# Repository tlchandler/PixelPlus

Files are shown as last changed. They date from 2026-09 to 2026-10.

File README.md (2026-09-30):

# PixelPlus

**A modern show player for Raspberry Pi pixel controllers.** PixelPlus plays the
Christmas (or any) light shows you design in [xLights](https://github.com/xLightsSequencer/xLights),
on Raspberry Pi based differential pixel controllers — with an interface built around your
**props**, not channels and universes.

It is a from-scratch replacement for Falcon Player (FPP) for the PixelPlus / Chandler board
family (difftx pHAT, 60-port difftxlarge, diffsmart smart receiver), and also runs on a bare
Pi or in Docker as a show director.

---

## Why PixelPlus

| | |
|---|---|
| **Props, not universes** | Import your xLights layout and every prop shows up by name, wired to its controller, jack, receiver and port — in plain language ("Main Controller › J1 › Front Yard receiver › Port 2 › pixels 51–100"). You never type a start channel. |
| **Configure once, on the leader** | One Pi is the show leader. New controllers appear on their own; click **Adopt** and they receive their props, settings and their slice of every sequence automatically — and stay in sync to within a frame. |
| **Easy to change** | Every setting is edited in place and saved automatically, with Undo. Every change is versioned; **Backups** restore the whole show in one click. |
| **Setup that just works** | Put your Wi-Fi in `pixelplus.txt` on the SD card, use Raspberry Pi Imager's settings, or use the **PixelPlus Imager** app. No Wi-Fi? The Pi opens a `PixelPlus-XXXX` hotspot with a friendly Wi-Fi picker. |
| **Made for the yard at night** | Dark "studio" interface that works beautifully on a phone: big touch targets, live preview of your whole display, test and fault-find any prop from where you stand. |
| **No artificial limits** | Up to ~1600 pixels per output at 20 fps (800 at 40 fps) on every output, 60 outputs on the difftxlarge. |

## Features

- **Live dashboard** — now playing, next show countdown, pre-show health check, controller
  health, temperatures, 12 V voltage/current (difftxlarge), song requests.
- **Props** — grid and list views with live mini-previews, groups, bulk edit, drag-to-reorder
  daisy chains, reverse runs, dark spacer pixels, color order, brightness and color correction
  per port, power estimates against your receiver fuses.
- **Test & fault finder** — solid/chase/count/walk patterns on any prop or port; a guided
  "is it lit?" binary search finds the first bad pixel in a handful of taps.
- **Layout** — a live 2D picture of your whole display while the show plays.
- **Sequences & audio** — drag-and-drop upload, automatic song matching, volume leveling,
  thumbnails; plays xLights `.fseq` v1/v2 (zstd, zlib, sparse).
- **Playlists** — songs, DJ clips, looks, pauses and commands; intro/outro, shuffle, repeat,
  crossfades.
- **Schedule** — show windows by day and season, times relative to sunset, special nights
  that take over, idle looks between shows, a neighbor-friendly volume curfew.
- **DJ Studio** — radio-style announcements with Kokoro voices (Nick & Holly included, or
  blend your own), multi-voice scripts, hype levels, live info ("{days until Christmas}",
  "next up: {song}") re-rendered at showtime. Renders on a Pi 4/5 or right in your browser.
- **Effects** — 13 built-in effects and 15 ready-made looks for idle time and quick tests,
  identical on every controller.
- **Games** — visitors play Super Mario Bros. (or an NES arcade) on your pixel matrix using
  their phone as the controller, with QR invites flashed on the matrix.
- **Song requests** — a public page (with QR code and printable yard sign) where visitors pick
  the next song.
- **Alerts & integrations** — email and push (ntfy) alerts, MQTT with Home Assistant
  discovery, physical button triggers, OLED status screen.
- **Only what you use** — Settings → Features turns optional parts on and off (presets:
  Essentials, Everything, Custom), so menus and pages show just what this display uses.
  Nothing is deleted; turned-off features stop their background work and their playlist items
  are skipped.
- **Secure by default** — optional password, per-controller keys with signed cluster
  traffic, hardened against hostile uploads and cross-site attacks.

**New in this release**

- **Light shows from music** — beat, tempo and energy analysis builds a show for your props
  in one click, in six styles; preview any sequence on your phone without touching the lights.
- **Sync lights to sound** — your phone's camera and microphone measure the audio delay; a
  built-in certificate authority gives phones the HTTPS they need, with a one-page trust guide.
- **Countdown to showtime** — a matrix countdown with the first song starting exactly on the
  scheduled minute, on every controller.
- **Map my yard** — film the house with your phone and PixelPlus finds where each prop is and
  which runs are swapped or reversed; plus a pixel-count check and a guided receiver wizard.
- **Smart playlists** — tags, rules and nightly rotation pick tonight's songs without repeats.
- **Seasons** — keep Halloween and Christmas shows side by side and switch by date.
- **Power limiter** — keeps every fuse and supply within its rating on every controller, plus
  late-night dimming.
- **Nightly report** — how last night went, every morning, by email or push.
- **Upload from xLights** — FPP Connect compatible, or a drop folder.
- **Sensors and surprises** — ESP32 motion, button and beam sensors set off effects layered
  over the song that's playing.
- **Remote access** — Tailscale or Cloudflare Tunnel without port forwarding; only the request
  page and games go public, with per-visitor limits and an alert on every remote sign-in.
- **Fleet care** — signed updates for every controller at once with automatic rollback, and
  one-step replacement of a dead controller or leader from an encrypted transfer file.

## Getting started

1. **Make an SD card** — see [docs/INSTALL.md](docs/INSTALL.md) (PixelPlus Imager,
   Raspberry Pi Imager, or any writer + `pixelplus.txt`).
2. **Open** `http://pixelplus.local` (or the name you chose) and follow the setup wizard.
3. **Import** your xLights layout, **upload** sequences, **build** a playlist and **schedule** it.

Running the leader on a PC or NAS: see [docker/README.md](docker/README.md).

## Hardware

| Board | Outputs | Notes |
|---|---|---|
| **difftx** (PixelPlus pHAT) | 4 on one RJ45 | Pi Zero 2 W outline. Rev D needs a 4/5-swapped patch lead on port 3 (PixelPlus warns you). |
| **difftxlarge** | 60 on 15 RJ45 | 3 latch banks, INA226 power monitor, 2× LM75, DS3231 RTC, optional OLED. |
| **diffsmart** | 4 direct | Runs PixelPlus in standalone (PI) mode; set SW1 to **PI**. |
| **diffrx** | receiver | Passive 4-port differential receiver (no Pi). |

Supported Pis: Zero 2 W, 3, 4, 5 (64-bit Raspberry Pi OS Bookworm or Trixie). Pixel output
uses the Pi's DPI peripheral with an original WS281x encoder — see
[crates/pixelplus-output/DESIGN.md](crates/pixelplus-output/DESIGN.md), including a
**bring-up checklist** for first hardware tests.

## Repository layout

```
crates/pixelplus-core     show model, fseq, xLights import, mapping, effects, schedule
crates/pixelplus-output   DPI WS281x encoder (direct + latched), output backends
crates/pixelplus-hw       board detection, EEPROM, sensors, RTC, OLED, GPIO
crates/pixelplus-daemon   pixelplusd: API, playback engine, scheduler, cluster, services
crates/pixelplus-cli      pixelplus: detect, eeprom, test-output, config-txt, doctor
web/                      SvelteKit web interface (demo mode: add ?mock=1)
tts/                      Kokoro DJ voice service
games/                    phone-controlled matrix games
image/ packaging/ docker/ Raspberry Pi image, Debian package, Docker
imager/                   PixelPlus Imager desktop app
docs/                     ARCHITECTURE, INSTALL, BUILDING
scripts/                  dev-cluster.sh (local leader + 2 followers), e2e tests
```

## Development

See [docs/BUILDING.md](docs/BUILDING.md). Quick start:

```sh
cargo test --workspace                  # Rust
cd web && pnpm install && pnpm dev      # UI (demo mode when no daemon is running)
scripts/dev-cluster.sh start --fresh    # a real leader + 2 followers on your PC
node scripts/e2e/run.mjs                # the full end-to-end scenario
```

The design authority is [docs/ARCHITECTURE.md](docs/ARCHITECTURE.md) (multi-controller timing:
§7.4); board-level timing notes for future hardware revisions are in
[docs/HARDWARE-NOTES.md](docs/HARDWARE-NOTES.md).

## License

PixelPlus is free software under the [GNU General Public License v3.0 or later](LICENSE).
It contains no code from FPP's CC-BY-ND licensed components.
Nintendo and Super Mario Bros. are trademarks of Nintendo; no Nintendo code or ROMs are included.

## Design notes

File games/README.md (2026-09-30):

# PixelPlus Games

Let people walking by your Christmas display play **Super Mario Bros. on your pixel matrix**,
using their phone as the controller. A sidecar service for `pixelplusd`, ported from
[tlchandler/fpp-mariobros](https://github.com/tlchandler/fpp-mariobros).

* During the show, the matrix flashes your URL (text and/or a QR code) every few minutes.
* A visitor opens it and gets an NES-style gamepad that says **PRESS START TO BEGIN**.
* On START, the show pauses, a **random level** plays on the matrix for **60 seconds** with the
  game's **music and sound effects on your show audio**, then the show resumes exactly where it was.
* A **cooldown** then keeps the matrix on the show for a while: no invites, no new games.
* Mario wears a **Santa hat**.
* Optional **Arcade mode**: a full-time NES emulator. The matrix lists every game you uploaded
  (with a scroll bar), visitors take turns picking and playing any of them.

Everything is configured in the PixelPlus web UI: the **Games** page.

## What you need

* PixelPlus on the leader that drives the matrix.
* A **matrix prop** (Props → a prop of kind *matrix* with its grid). xLights imports fill in the
  grid automatically; it can also be edited in the prop drawer.
* Your own backup of **Super Mario Bros.** as a `.nes` file (not included, and never sent to
  visitors — the game runs on the Pi; phones only send button presses). Arcade mode lists every
  `.nes` file you upload.
* A way for phones on the street to reach the controller page (see below).

## Install

PixelPlus images ship with the games service installed. To add it by hand (Raspberry Pi OS /
Debian), from a checkout of the repository:

```sh
sudo games/install.sh
```

It installs `libretro-nestopia` (the NES emulator), `python3-numpy`, `python3-qrcode` and
`alsa-utils` with apt, copies the program to `/usr/lib/pixelplus/games`, creates
`/var/lib/pixelplus/games/roms/` and enables `pixelplus-games.service`
(`--help` lists the options). Logs: `journalctl -u pixelplus-games -f`.

The service runs as the unprivileged `pixelplus` user (the same user as `pixelplusd`, member
of `audio` for game sound), with the unit the `pixelplus` package ships
(`packaging/systemd/pixelplus-games.service`, identical to `games/pixelplus-games.service`).
It writes frames into the prop's overlay buffer `/dev/shm/pixelplus-overlay-<prop>` (created
by pixelplusd, mode 0660) and listens on the control socket `/run/pixelplus/games.sock`
(`/run/pixelplus` is created by tmpfiles.d, owned by `pixelplus`).

Then open the **Games** page in PixelPlus:

1. Upload your Super Mario Bros. ROM (stored as `/var/lib/pixelplus/games/roms/smb.nes`) and,
   for Arcade mode, any other `.nes` games (stored next to it).
2. Pick your **matrix prop** and press **Test pattern**: you should see a blue border, a red
   top-left corner, a green top-right corner and `MARIO 80X40` centred. If the corners are
   swapped, fix the prop's matrix orientation (start corner / direction) in the Props page.
3. Turn **Games** on, then open `http://<pi-address>:8088` on your phone (same Wi-Fi) and play a
   round.
4. Set the **Public URL** and **Show the invite every** (minutes; 0 = only when a playlist runs
   the `games.invite` command).

### Letting phones on the street reach it

Visitors are on mobile data, so the page must be reachable from the internet. Expose **only the
controller port** (default 8088), never PixelPlus's own web interface on port 80. The controller
page has no login by design: anyone who can reach it can queue for a turn, and that is all it can
do.

* **Cloudflare Tunnel** (recommended, free, no router changes, works with WebSockets and gives you
  HTTPS): install `cloudflared` on the Pi or another machine on your network and route a
  hostname such as `mario.yourdomain.com` to `http://<pi-address>:8088`. This is a third-party
  service you set up yourself; PixelPlus does not install it.
* **Port forward** on your router from an external port to `<pi-address>:8088`, plus a dynamic DNS
  name. Simpler, but plain HTTP and it puts your home IP in the URL.
* **Guest Wi-Fi** near the display (with the URL as `http://<pi-address>:8088`) if you'd rather
  not touch the internet at all.

What the controller port does to stay up with the whole internet able to reach it: only `/`,
`/ws` and `/healthz` exist; WebSocket messages are capped at 4 KiB and parsed defensively; a phone
may send about 60 messages a second (bursts to 120) and is disconnected if it keeps flooding; a
connection that stays silent for 2 minutes is closed (the page pings every 20 s); and one address
may hold at most 16 connections (300 in all). Behind Cloudflare Tunnel or another reverse proxy on
the Pi or the LAN, the visitor's address is taken from `CF-Connecting-IP` / `X-Forwarded-For`;
those headers are ignored on connections from the internet.

Short URLs read best on an 80×40 matrix (about 20 characters fit; longer ones scroll).

## Settings (the Games page)

Stored in the show as `settings.games` (`GameSettings` in `pixelplus-core`); changes apply live.

| Setting (`show.json` key) | Default | Notes |
|---|---|---|
| Games (`enabled`) | off | Master switch. Opens the controller port; off closes it and the arcade. |
| Controller port (`port`) | 8088 | |
| Matrix (`matrixPropId`) | — | Any prop with a matrix grid. If unset and the show has exactly one matrix prop, that one is used. |
| Game length (`gameSeconds`) | 60 s | 10–600. |
| Cooldown after a game (`cooldownMinutes`) | 5 min | No invites and no games during it; phones count down. |
| Levels (`levels`) | all | Or e.g. `1-1,1-2,4-1`; one is picked at random. |
| Games allowed (`playWindow`) | during the show | `duringShow`: while a show plays, is paused, or inside a schedule window. Or `anytime`. |
| Pause the show during a game (`pauseShow`) | on | Pauses the player and resumes it afterwards. |
| Santa hat on Mario (`santaHat`) | on | |
| Arcade mode (`arcadeMode`) | off | See below. |
| Turn length (`arcadeMinutes`) | 0 (unlimited) | Minutes; 0 = until the player leaves or goes idle. |
| End a turn after idle (`arcadeIdleSeconds`) | 600 s | 0 = never. |
| Public URL (`publicUrl`) | — | What the invite shows. |
| Show the invite every (`inviteEveryMinutes`) | 5 min | 0 = only via the playlist command. |
| Invite style (`inviteStyle`) | text | `text`, `qr`, or `alternate`. |
| Flashes each time (`inviteFlashes`) | 3 | |
| URL text colour (`inviteColor`) | red | |
| Picture fit (`scaleMode`) | fit | `fit` keeps Mario's proportions (black bars left/right); `stretch` fills. |
| Matrix frame rate (`outputFps`) | 40 fps | 20 or 40. The game itself always runs at 60. |
| Brightness / game volume (`brightness`, `volume`) | 100% / 80% | Game volume scales the game's own sound. |
| Crop (`crop`) | 8, 32, 256, 224 | Part of the NES screen shown in Mario mode (drops the score bar). |

The game's audio goes to the show's audio device (`settings.audio.device`). Use a device that
can be shared (`default`, a `dmix` or PipeWire device) if pixelplusd keeps the card open while
the show is paused.

A queued visitor has 20 s to press START when their turn comes (`turnTimeoutSeconds`, if the show
ever carries it). For unusual setups, environment variables in the service override the rest:
`PIXELPLUS_API` (default `http://127.0.0.1`), `PIXELPLUS_DATA_DIR`, `PIXELPLUS_GAMES_SOCKET`,
`PIXELPLUS_NES_CORE` (a specific libretro core), `PIXELPLUS_NES_CORE_OPTIONS`
(`key=value;key=value`), `PIXELPLUS_GAMES_DEBUG=1`.

### Playlist, schedule and trigger commands

* **`games.invite`** (`args: {flashes?, style?}`): flash the URL / QR now. Ignored during a game,
  the arcade or the cooldown.
* **`games.stop`**: end the current game or arcade turn.

## How a turn works

1. The phone connects over a WebSocket and shows **PRESS START TO BEGIN**.
2. START: if nobody is playing the visitor plays now, otherwise they join a line and their phone
   shows their place. When it's their turn their phone buzzes and they have 20 s to press START.
3. The show is paused, the overlay is switched on for the matrix prop, `WORLD 4-2` shows on the
   matrix while the emulator boots straight into that level (the level is chosen by writing the
   game's World/Level/Area bytes at the title menu, exactly like the game's own continue feature).
4. The game runs at the NES's 60 fps; the matrix gets 20 or 40 of those frames per second. START
   and SELECT are disabled so nobody can pause the matrix, lives are topped up, and the last ten
   seconds count down in the margin.
5. `TIME UP` and the score show, the overlay is switched off, the show resumes where it stopped
   (unless someone stopped it meanwhile), and the cooldown starts. If the player closes the page,
   their game ends after 10 s.

### The phone controller

* The pad fills the phone's screen, with the D-pad against the left edge and B/A against the right,
  where thumbs rest. Sideways gives the biggest buttons; upright works too.
* **Full screen** (top-right corner): on Android and desktop browsers it hides the browser bars and,
  on Android, locks the phone to landscape. iPhone Safari can't make a web page full screen, so on an
  iPhone the button explains **Share → Add to Home Screen** instead: opened from that icon, the
  controller fills the whole screen.
* One controller per phone: if the same browser opens the page a second time (another tab, or the
  home-screen icon), the older copy says so and waits for a tap instead of fighting over the turn.
* A keyboard works too: arrows/WASD, X/K = A, Z/J = B, Enter = START, right Shift = SELECT.

## Arcade mode

Turn on **Arcade mode** (with Games on) and the Pi becomes a full-time NES arcade:

* A playing show is stopped, and kept stopped: if the scheduler starts it, it is stopped again
  within a few seconds. Turn Arcade mode off to give the matrix back, then start your show as usual
  (it is not restarted automatically).
* The matrix shows **PICK A GAME** and the list of uploaded games, with a highlight bar, a scroll
  bar and scrolling for long names. Up/Down move (hold to repeat), Left/Right page, A or START plays.
* **Hold SELECT + START + B + A for 2 seconds** to leave a game and go back to the list.
* Turns (length and idle timeout configurable) and the line work as in Mario mode. Invites are off.

## Performance

The emulator has to finish every frame in under 16.7 ms. The service does what it can: the matrix
only gets 20 or 40 frames a second, frames that won't be shown aren't copied, and scaling is a
single precomputed gather. Measure on the Pi itself, ideally while the show is running:

```sh
cd /usr/lib/pixelplus/games
python3 -m pixelplus_games.benchmark /var/lib/pixelplus/games/roms/smb.nes 80x40
```

On a 2.1 GHz Xeon it reports ~0.4 ms to emulate and ~0.3 ms to scale a frame (≈3% of a core).
A Pi 4 is comfortable; on slower boards set the matrix frame rate to 20. The show is paused during
a game, which frees up CPU.

## How it talks to PixelPlus

The service runs next to pixelplusd, as its own user `pixelplus-games` (group
`pixelplus-overlay`, shared with pixelplusd), and talks to it over loopback. Every request
carries `X-PixelPlus-Local: <token>` — the random token pixelplusd writes to
`/run/pixelplus/local-token` at startup (`PIXELPLUS_LOCAL_TOKEN_FILE` overrides the path; the
file is re-read after a 401) — and `X-PixelPlus-Request: 1`. pixelplusd accepts the token only
from 127.0.0.1 / ::1, never through a proxy, and only for the calls below; the show it returns
has its passwords redacted. The control socket is `/run/pixelplus-games/games.sock`, and of the
data directory the service only sees `games/`.

| Call | Use |
|---|---|
| `GET /api/v1/show` | `settings.games`, `settings.audio.device` and the matrix prop's `matrix: {width, height, pixelMap}`. Refetched on every `{type:"show"}` message from `/api/v1/ws` (every 5 s if the WebSocket is down, every 60 s regardless). |
| `GET /api/v1/player` | `state` (and `scheduleEntry`) when no `status` message arrived for 5 s. |
| `POST /api/v1/player/pause`, `/player/resume`, `/player/stop` | Pause/resume around a Mario game; stop (and keep stopped) for the arcade. |
| `POST /api/v1/overlay/:propId/open` → `{shm, width, height}` | Shared-memory frame buffer: 12-byte header (width, height, flags as native-endian u32) + RGB row-major from the top-left. Each frame sets flags bit 0. |
| `PUT /api/v1/overlay/:propId/frame` | Fallback when the shared memory can't be used: raw RGB, width×height×3 bytes. |
| `POST /api/v1/overlay/:propId` `{enabled}` | On while a game, invite or test pattern is shown; off afterwards (and at startup, in case a previous run died). |

pixelplusd reaches the service through its control socket, `/run/pixelplus/games.sock`: one
JSON object per line each way, one request per connection.

| Request | Reply |
|---|---|
| `{"cmd":"status"}` | `{ok, enabled, running, arcade, queueLength, cooldownS, model:{width,height}\|null, player?:{phase, level?, score?, remaining?, game?}, lastError?, propId, clients, port, showState, busy, unavailable}` |
| `{"cmd":"invite","flashes":3,"style":"qr"}` | `{ok}` or `{ok:false, error}`. `flashes`/`style` optional (settings otherwise); `style` is `text`, `qr` or `alternate`; `url` and `force` (ignore cooldown / games off) also accepted. |
| `{"cmd":"stop"}` | `{ok, stopped}` |
| `{"cmd":"test"}` | `{ok}` or `{ok:false, error}`: test pattern for 6 s. |
| `{"cmd":"reload"}` | `{ok}`: refetch the show now. |

From a shell: `python3 -m pixelplus_games.ctl status|invite [flashes] [style]|stop|test|reload`.

## Development

No Pi needed. The tests use `tests/fake_pixelplus.py`, a stand-in for pixelplusd's API (it also
creates the overlay shared memory and serves `/api/v1/ws`), and a tiny homebrew ROM built on the
fly (no commercial ROM). Emulator tests are skipped when no libretro NES core is installed.

```sh
python3 -m unittest discover -s games/tests       # from the repository root
```

To run the whole service against the fake:

```sh
python3 games/tests/fake_pixelplus.py 18080 80 40 &
cd games && PIXELPLUS_API=http://127.0.0.1:18080 PIXELPLUS_DATA_DIR=/tmp/pp \
    PIXELPLUS_GAMES_SOCKET=/tmp/pp/games.sock python3 -m pixelplus_games
# open http://localhost:8088 ; put a ROM at /tmp/pp/games/roms/smb.nes
```

## Files

```
pixelplus_games/     the service (Python 3, standard library + numpy)
  server.py          HTTP/WebSocket server, player line, cooldown, invites, arcade turns, control socket
  api.py             pixelplusd HTTP client
  events.py          pixelplusd WebSocket listener (live settings and show state)
  config.py          paths, and settings.games from the show
  game.py            game sessions: pause/resume the show, the real-time emulation loop
  libretro.py        minimal ctypes frontend for a libretro NES core
  smb.py             Super Mario Bros. RAM map and level select
  hat.py             the Santa hat
  arcade.py          arcade game list
  display.py         scaling and writing to the overlay shared memory
  invite.py          URL / QR invite and test pattern
  font.py            3x5 pixel font
  audio.py           game sound through aplay
  benchmark.py       performance check
  ctl.py             control socket client
  www/controller.html  the phone gamepad
install.sh, pixelplus-games.service, requirements.txt
tests/               unit and integration tests, fake pixelplusd
```

Nintendo, Super Mario Bros. and NES are trademarks of Nintendo. This project is not affiliated
with Nintendo and contains no Nintendo code or graphics.

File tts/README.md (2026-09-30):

# PixelPlus TTS (`pixelplus_tts`)

On-device DJ voices for PixelPlus: a small loopback HTTP service (`127.0.0.1:7081`) that
renders multi-voice DJ clips with [Kokoro](https://github.com/hexgrad/kokoro) (82M, Apache-2.0)
through [kokoro-onnx](https://github.com/thewh1teagle/kokoro-onnx). It is a port of
[tlchandler/fpp-voices](https://github.com/tlchandler/fpp-voices), and it keeps that
project's tested sound:

* **Nick** (30% `am_echo` + 30% `am_fenrir` + 40% `am_puck`) and **Holly** (50% `af_heart` + 50% `af_kore`),
  and any custom blend (a weighted average of Kokoro style vectors).
* **Energy and hype that build to the end.** The punchline lands about 2–3 semitones above the lead-in,
  with wider pitch swings, a swell of about 2.5 dB, a soft pitch ceiling and a stretch for Holly. With
  praat-parselmouth installed it uses Praat PSOLA with the same algorithm and constants as fpp-voices;
  on a Raspberry Pi (no parselmouth wheels, see [Platforms](#platforms)) a simpler method gives the
  same lift, stretch and swell without the widened swings.
* Radio processing: highpass, per-voice EQ, presence for energetic lines, a de-esser and a compressor.
* Linear loudness normalization to **-16 LUFS** by default, with a true-peak-safe limiter.
* Pronunciation fixes (about 100 built in, plus the show's own list) and exact IPA overrides (`/noʊˈɛl/`).
* An optional music bed, ducked under the speech.

A check that the port is faithful: rendering `examples/show_intro.txt` with fpp-voices' `dj_voice.py`
and with this package, both at -16 LUFS, gives the same loudness (-16.0 / -16.0), the same length to
0.1 ms, and waveform correlation ≥0.99 per 2-second segment.

Runs on **Pi 4 / Pi 5 (64-bit OS) and Docker/x86**. **Pi Zero 2 W and Pi 3 use browser mode**
(`web/src/lib/tts-browser`, kokoro-js in the user's browser), because on-device renders there
would be many times slower than real time and the model barely fits in 512 MB–1 GB RAM.

---

## Platforms

Wheels on PyPI (checked 2026-09; `https://pypi.org/pypi/<package>/json`):

| Package | Linux x86_64 | Linux aarch64 (Pi OS Bookworm 3.11 / Trixie 3.13) |
|---|---|---|
| onnxruntime 1.30 | cp311–cp314 | cp311–cp314 (`manylinux_2_28`) |
| kokoro-onnx 0.6.1 | pure Python | pure Python (+ espeakng-loader `manylinux_2_28_aarch64`) |
| numpy 2.x | yes | yes |
| praat-parselmouth 0.4.7 | cp37–cp314 | **none** (source only: C++ build, hours under qemu) |

So `praat-parselmouth` is optional (`pip install '.[psola]'`, or it is tried automatically by
`install.sh`, the image build and the Docker image with `--only-binary`). Without it,
`pixelplus_tts/prosody.py` does the energy/hype prosody: the line is raised by the voice's energy
pitch, the punchline additionally by its lift (capped), slowed by its stretch and swollen by its
boost, with ffmpeg's `rubberband` filter (formants preserved) or, without it, a numpy phase vocoder.
`GET /health` reports the method in use as `prosody`: `psola`, `rubberband` or `basic`.

## Install

```bash
sudo ./install.sh                     # /opt/pixelplus-tts/venv, model into /var/lib/pixelplus/tts/models,
                                      # systemd unit pixelplus-tts.service (enabled + started)
sudo ./install.sh --variant fp16      # choose the model variant (see below)
sudo ./install.sh --no-service        # Docker / image builds
./install.sh --prefix ~/pp --data-dir ~/pp-data --no-service --no-apt   # unprivileged dev install
```

The script needs Python 3.10–3.13 (onnxruntime and kokoro-onnx don't support 3.14 yet). When run
as root it installs `ffmpeg` and `python3-venv` with apt if they're missing. If there's no system
ffmpeg, it installs the `bundled-ffmpeg` extra (imageio-ffmpeg) instead. Model files are
downloaded from the kokoro-onnx GitHub release (`model-files-v1.0`). Downloads resume from
`<file>.part` over HTTP Range, and each file is **sha256-verified** before it's moved into place.
Re-running the script is safe. For offline image builds, use `--models-mirror URL` or
`python -m pixelplus_tts download-models --base-url`.

Dev: `pip install -e '.[test,bundled-ffmpeg]' && pytest`. The integration tests run when the model is present in
`$PIXELPLUS_TTS_MODELS_DIR` (or `$PIXELPLUS_DATA_DIR/tts/models`) and are skipped otherwise.

### Model variant (per device RAM)

| Variant | File | Size | Resident after load | Peak while rendering | Speed (x86, measured) |
|---|---|---|---|---|---|
| **fp32** (default) | `kokoro-v1.0.onnx` | 310 MB | 455 MB | ~730 MB | RTF 0.34–0.39 model / 0.42–0.53 full pipeline |
| fp16 | `kokoro-v1.0.fp16.onnx` | 169 MB | 323 MB | ~680 MB | 0.27 model / 0.57–0.66 pipeline (varies) |
| int8 | `kokoro-v1.0.int8.onnx` | 88 MB | 193 MB | ~630 MB | **1.4–1.9 (3–4x slower)** |

`auto` picks **fp32** unless the board has < 1.5 GB RAM (Pi 4 1 GB), which gets **int8**.
The reasoning:

* fp32 is the reference quality, and all of fpp-voices' tuning was done with it.
* int8 (dynamic quantization) saves resident RAM but only about 100 MB of *peak* RAM. It is 3–4x slower
  on x86 because of the ConvInteger/MatMulInteger kernels, and it has no speed advantage on
  Cortex-A72 either (no `sdot`).
* On a Pi 4 with 2 GB RAM, fp32's ~730 MB peak fits alongside pixelplusd, and the model is unloaded
  after the idle time.
* fp16 is fast on CPUs with native fp16 or bf16 support. It is worth trying on a Pi 5 (Cortex-A76 has fp16
  arithmetic): `PIXELPLUS_TTS_MODEL=fp16` in `/etc/default/pixelplus-tts`, then measure with
  `python -m pixelplus_tts bench`.

Override the choice with `PIXELPLUS_TTS_MODEL=fp32|fp16|int8`, or with `install.sh --variant` (which
downloads that file). If `auto` picks a file that isn't present, the service uses whichever
variant is installed.

### Performance

Measured on this dev box (Xeon @2.1 GHz, 3 onnxruntime threads, fp32). A 12 s announcement takes
5–6 s through the whole pipeline (Kokoro, PSOLA energy, ffmpeg radio chain, loudness, MP3), so
RTF ≈ 0.45. The model loads in 1.1 s. A two-line Nick+Holly clip (4.9 s of audio) renders in 3.0 s.

These Pi figures are **estimates**, scaled from the x86 numbers and typical onnxruntime ARM
throughput; confirm them on the device with `python -m pixelplus_tts bench`:

| Device | Expected RTF (fp32) | A 10 s clip renders in | Mode |
|---|---|---|---|
| x86 desktop / NAS (Docker) | 0.2–0.5 | 2–5 s | device |
| Pi 5 (4× A76 2.4 GHz) | ~1.0–1.5 | ~10–15 s | device |
| Pi 4 (4× A72 1.5–1.8 GHz) | ~3–4 | ~30–40 s | device (render ahead of time) |
| Pi 3 / Pi Zero 2 W | ≫5, RAM-limited | minutes | **browser** |

Memory: the service uses about 36 MB while idle with no model loaded, about 730 MB at peak while rendering (fp32),
and about 155 MB after an idle unload (the onnxruntime and Praat libraries stay mapped; the model memory is
returned to the OS with `malloc_trim`). By default the model unloads after `PIXELPLUS_TTS_IDLE_MIN=10` minutes.
The unit runs at `Nice=10`, `CPUSchedulingPolicy=batch` and `IOSchedulingClass=idle`, and uses cores−1 threads,
so renders never starve the light output thread.

---

## HTTP API (`127.0.0.1:7081`, JSON, camelCase)

Errors use the pixelplusd error shape, `{"error": {"code", "message"}}`:

* 400 for `bad_request`, `unknown_voice`, `parse_error`, `forbidden_path`, `not_found` and `too_large`.
* 503 for `model_missing` and `busy` (four requests are already queued).
* 500 for `render_failed`.

Only one render runs at a time; other requests wait in a queue.

### `GET /health`
```json
{"ok": true, "version": "0.1.0", "modelLoaded": false, "modelAvailable": true, "device": "cpu",
 "modelVariant": "fp32", "threads": 3, "idleUnloadMinutes": 10, "renders": 0, "uptimeS": 12}
```
`modelAvailable: false` means the model files aren't downloaded, and renders return 503 `model_missing`.

### `GET /voices`
```json
{"base": [{"id": "af_heart", "name": "Heart", "language": "en-us", "gender": "female", "grade": "A"}, ...54 voices],
 "presets": [{"id": "nick", "name": "Nick", "description": "Male DJ - warm, upbeat, classic radio baritone",
              "blend": {"am_echo": 0.3, "am_fenrir": 0.3, "am_puck": 0.4}, "speed": 1.05, "lang": "en-us",
              "defaultEnergy": 0.4, "eq": "equalizer=f=150:t=q:w=1.0:g=2.5,equalizer=f=3200:t=q:w=1.2:g=2",
              "energy": {"pitch": 1.5, "range": 1.5, "speed": 1.0, "stretch": 1.0, "boost": 3, "lift": 3,
                         "ceiling": 3, "maxLift": 9}},
             {"id": "holly", ...}]}
```
`presets` are `DjVoice` objects that pixelplusd can seed into `show.djVoices`. `grade` is hexgrad's
published grade, given for the English voices only. Non-English voices (es, fr-fr, hi, it, ja, pt-br, cmn) are
best effort: kokoro-onnx phonemizes them with espeak-ng.

### `POST /render` → audio bytes
```jsonc
{
  "lines": [                                   // DjLine[]; voice = id or a DjVoice object
    {"voice": "nick", "text": "Good evening, and welcome to {showName}!", "pauseMs": 0},
    {"voice": "elf",  "text": "Only {daysUntilChristmas} days to go!", "pauseMs": 600, "energy": 1},
    {"voice": {"id": "tmp", "blend": {"af_bella": 0.6, "af_sky": 0.4}}, "text": "Up next, *{nextSong}!*", "energy": 1.5}
  ],
  "voices": [ /* optional DjVoice[] that lines may reference by id or name, e.g. show.djVoices */ ],
  "speed": 1.0,                                // DjClip.speed, 0.5–2.0, multiplies each voice's own speed
  "pronunciations": [{"word": "Griswold", "say": "Griz wold"}, {"word": "Noel", "say": "/noʊˈɛl/"}],
  "builtinPronunciations": true,               // also apply the ~100 built-in fixes (default true)
  "placeholders": {"showName": "the Chandler Family light show", "daysUntilChristmas": 12, "nextSong": "Feliz Navidad"},
  "format": "mp3",                             // mp3 (192k) | wav (s16) | ogg; always 44.1 kHz stereo
  "loudnessLufs": -16,                         // pass ShowSettings.audio.targetLufs
  "fx": true,                                  // radio chain + loudness (false = raw voice)
  "musicBed": {"path": "/var/lib/pixelplus/media/<id>.mp3", "duckDb": 12, "gainDb": -6, "introMs": 1500, "outroMs": 2500},
  "cache": true                                // reuse an identical earlier render (default true)
}
```
The response is `audio/mpeg`, `audio/wav` or `audio/ogg`, with these headers:

* `X-Duration-Ms`: the exact clip length. Store it in `Media.durationMs`.
* `X-Loudness-Lufs`: the measured loudness. Store it in `Media.loudnessLufs`.
* `X-Render-Ms`, `X-Cache: hit|miss` and `X-Model-Variant`.
* `X-Warnings`: a JSON array, for example unresolved placeholders.

Semantics:

* **pauseMs** is the silence *after* a line. `0` means the default 350 ms gap between lines, and no gap after
  the last line. A line with empty `text` is pure silence of `pauseMs`. This reproduces fpp-voices' `[pause N]` timing.
* **energy**: 0 calm, 0.4 normal DJ, 1 hype, 1.5 extra hype. When it's absent, the voice's `defaultEnergy`
  applies. On hype lines the punchline is the text in `*asterisks*`, otherwise the last phrase. Hype lines
  are also leveled up to 1.5 dB above the rest, as in fpp-voices.
* **voice** can be one of these:
  * a preset id, name or alias (`nick`/`male`/`m`/`he`, `holly`/`female`/`f`/`she`);
  * the id or name of an entry in `voices`;
  * a Kokoro id (`af_heart`);
  * an inline DjVoice.

  Blend weights are normalized. A voice without an `energy` block gets a neutral DJ tuning
  (pitch 1.5, range 1.5, lift 2.5, boost 3, ceiling 3, maxLift 8). `eq` may only use audio EQ/dynamics
  ffmpeg filters (such as `equalizer` and `highpass`); anything else is rejected.
* **pronunciations**: whole-word matching. Entries with a capital letter are case-sensitive, lowercase entries
  match any case, and the longest phrase wins. A `/.../` value is exact IPA, spliced into the phonemes.
  User entries override built-ins that have the same word.
* **placeholders**: `{name}` is replaced from the map. An unresolved name is spoken without braces
  ("next Song") and reported in `X-Warnings`. pixelplusd owns the values
  (`DJ_PLACEHOLDERS`: time, date, day, daysUntilChristmas, nextSong, prevSong, showName, temperature,
  sunset, requestName). Write them the way they should be spoken ("December 24th", "5:30 PM").
* **musicBed**: `path` must be under `$PIXELPLUS_DATA_DIR`. The bed is looped or trimmed to
  `introMs + speech + outroMs` and set to `loudnessLufs + gainDb`. Under speech it is ducked by `duckDb`
  (150 ms look-ahead, a hold across word gaps and a 600 ms release), faded in over 0.3 s and faded out over
  the outro. The whole mix is then normalized.
* Output (without a bed) starts with a 250 ms lead-in and ends with a 0.6 s tail, so a player never clips the first word.

### `POST /audition` → audio bytes
`{"voice": "af_heart" | DjVoice, "text"?: string, "energy"?: number, "speed"?: number, "format"?: "mp3"}`.
Without `text` the voice says *"Hi, I'm {name}! Welcome to the show. Now sit back, relax, and enjoy the lights!"*.
Results are always cached on disk. The cache key is a sha256 of the voice's sound-affecting fields, the text and settings,
the model variant and the package version, stored in `$PIXELPLUS_DATA_DIR/tts/cache` (LRU, `PIXELPLUS_TTS_CACHE_MB=200`).
A repeat audition returns in about 0 ms.

### `POST /parse`
`{"script": "nick: Hi!\nholly!!: Merry Christmas!\n[pause 1.0]", "voices"?: DjVoice[]}` →
`{"lines": [{"voice": "nick", "text": "Hi!", "pauseMs": 0}, {"voice": "holly", "text": "Merry Christmas!", "pauseMs": 1000, "energy": 1.5}]}`.
The script format is fpp-voices':

* `voice: text` for a line; `voice!:` means hype (1.0) and `voice!!:` means extra hype (1.5);
* `[pause 1.0]` (seconds; `1.5s` and `500ms` also work) adds silence;
* `# comment` lines are ignored;
* `*punchline*` marks the words hype builds into.

An unknown voice or a line without a colon returns 400 `parse_error` with the line number.
The same parser exists in TypeScript (`web/src/lib/tts-browser/script.ts`).

### `POST /warmup`, `POST /unload`, `GET /pronunciations`
`/warmup` loads the model now; call it about a minute before a dynamic clip is needed. `/unload` frees it.
`/pronunciations` returns the built-in list (`{builtin: [{word, say}]}`) for display in the UI.

---

## CLI (compatible with fpp-voices' `./say`)

```bash
python -m pixelplus_tts say nick "Good evening and welcome to the show!"
python -m pixelplus_tts say holly --hype "Sit back, relax, and enjoy the show!" -o hype.mp3
python -m pixelplus_tts say --script show_intro.txt -o show_intro.mp3 --music-bed bed.mp3
python -m pixelplus_tts say --list
python -m pixelplus_tts parse show_intro.txt          # -> DjLine JSON
python -m pixelplus_tts serve [--port 7081] [--idle-minutes 10] [-v]
python -m pixelplus_tts download-models [--variant auto|fp32|fp16|int8] [--models-dir DIR]
python -m pixelplus_tts bench                          # load time, RTF, RSS on this device
```
`say` options match fpp-voices: `-o`, `--script`, `--speed` (replaces the voice speed), `--energy`, `--hype`,
`--loudness` (default **-16** here, not -14), and `--no-fx`. It also adds `--pronunciations FILE` and `--music-bed FILE`.

## Configuration (environment)

| Variable | Default | |
|---|---|---|
| `PIXELPLUS_DATA_DIR` | `/var/lib/pixelplus` | models in `tts/models`, cache in `tts/cache` |
| `PIXELPLUS_TTS_HOST` / `_PORT` | `127.0.0.1` / `7081` | loopback only |
| `PIXELPLUS_TTS_MODEL` | `auto` | `fp32`, `fp16` or `int8` |
| `PIXELPLUS_TTS_IDLE_MIN` | `10` | unload the model after N idle minutes; 0 = never |
| `PIXELPLUS_TTS_THREADS` | cores − 1 | onnxruntime intra-op threads |
| `PIXELPLUS_TTS_CACHE_MB` | `200` | render and audition cache size; 0 disables it |
| `PIXELPLUS_TTS_MODELS_DIR`, `PIXELPLUS_TTS_CACHE_DIR` | derived | overrides |
| `PIXELPLUS_TTS_ALLOW_ANY_PATH` | off | allow music beds outside the data dir |

## Layout

```
pixelplus_tts/
  server.py    HTTP service (stdlib ThreadingHTTPServer)
  render.py    request validation, per-line chain, pauses, bed, loudness, cache
  engine.py    Kokoro load/idle-unload, blend styles, synthesize a line
  energy.py    energy/hype prosody (fpp-voices), pure helpers + Praat PSOLA
  prosody.py   energy/hype without Praat (rubberband or numpy phase vocoder) for aarch64
  audio.py     ffmpeg chains (in-memory pipes), loudness, ducking
  voices.py    base voice catalog, Nick/Holly presets, DjVoice normalization, blending
  pronounce.py pronunciation rules + IPA splicing
  script.py    script parser
  models.py    variants, per-device choice, resumable sha256-verified download
  data/voices.json, data/pronunciations.txt   (from fpp-voices)
install.sh, pixelplus-tts.service
```

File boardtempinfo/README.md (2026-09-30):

# Christmas PCBs

Each design has its own folder. The top of each folder is the current working copy (open the
`.kicad_pro` there); earlier revisions are frozen under `archive/`.

## Tools

All designs are developed in **KiCad 10.0**, installed at `C:\Program Files\KiCad\10.0\`:

| Binary | Path | Used for |
|---|---|---|
| KiCad | `C:\Program Files\KiCad\10.0\bin\kicad.exe` | opening the projects |
| kicad-cli | `C:\Program Files\KiCad\10.0\bin\kicad-cli.exe` | ERC/DRC, gerber and render export |
| KiCad Python | `C:\Program Files\KiCad\10.0\bin\python.exe` | running the `gen_*.py`, `export_jlc.py`, `verify.py` etc. scripts |

The scripts need KiCad's bundled Python (it provides `pcbnew`), so run them from the design's folder, e.g.

```
"C:\Program Files\KiCad\10.0\bin\python.exe" gen_pcb.py
```

## Designs

| Folder | Board | Current | Archived revisions |
|---|---|---|---|
| `difftx/` | FPP Remote pHAT — RS-422 transmitter on the Pi Zero 2 W outline | rev E (65 x 30 mm). Rev D, the one built, has port 3 reversed: see `CLAUDE.md` | `archive/revA`, `archive/revB`, `archive/revC_66mm`, `archive/revD` |
| `diffrx/` | Chandler 4D/8P Differential Receiver | work after rev C (board and `grid_router.py` changed since the release) | `archive/revB`, `archive/revC_release` |
| `diffsmart/` | Chandler 4D/8P Smart Receiver — diffrx rev C + Pi header, RX/TX mode switch | v1.00 | — |
| `difftxlarge/` | 60-output FPP transmitter — 15 × RJ45 (Falcon differential), 3 latch banks, RTC, power monitor, fan thermostat, line out | rev A (310 × 206 mm, not yet ordered) | — |

Each design's `VERIFICATION.md` has its check record; `jlcpcb/` holds the gerbers, BOM and CPL for ordering.

`repoint_3d_models.py` fixes 3D model paths that point at folders that no longer exist (the parts were first
downloaded under `Documents/jumperless/...`), repointing them at each design's own `jlc/jlc.3dshapes`. Run it
with `--apply`; without it, it only reports.

`_duplicates/` holds files that were byte-identical copies of `difftx/archive/revB` files left at the
top level (`fab/`, `difftx_pcb.pdf`). Safe to delete.

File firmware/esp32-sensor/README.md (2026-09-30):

# PixelPlus ESP32 sensor node

A small Wi-Fi board in the yard that tells your PixelPlus show about motion,
button presses, broken light beams and opened doors — and, optionally, how
much current a receiver's pixel supply draws. PixelPlus turns those into
**surprises**: a short sparkle on the candy canes when someone walks up the
driveway, "Jingle Bells" on the porch when the doorbell button is pressed,
without stopping the song that is playing.

- Boards: **ESP32-C3 DevKitM-1** (recommended), ESP32-S3 DevKitC-1, classic ESP32 DevKit.
- Inputs: up to 8 — PIR motion (HC-SR501, AM312), push buttons, IR break-beam
  pairs, reed/door contacts, and INA219/INA226 current sensors on I²C.
- Protocol: authenticated UDP on port **32422** to the show leader
  (`docs/ARCHITECTURE.md` §7.5, §12.16).

## Build and flash

You need [PlatformIO](https://platformio.org) (`pip install platformio`, or the VS Code extension).

```sh
cd firmware/esp32-sensor
pio run -e esp32c3 -t upload        # ESP32-C3 DevKitM-1 over USB
pio run -e esp32s3 -t upload        # ESP32-S3 DevKitC-1
pio run -e esp32dev -t upload       # classic ESP32 DevKit
pio device monitor                  # log at 115200 baud
pio test -e native                  # protocol and debounce tests on your PC
```

`esp32dev-classic` builds with the stock `espressif32` platform (Arduino-ESP32
2.x) if you can't use the pioarduino platform (Arduino-ESP32 3.x) the other
environments use.

## First start: Wi-Fi setup

1. Power the board. With no Wi-Fi saved it opens a hotspot named
   **PixelPlus-Sensor-XXXX** (the LED blinks **blue**).
2. Join it with your phone. The setup page opens by itself (or browse to
   `http://192.168.4.1`).
3. Pick the Wi-Fi your PixelPlus show uses, enter its password and a name
   ("Driveway", "Porch"), and tap **Save and connect**. The board restarts
   and joins your network (LED: a short **amber** blink every 2 s = waiting to
   be added).
4. In PixelPlus open **Settings → Sensors**. The board shows up under
   *New sensors found*; tap **Add**. The LED goes dark (adopted).
5. Name the inputs, set their pins, then create a trigger in
   **Settings → Triggers**: *When* "Driveway · Motion 1", *do* a surprise.

If the saved Wi-Fi disappears for 2 minutes the hotspot comes back (the
board keeps trying the saved network every minute and leaves the hotspot
once it works again).

### BOOT button

| Press | Effect |
|---|---|
| short (< 2 s) | allow a new show leader to adopt it for 10 minutes (LED blinks **purple**); also allows changing Wi-Fi from its status page |
| hold 10 s | factory reset: forgets Wi-Fi, show leader and settings |

### LED codes

| LED | Meaning |
|---|---|
| slow blue | setup hotspot is open |
| amber blink every 2 s | on Wi-Fi, not added to a show yet |
| fast white | "Identify" pressed in PixelPlus |
| purple | adoption window open (after a short BOOT press) |
| off | working normally (a short white flash on each trigger) |

## Wiring

All inputs are 3.3 V logic. **Never feed 5 V or 12 V into a GPIO.** Default
pins (a fresh node announces these; change them in Settings → Sensors):

| Board | Motion `pir1` | Button `btn1` | Beam | I²C SDA / SCL | BOOT | LED |
|---|---|---|---|---|---|---|
| ESP32-C3 DevKitM-1 | GPIO 4 | GPIO 5 | GPIO 7 | GPIO 1 / GPIO 3 | GPIO 9 | GPIO 8 (RGB) |
| ESP32-S3 DevKitC-1 | GPIO 4 | GPIO 5 | GPIO 6 | GPIO 8 / GPIO 9 | GPIO 0 | GPIO 48 (RGB) |
| ESP32 DevKit | GPIO 27 | GPIO 26 | GPIO 25 | GPIO 21 / GPIO 22 | GPIO 0 | GPIO 2 |

Avoid strapping pins (C3: 2, 8, 9; ESP32: 0, 2, 5, 12, 15) for inputs.

### PIR motion sensor (HC-SR501 or AM312)

```
 HC-SR501 (needs 5 V)            ESP32-C3 DevKitM-1
 ┌──────────────┐
 │ VCC ─────────┼──────────────── 5V
 │ OUT ─────────┼──────────────── GPIO 4      (3.3 V output: safe)
 │ GND ─────────┼──────────────── GND
 └──────────────┘
 AM312 mini PIR: VCC → 3V3 instead of 5V.
```

Kind **motion**, *active low* off. Turn the HC-SR501's "time" pot fully
counter-clockwise (shortest) and use PixelPlus' **hold** setting instead; set
its jumper to "repeat" (H). Outdoors, shade it from the street: car headlights
and warm exhaust trigger PIRs — test at night.

### Push button / doorbell

```
          ┌──── GPIO 5  (internal pull-up)
 button  ─┤
          └──── GND
```

Kind **button**, *active low* **on**. For long cable runs (> 5 m) add a
1 kΩ series resistor and a 100 nF capacitor from the GPIO to GND.

### IR break-beam pair (3 mm/5 mm, e.g. Adafruit 2167)

```
 Emitter: red → 3V3 (or 5V), black → GND
 Receiver: red → 3V3, black → GND, white (open collector) → GPIO 7
```

Kind **beam**, *active low* **off** (the receiver pulls low while the beam is
intact; the internal pull-up keeps it high when broken → PixelPlus sees
"active" when someone walks through). If your receiver works the other way,
toggle *active low*.

### Door / reed contact

```
 reed switch: one wire → GPIO, other → GND     (kind "contact", active low on)
```

### Current sensor on a receiver's pixel supply (INA226 / INA219)

Measures the real current of a receiver's 12 V pixel bus (the PixelPlus TX
board's own INA226 cannot see pixel current). Use an INA226 module with an
**external shunt** sized for the bus — the on-board 0.1 Ω shunt is only good
to ~0.8 A.

```
 12 V PSU (+) ──[ external shunt 75 mV/50 A = 1.5 mΩ ]── receiver 12 V (+)
                    │                        │
                 IN+ ┘                        └ IN-      INA226 module
 12 V PSU (−) ─────────────────────────────── GND ────── GND (shared with ESP32)
                                               VBUS ───── receiver 12 V (+)   (bus voltage)
 INA226 VCC → 3V3,  SDA → GPIO 1,  SCL → GPIO 3   (ESP32-C3)
 Address pins A0/A1 to GND → 0x40 (up to 16 modules: 0x40–0x4F)
```

In Settings → Sensors add an input of kind **current**: *pin* is the I²C
address (64 = 0x40) and *shunt* its resistance in milliohms (1.5 for
75 mV/50 A; 100 for a bare module). Remove the module's own R100 shunt when
you wire an external one. The node reports amps and bus volts every 10 s;
link the input to a power supply in Settings → Power so the limiter can use
the measured value.

> Safety: the shunt carries the full pixel current. Use wire and a fuse rated
> for it, keep the shunt on the **positive** side as drawn, and mount it
> inside the receiver's enclosure.

## How it talks to PixelPlus

- **Discovery**: a broadcast `sbeacon` every 2 s (10 s once adopted).
- **Adoption** (trust on first use): the leader POSTs
  `http://<node>/adopt {leaderId, leaderUrl, sensorPort, dh}`; the node
  answers `{id, dh, proof, hw, ver, inputs}`. Both sides compute
  `key = HMAC-SHA256(X25519 shared secret, "pixelplus-sensor-key-v1\n…")`;
  the key is stored in NVS and never sent. A node adopted by a show refuses
  other leaders until it is released, reset (BOOT 10 s), or a short BOOT
  press opens a 10-minute window.
- **Events / heartbeats**: `sevent` on every input change (retried at 100,
  200 and 400 ms until the leader's `sack`), `sstatus` every 10 s. Each
  datagram carries the node's boot id, a sequence number and an HMAC; the
  leader drops replays and events addressed to an older leader boot.
- **Configuration**: fetched from
  `GET <leader>/api/v1/cluster/sensor-config/<id>`, signed with the node key
  (`X-PixelPlus-Auth`) and answered with `X-PixelPlus-Reply`. The node
  refetches when a `sack` names a different config version.
- **Release**: the leader POSTs `/release` signed with the key.

Test vectors shared with the Rust leader: [`test/vectors.json`](test/vectors.json)
(generated independently in Python; checked by `pio test -e native` here and
by `cargo test` in `crates/pixelplus-daemon`).

## Troubleshooting

| Symptom | Try |
|---|---|
| Not listed in *New sensors found* | Same Wi-Fi/VLAN as the leader? UDP broadcast to port 32422 must reach it. The node's status page (its IP in your router) says whether it is on Wi-Fi. |
| "belongs to another show" | Release it on the other show, or short-press BOOT, then Add again. |
| Motion fires by itself | Shade the PIR, lower its sensitivity pot, raise *hold*, add a trigger *active window* and cooldown. |
| Events arrive late | Weak Wi-Fi (Sensors page shows dBm; below −75 dBm is poor). Move the node or add an access point. |
| Current reads 0 | Wrong I²C address or SDA/SCL swapped; the Sensors page shows no current until the module answers. |

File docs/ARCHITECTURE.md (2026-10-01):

# PixelPlus Architecture

PixelPlus is a modern, prop-oriented show player for Raspberry Pi pixel controllers.
It replaces Falcon Player (FPP) for the Chandler board family (difftx, difftxlarge,
diffsmart) and plays sequences created in xLights.

This document is the **design authority**. Every component (engine, UI, image,
tools) must follow the contracts here. Change this file first when a contract changes.

---

## 1. Principles

1. **Props, not channels.** Users never see universes, channels or start-channel
   math. They see *props* ("Left Arch", "Mega Tree") attached to *ports*.
   Channels exist internally only, as the byte offsets xLights wrote into `.fseq`.
2. **Configure once, on the leader.** Every setting lives on the leader. Followers
   are appliances: they announce themselves, get adopted, then automatically
   receive their config, their slice of every sequence, and all commands.
3. **Easy to change.** Every entity is editable in place in the UI; changes apply
   live without restarts. Every change is versioned (show snapshots).
4. **Safe by default.** Pre-show health checks, power estimation vs. fuse ratings,
   temperature alerts, and undo via snapshots.
5. **Works offline.** No cloud dependency. Everything (including TTS on Pi 4/5 or
   in the browser) runs locally.

---

## 2. Components

```
repo/
├── crates/
│   ├── pixelplus-core      # data model, fseq, xLights import, mapping, effects, power estimation
│   ├── pixelplus-output    # WS281x DPI framebuffer encoder (+latch banks), output backends
│   ├── pixelplus-hw        # board detection, EEPROM format, sensors (LM75/INA226/DS3231), OLED
│   ├── pixelplus-daemon    # `pixelplusd`: HTTP/WS API, playback, scheduler, audio, cluster sync,
│   │                       #   alerts, MQTT, snapshots, health checks, DJ/TTS orchestration
│   └── pixelplus-cli       # `pixelplus`: admin CLI (eeprom write/read, status, test patterns, doctor)
├── web/                    # SvelteKit SPA (static build served by pixelplusd)
├── tts/                    # Kokoro TTS sidecar (Python, kokoro-onnx) for Pi 4/5 & Docker
├── image/                  # pi-gen stage + first-boot, Wi-Fi config, hotspot captive portal
├── imager/                 # PixelPlus Imager desktop flasher (Tauri)
├── docker/                 # Docker image for running a leader on a PC/NAS
└── docs/                   # user & developer documentation
```

Runtime on a Pi:

```
systemd: pixelplusd.service  (Rust, realtime-priority output thread)
         pixelplus-tts.service (optional, Pi 4/5 only, loopback HTTP :7081)
         NetworkManager (Wi-Fi / hotspot), avahi (mDNS: <hostname>.local)
data:    /var/lib/pixelplus/  (see §6)
config:  /boot/firmware/pixelplus.txt (first-boot settings, human editable)
```

`pixelplusd` listens on **TCP 80** (HTTP + WebSocket; UI + API), **UDP 32420** (cluster
sync; overlay frames on **32421**), and — once their features land — **TCP 443** (HTTPS, §12.1;
8443 in Docker), **UDP 32422** (ESP32 sensor nodes, §12.16) and **127.0.0.1:8081** (public-only
listener for tunnels, §12.12). The cluster used UDP 32320 before; that is FPP's multisync
port, which xLights *FPP Connect* pings, so it moved (§7.4.1). Environment
`PIXELPLUS_HTTP_PORT`, `PIXELPLUS_CLUSTER_PORT`, `PIXELPLUS_SENSOR_PORT`,
`PIXELPLUS_HTTPS_PORT`, `PIXELPLUS_PUBLIC_PORT` (0 = off), `PIXELPLUS_DATA_DIR`,
`PIXELPLUS_OUTPUT=dpi|sim|none` override defaults (used by Docker and dev).

---

## 3. Hardware model

### 3.1 Boards (`BoardKind`)

| id | Name in UI | Outputs | Output labels | Notes |
|---|---|---|---|---|
| `difftx` | PixelPlus pHAT (difftx) | 4 | `Port 1`–`Port 4` on one RJ45 | rev D (EEPROM rev `D`/cape version 1.0) needs a 4/5-swapped lead on port 3 — show warning |
| `difftxlarge` | 60-Port Transmitter (difftxlarge) | 60 | `J1-1`…`J15-4`, 15 RJ45 jacks, 3 latch banks | INA226 12 V V/A, 2×LM75, DS3231 RTC, optional SSD1306 OLED |
| `diffsmart` | Smart Receiver — standalone (diffsmart) | 4 | `Out 1`–`Out 4` screw terminals | 2×LM75. Only runs PixelPlus in standalone (PI) mode; UI reminds user to set SW1 to **PI** |
| `bare-pi` | Raspberry Pi (no board) | 0 | – | Show director/audio only |
| `virtual` | Virtual (Docker / PC) | 0 | – | Leader on PC/NAS; `sim` output |

Board GPIO maps (BCM). The DPI framebuffer bit *n* drives GPIO *n+4*.

* **difftx / diffsmart**: Port1=GPIO5 (bit1), Port2=GPIO6 (bit2), Port3=GPIO7 (bit3), Port4=GPIO4 (bit0).
* **difftxlarge**: data lines D0..D19 = GPIO4..23 (bits 0..19). Latch enables LE0=GPIO27 (bit 23),
  LE1=GPIO26 (bit 22), LE2=GPIO25 (bit 21). Output k (0-based): bank = k/20, bit = k%20,
  jack = k/4+1, port = k%4+1. Label `J{jack}-{port}`.

### 3.2 Receivers

Receivers are *passive* things attached to a transmitter jack; they are modelled so the
UI can show "Garage receiver → Port 3 → Candy Canes".

| id | Name | Ports |
|---|---|---|
| `diffrx` | Chandler 4D/8P Differential Receiver | 4 |
| `diffsmart-rx` | Chandler Smart Receiver (RX mode) | 4 |
| `generic-4` | Generic 4-port differential receiver (Falcon/Kulp style) | 4 |
| `direct` | Direct (no receiver, e.g. diffsmart own outputs) | 1 per output |

A receiver on transmitter jack *J* maps receiver port *p* (1–4) to transmitter output
`(J-1)*4 + p`. For difftx there is one jack.

### 3.3 PixelPlus EEPROM format (`PPX1`)

Our boards carry an AT24C256 at i2c-1 0x50. PixelPlus uses its own simple format
(not FPP-compatible):

```
offset 0   magic      "PPX1"             4 bytes
offset 4   length     u16 LE             length of JSON payload
offset 6   crc32      u32 LE             CRC-32 (IEEE) of JSON payload
offset 10  json       UTF-8 JSON         {"board":"difftx","rev":"E","serial":"PPX-...","made":"2026-10-01","notes":"..."}
```

Unknown/blank EEPROM (0xFF) → user is asked to pick the board in the setup wizard; the
wizard offers to write the EEPROM. `pixelplus eeprom write --board difftx --rev E`
does the same from the CLI.

### 3.4 Pixel output (DPI)

All boards drive WS281x (800 kHz) via the Pi's DPI peripheral in 24-bit mode clocked
at 38.4 MHz (see `crates/pixelplus-output/DESIGN.md`). PixelPlus has **no artificial
pixel limits**. Practical limit per output ≈ 1600 px at 20 fps / 800 px at 40 fps.
Implementation is original (FPP's DPIPixels is CC-BY-ND and must not be copied); see
`crates/pixelplus-output/DESIGN.md`. The maximum string length is fixed at boot by the DPI overlay's
vertical size: the daemon sizes it from the longest configured string (`DpiGeometry::for_pixels`),
regenerates the config.txt fragment and asks the user to reboot (health check + banner in the UI).

**When a frame lights up.** The display scans out on a free-running vblank grid (refresh
R = 24.8 ms at 800 px, 49.3 ms at 1600 px) and a string of L LEDs latches L × 30.6 µs + 0.28 ms
after scan-out starts. The DPI backend reports every page flip's vblank sequence and
CLOCK_MONOTONIC timestamp (`PixelOutput::present_timing`, `VblankModel`); the player paces its
output thread from that grid and chooses each frame for the moment it actually lights up (§7.4.6).
Optional, experimental: `settings.output.latchAlign` bottom-aligns every string's data so all
strings on a controller latch together (DESIGN.md "Latch alignment").

---

## 4. Show model (JSON; Rust types in `pixelplus-core::model`)

All ids are short random strings (`nanoid`-style, 10 chars, `[a-z0-9]`). All entities
have `id`, `name`, and optional `notes`. JSON uses camelCase.

```ts
Show {
  version: number              // monotonically increasing revision, bumped on every change
  name: string
  nodes: Node[]
  receivers: Receiver[]
  props: Prop[]
  propGroups: PropGroup[]
  sequences: Sequence[]
  media: Media[]               // audio files (songs, DJ clips, rendered TTS)
  djClips: DjClip[]
  djVoices: DjVoice[]          // custom voices (blends); built-ins "nick" & "holly" seeded on first run
  pronunciations: {word: string, say: string}[]   // whole-word fixes; say = sound-alike or /IPA/
  effects: EffectPreset[]      // built-in effect presets ("looks")
  playlists: Playlist[]
  schedule: Schedule
  settings: ShowSettings
}

Node {                          // a Pi running PixelPlus
  id, name, hostname
  role: "leader" | "follower"
  board: BoardKind              // detected or chosen
  boardRev?: string
  piModel?: string              // e.g. "Raspberry Pi 4 Model B Rev 1.5" (reported)
  outputs: OutputConfig[]       // length = board output count
  adopted: boolean
  lastSeen?: string             // ISO time (runtime, not persisted meaningfully)
}

OutputConfig {
  index: number                 // 1-based
  label: string                 // "J3-2"
  pixelType: "ws2811"           // 800 kHz WS281x family (WS2811/2812/2815)
  colorOrder: "RGB"|"RBG"|"GRB"|"GBR"|"BRG"|"BGR"
  brightness: number            // 0..100 (%)
  gamma: number                 // 1.0 = none, 2.2 typical
  enabled: boolean
}

Receiver {
  id, name, kind: "diffrx"|"diffsmart-rx"|"generic-4"|"direct"
  nodeId: string, jack: number  // transmitter jack it is plugged into (1-based)
  location?: string             // "Garage", "Front porch"
  fuseAmps?: number             // per-port fuse rating for power warnings (diffrx: 6)
}

Prop {
  id, name
  kind: "arch"|"candycane"|"tree"|"matrix"|"line"|"circle"|"star"|"spinner"|"window"|"icicles"|"custom"|"other"
  pixelCount: number
  xlightsModel?: string         // source model name in xLights layout
  channelStart: number          // 0-based byte offset into the fseq frame (internal; never shown as "channel");
                                //   with channelRuns: the lowest byte offset of any run
  channelsPerPixel: 3           // 3 = RGB (only RGB supported for now)
  channelRuns?: ChannelRun[]    // non-contiguous channels (xLights individual/"Advanced" start channels);
                                //   absent = contiguous from channelStart. Set by the importer, read-only in the UI.
  segments: PropSegment[]       // where the pixels physically are (in order)
  groupIds: string[]
  layout?: PropLayout           // 2D preview geometry
  color?: string                // UI accent color for the prop
  maxMilliampsPerPixel?: number // default 60 (full white 12V 3-LED pixel ≈ 20mA*3)
}

ChannelRun {                    // prop pixels whose channels are contiguous in the fseq frame (one xLights string)
  propOffset: number            // 0-based index of the run's first prop pixel
  channelStart: number          // 0-based byte offset of that pixel in the fseq frame
  pixelCount: number
}

PropSegment {                   // a run of consecutive prop pixels on one output
  nodeId: string
  output: number                // 1-based node output index
  startPixel: number            // 0-based pixel position on that output (after nulls)
  pixelCount: number
  propOffset: number            // 0-based index into the prop's pixels where this segment starts
  reverse: boolean
  nullPixels: number            // null pixels before this segment on the output (informational + mapping)
}

PropLayout { x: number, y: number, w: number, h: number, rotation: number, points?: [number,number][] }
// Coordinates: y-down canvas ("world units"; imported layouts keep xLights world units). x,y = top-left of the
// box, rotation = degrees clockwise around the box centre, points normalized with [0,0] = top-left of the box.
// points = normalized (0..1) per-pixel positions within the w×h box; if absent, derived from `kind`.

PropGroup { id, name, propIds: string[], color?: string }

Sequence {
  id, name
  file: string                  // relative path under data dir: sequences/<id>.fseq
  durationMs: number, frameMs: number, channelCount: number
  mediaId?: string              // linked audio
  xlightsName?: string          // original filename
  thumbnail?: string            // generated preview strip (PNG under data dir)
}

Media { id, name, kind: "song"|"dj"|"sfx", file, durationMs, loudnessLufs?: number, gainDb?: number }

DjClip {
  id, name
  lines: { voice: string, text: string, pauseMs: number, energy?: number }[]   // multi-voice dialog; voice = DjVoice id or kokoro voice id; energy 0 calm .. 0.4 normal .. 1 hype .. 1.5 extra hype
  dynamic: boolean              // contains {placeholders}; re-rendered at showtime (Pi 4/5 / Docker only)
  mediaId?: string              // last rendered audio
  speed: number                 // 0.5..2.0
  musicBedMediaId?: string      // optional background bed, ducked under speech
}
// Placeholders: {time} {date} {day} {daysUntilChristmas} {nextSong} {prevSong}
//               {showName} {temperature} {sunset} {requestName}

DjVoice {                      // same shape as tlchandler/fpp-voices voices.json entries
  id, name, description
  blend: Record<string, number> // kokoro voice id -> weight, e.g. {am_echo:.3, am_fenrir:.3, am_puck:.4}
  speed: number, lang: string, eq?: string, defaultEnergy: number
  energy: {pitch, range, speed, stretch, boost, lift, ceiling, maxLift}
}

EffectPreset {
  id, name
  effect: "solid"|"chase"|"twinkle"|"rainbow"|"colorwash"|"candycane"|"fire"|"snow"|"sparkle"|"wave"|"meteor"|"strobe"|"breathe"
  params: Record<string, number|string|boolean|string[]>  // e.g. {colors:["#ff0000","#ffffff"], speed:1.0, density:0.3}
  target: { all?: boolean, propIds?: string[], groupIds?: string[] }
}

Playlist {
  id, name
  items: PlaylistItem[]
  intro?: PlaylistItem[]        // played once at start
  outro?: PlaylistItem[]        // played once at end
  shuffle: boolean
  repeat: boolean
  crossfadeMs: number           // 0 = gapless cut
}

PlaylistItem =
  | { id, type: "sequence", sequenceId }
  | { id, type: "dj", djClipId }
  | { id, type: "effect", effectId, durationMs }
  | { id, type: "media", mediaId }                 // audio only
  | { id, type: "pause", durationMs }
  | { id, type: "command", command: string, args?: any }   // e.g. games.invite, overlay.text

Schedule {
  enabled: boolean
  location: { lat: number, lon: number, timezone: string, label?: string }
  entries: ScheduleEntry[]
  idleEffectId?: string         // look shown inside show windows when nothing plays / between entries
  offEffectId?: string          // null = dark outside show windows
  volumeCurfew?: { time: TimeSpec, volume: number }   // lower volume after e.g. 9pm
}

ScheduleEntry {
  id, name, enabled: boolean
  playlistId: string
  days: ("mon"|"tue"|"wed"|"thu"|"fri"|"sat"|"sun")[]
  dateRange?: { start: "MM-DD", end: "MM-DD" }   // wraps year end (e.g. 11-25 .. 01-06)
  start: TimeSpec, end: TimeSpec
  priority: number              // higher wins on overlap (special nights > regular)
  endBehavior: "finishSong"|"stopNow"|"fadeOut"
}
TimeSpec = { kind: "clock", time: "HH:MM" } | { kind: "sunset"|"sunrise", offsetMin: number }

ShowSettings {
  audio: { device: string, volume: number, normalize: boolean, targetLufs: number,
           outputDelayMs?: number }   // lights delayed by this (−500…2000 ms), §7.4.7
  output?: { latchAlign: boolean }    // experimental: all strings latch together, §3.4
  alerts: { email?: {smtpHost, smtpPort, username, password, from, to, tls}, ntfy?: {server, topic}, rules: {tempC: number, voltageMin: number, followerOffline: boolean, showFailure: boolean} }
  mqtt: { enabled: boolean, host, port, username?, password?, baseTopic: string, homeAssistantDiscovery: boolean }
  requests: { enabled: boolean, maxQueue: number, playlistId?: string, title: string, message: string }
  tts: { mode: "auto"|"device"|"browser" }
  oled: { enabled: boolean }
  security: { passwordHash?: string }
  triggers: { id, name, kind: "gpio"|"http", gpio?: number, action: {type: "playPlaylist"|"playSequence"|"stop"|"effect", ref?: string} }[]
}
```

### 4.0 Feature-wave additions (compatibility)

Every field below is `#[serde(default)]`; optional ones are omitted while empty, so a
`show.json` from an older version loads unchanged and saves with only these new keys:
`formatVersion` and `settings.{https,reports,power,remote,updates,xlights,features}` (test:
`crates/pixelplus-core/tests/show_compat.rs`, fixture `testdata/show-head-2026-09.json`).
Details per feature in §12.

```ts
Show += { formatVersion: number /*1*/, profiles?: ShowProfile[], activeProfileId?, profileAutoSwitch?,
          powerSupplies?: PowerSupply[], tagDefs?: {name, color?}[], sensorNodes?: SensorNode[] }
Node += { serial?, hardwareHistory?: {at, serial?, board, piModel?, reason}[] }                 // §12.9
OutputConfig += { measuredPixels?: {count, method:"camera"|"manual"|"current", at, dead?: number[]} } // §12.6
Receiver += { mainFuseAmps? }                                                                   // §12.11
Prop += { suspectPixels?: number[] }                                                            // §12.6
PropLayout += { source?: "xlights"|"manual"|"camera" }                                          // §12.5
Sequence += { generated?: {kind:"autoShow"|"voice", mediaId, style, propIds, seed, analysisVersion, propsHash}, tags? }
Media += { analysis?: {version, bpm, bpmConfidence, beatCount, firstBeatMs, energy, sections}, tags?,
           originalName?, originalSize? }
EffectPreset.effect += "countdown"                                                              // §12.4
PlaylistItem += { id, type:"countdown", durationMs, matrixPropId?, text?="{s}", color?,
                  others?:"fill"|"pulse"|"dark", finale?:"flash"|"none", djClipId?, djOffsetMs?, tick? }
Playlist += { smart?: SmartRules }                                                              // §12.15
ScheduleEntry += { startExact?: boolean }                                                       // §12.4
ShowSettings.audio += { lastCalibration?: {measuredAt, method:"phone"|"manual", residualMs, spreadMs, matches, appliedDelayMs, device?} }
ShowSettings += { https: {enabled=true, extraNames?}, reports: {enabled, time="07:00", email, push, onlyWhenProblems, keepDays=90},
                  power: {mode:"off"|"warn"(default)|"limit", safety=0.9, globalAmps?, globalWatts?, dim: DimWindow[], maxBrightness=100},
                  remote: {publicListener, tailscale?, cloudflare?},
                  updates: {channel:"stable"|"beta", auto:"off"|"notify"(default)|"install", window:{from="10:00", to="14:00", days}, avoidShowHours=2},
                  xlights: {fppConnect, passwordHash? /*write-only: "" when set*/, addToPlaylists=true, watchFolder?},
                  features: {disabled: FeatureId[] /*[] = everything on, §12.17*/} }
Trigger += { kind:"sensor", sensor?: {sensorNodeId, input}, cooldownS?, when?:"always"|"showOnly"|"idleOnly"|"offOnly",
             activeWindow?: {from: TimeSpec, to: TimeSpec}, maxPerHour? }
TriggerAction += { type:"surprise", target?: Target, durationMs?, source?:"sequence"|"effect" }
```

Countdown items and surprise actions are rendered by the engine (§12.4, §12.16).

### 4.1 Channel mapping (internal)

For each prop, pixel `i` (0-based in xLights model order) reads 3 bytes at
`channelStart + 3*i` from the fseq frame. If the prop has `channelRuns`, pixel `i` instead
reads from the run containing it, at `run.channelStart + 3*(i - run.propOffset)`; pixels
covered by no run have no data (black). Runs beyond `pixelCount` are clipped. Everything
that reads prop channels (node routing, `.ppseq` slices, power estimates, the live preview,
effects/overlays written into channel space, sequence channel-count checks) goes through
`Prop::channel_ranges` / `Prop::channel_of_pixel`, and the `NodeMap` splits a segment into
one precomputed copy run per channel run, so rendering stays allocation-free. The segment containing `i` (by
`propOffset`) gives `(node, output, startPixel + (reverse ? count-1-(i-propOffset) : i-propOffset))`.
Output colour order, brightness and gamma are applied at output time. xLights has already
applied model-level colour order? **No**: xLights fseq data is always RGB per model; colour
order is a *controller port* property, applied by PixelPlus.

---

## 5. xLights import

User uploads `xlights_rgbeffects.xml` (and optionally `xlights_networks.xml`). The importer
(`pixelplus-core::xlights`):

1. Parses controllers from networks.xml (including `Ethernet` DDP/E1.31 controllers with
   universes) to compute each controller's absolute start channel.
2. Parses `<model>` elements: `name`, `DisplayAs`, `StartChannel` (supports absolute `1234`,
   `!Controller:123`, `@OtherModel:1`, `>OtherModel:1`, `#universe:ch` and `#ip:universe:ch`),
   `parm1/parm2/parm3` (strings × nodes), `ControllerConnection` (`Port`, `Protocol`), `Controller` name,
   `CustomModel` data, `WorldPosX/Y`, `ScaleX/Y`, and model dimensions for the preview.
3. Computes pixel count and absolute `channelStart` for each model. Models with individual
   start channels (`Advanced="1"` plus `String1`, `String2`, … — any of the start-channel forms
   above) become `channelRuns`, following xLights' node numbering per model type: arches,
   candy canes, matrices, trees, spheres, lines, poly lines (split at `PolyNodeN`), multi-point,
   circles, wreaths, stars and spinners put each string at its own start channel; icicles,
   window frames, cubes and layered arches number every node from `String1`; custom models
   number every node from the lowest string start. `@Model:n` / `>Model:n` referring to such a
   model use its lowest / highest channel, like xLights. Missing `StringN` attributes keep the
   contiguous position (with a warning).
   Inactive models (`Active="0"`) are skipped with a warning (xLights never outputs them) but
   still count for `>`/`@` chaining. Controllers and outputs of types xLights does not know
   are dropped (they take no channels), as xLights does, with a warning.
4. Proposes a mapping: xLights controller name → PixelPlus node (matched by name/hostname or
   chosen by the user in the import wizard), model `ControllerConnection.Port` → output, chained
   models on the same port get consecutive `startPixel` in order of their start channel.
5. Returns an `ImportPreview` (props with proposed segments + warnings); the UI shows it and
   the user confirms. Re-import merges by `xlightsModel` name and keeps user edits.

**Recommended xLights setup** (documented in the UI): add each PixelPlus node in xLights as a
controller of vendor *PixelPlus/Generic*, protocol **DDP**, "Auto size", ports per board. The user
never types a universe.

Sequences: user uploads `.fseq` (v1, v2 uncompressed, zstd, zlib; sparse ranges supported). The
matching audio (mp3/ogg/m4a/wav/flac) is uploaded with it or picked from media; the fseq header's
media filename is used to auto-link.

---

## 6. Data directory (`/var/lib/pixelplus`)

```
show.json                    # the Show (source of truth, leader)
node.json                    # this node's identity: {id, role, leaderUrl?, clusterKey? (follower: its own key)}
cluster/keys.json            # leader: one key per follower; follower: key-pending flag (0600)
sequences/<id>.fseq          # leader: full fseq
sequences/<id>.ppseq         # follower: node-specific slice (see §7.3)
media/<id>.<ext>             # audio
media/<id>.meta.json         # loudness etc.
thumbnails/<id>.png
snapshots/<timestamp>-<label>.tar.zst   # show.json + referenced small files (not sequences unless requested)
logs/
tts/models/                  # kokoro model (Pi 4/5, Docker); owned by the pixelplus-tts user on packages
games/roms/                  # NES ROMs (group pixelplus-overlay, shared with the games sidecar)
```

File paths inside `show.json` (`media.file`, `sequence.file`, `sequence.thumbnail`) are never
trusted (`services/paths.rs`): they must be `media/<id>.<audio ext>`, `sequences/<id>.fseq|ppseq`,
`thumbnails/<id>.png` with `<id>` of `[A-Za-z0-9_-]{1,64}`. Every store write (and loading, and a
snapshot restore) rebuilds any other path from the entity id or blanks it; file-serving code
resolves them through the same check. Snapshot restore unpacks only such files, within a size
budget (16 GiB and the free space minus 256 MiB); snapshot uploads are capped at 2 GiB. Audio is
served only with an audio content type from a whitelist, `Content-Disposition: attachment` and
`nosniff`.

---

## 7. Cluster (leader / followers)

### 7.1 Discovery & adoption
* Every node advertises mDNS `_pixelplus._tcp` (TXT: `id`, `role`, `board`, `ver`; through
  avahi-daemon when it runs, else the built-in responder - see BUILDING.md "mDNS") and sends a UDP
  broadcast **beacon** on port 32320 every 2 s:
  `{"t":"beacon","id","name","role","board","boardRev","pi","ver","http":80,"adoptedBy":<leaderId|null>,"proto":2}`
  (`proto` = cluster protocol version, §7.4.1; absent = 1). Broadcast is used for discovery only:
  everything timing-related is unicast (§7.4.1).
* The leader UI lists unadopted nodes under **Controllers → New controllers found**. Clicking
  **Adopt** calls `POST http://<follower>/api/v1/cluster/adopt {leaderId, leaderUrl, dh, force?, name?}`;
  the follower answers `{id, name, hostname, board, …, dh, proof}`. Both sides derive **a key for this
  follower only** from the X25519 exchange (`dh`), so the key never crosses the network; `proof`
  shows the leader that the follower derived the same key. The follower keeps it in `node.json`
  (`clusterKey`), the leader in `cluster/keys.json` (0600). See §7.5 for how it is used and for the
  rules deciding who may adopt a controller.
* A controller that is itself a leader is offered for adoption only while its owner has
  **Controllers → Join another show** open (15 minutes, optionally for one leader address:
  `POST /api/v1/system/join-show {leaderUrl?}`, a normal signed-in call); adopting it replaces its
  show (a copy is kept in `cluster/show-before-adopt-*.json`).
* A fresh node boots as `role: "unconfigured"`: its own UI shows a welcome screen:
  "Make this the show leader" or "Waiting to be adopted by a leader…" (with its name/IP).

### 7.2 Configuration push
* Leader computes a **NodeManifest** per follower whenever `show.version` changes:
  `{showVersion, node: Node, props: [props with segments on this node, channel ranges remapped],
   sequences: [{id, name, hash, durationMs, frameMs}], effects, outputs}`.
* Heartbeats (below) carry `showVersion`; a follower whose manifest version differs calls
  `GET <leader>/api/v1/cluster/manifest/<nodeId>` and then fetches missing sequence slices with
  `GET <leader>/api/v1/cluster/slice/<nodeId>/<sequenceId>` (ETag = hash). Downloads resume.
  Followers delete slices no longer referenced.

### 7.3 `.ppseq` slice format
A follower only needs the bytes for its own outputs. The leader precomputes the node's pixel
buffer layout: `output-major, pixel-order` RGB bytes (colour order NOT yet applied). Format:

```
"PPSQ" | u16 version=1 | u32 frameCount | u32 frameMs(×1000 µs) | u32 frameBytes |
u16 outputCount | outputCount × u32 pixelsPerOutput | 32-byte sha256 of source fseq |
frames: zstd-compressed blocks, each block = up to 64 frames; block index table at end:
[u64 offset, u32 compressedLen, u32 firstFrame] × nBlocks | u32 nBlocks | "PPSQ"
```
The leader uses the same renderer for its own outputs (it plays from the full fseq directly).

### 7.4 Sync

Goal: every controller shows the frame the audience should see *now*, i.e. the leader's
timeline at the moment the lights change, and that timeline matches what the audience hears.
Error sources, from largest (before protocol 2) to smallest: the follower's old ±1-frame
deadband (a 0..F sawtooth), vblank quantisation and pipeline lag (0..R late per node), WS281x
latch delay (0–49 ms by string length), and only then the network (sub-ms with the measures
below). Measured accuracy and remaining limits: §7.4.9; board options: `docs/HARDWARE-NOTES.md`.

* Effects sent to followers (sync packets, commands, manifests) must be copies passed through
  `effects::stamp_world_bounds(&mut copy, &show.props)` so display-wide effects line up across nodes.
* Audio plays only on the leader. Commands (test patterns, fault finder, effects, blackout) are
  HTTP POSTs to `/api/v1/cluster/command` on the follower.

#### 7.4.1 Transport and protocol version
* Clock probes (`ping`/`pong`) and sync packets are **unicast** UDP 32420 (`PIXELPLUS_CLUSTER_PORT`;
  before this release 32320, which is FPP's multisync port that xLights FPP Connect pings) to/from
  each adopted follower, MACed with that follower's key (§7.5). All controllers of a show must run
  the same release; the leader and followers of different releases don't see each other. Broadcast carries only the unauthenticated
  discovery beacon: Wi-Fi broadcast waits for the next DTIM beacon, goes out at the lowest rate
  and is never retransmitted.
* The cluster socket is marked **DSCP EF** (`IP_TOS 0xB8`, IPv6 traffic class) and
  `SO_PRIORITY 6`; Linux maps EF to the Wi-Fi voice/video access category (WMM), so timing
  packets skip the best-effort queue. The overlay socket uses AF41.
* **Protocol version** `proto` (`proto.rs PROTOCOL_VERSION`): 1 = 3-timestamp pong, integer-ms
  sync; **2** = 4-timestamp pong (`t2`), timeline anchors, sync-quality reports. A leader and its
  followers must run the same version: a mismatch is shown on the follower's node card, in the
  leader's log and health check ("update both to the same version"). Protocol 2 still parses
  protocol 1 packets (missing fields fall back), but only matching versions are supported.
  Beacons may carry `protoMin`/`protoMax` (§12.13, version tolerance for cluster updates).
* Optional fields added by the feature wave (all skipped when absent, protocol stays 2): sync
  `surprise` {id, kind, ref, targets[], startPos, durationMs, epoch} (§12.16) and
  `test.{map, mapRunId, identify, cal}` (§12.1, §12.5–§12.8); follower report `limiter`
  {activeGroups[], minScale, secondsLimited} (§12.11); manifest `power` (NodePowerBudget) and
  `settings.disabledPropIds` (§12.7, §12.11).

#### 7.4.2 Clock exchange (4 timestamps, kernel receive stamps)
```
ping : follower → leader  {"t":"ping","id","t0"}            t0 = follower clock when sent
pong : leader → follower  {"t":"pong","id","t0","t1","t2","boot"}
                           t1 = leader kernel RX stamp of the ping, t2 = leader clock when the pong is sent
                           t3 = follower kernel RX stamp of the pong
delay  = (t3 − t0) − (t2 − t1)        round trip without the leader's processing time
offset = ((t1 − t0) + (t2 − t3)) / 2  leader clock − follower clock
```
* Clocks are CLOCK_MONOTONIC ms since each daemon's start (f64). Receive times come from
  `SO_TIMESTAMPNS` (taken in the kernel network core, free of tokio wake-up, JSON and HMAC time;
  CLOCK_REALTIME converted to monotonic at receive time; stamps older than 100 ms are refused),
  falling back to userspace time where unavailable. `t0` is taken after the ping is encoded,
  `t2` just before encoding plus the lower envelope of recent encode times.
* Pings go out in **bursts**: 5 pings 20 ms apart every 2 s; a **fast-start burst** of 16 pings
  10 ms apart (every 200 ms) after adoption, a leader restart (new boot id) or a detected clock
  step, until 5 good samples exist (a usable estimate in ~200 ms). Unanswered pings over the last
  90 s give the loss rate.

#### 7.4.3 Clock model (`cluster/clock.rs ClockModel`)
Fits `offset(t) = a + b·(t − t_ref)` (offset **and drift** b) over the last **90 s**:
the best sample of each burst and of each 4 s bin; only samples within
`3 · max(0.3 ms, ½(p30 − min))` of the minimum delay; weights `1/(delay − min + 0.1 ms)²`;
the drift regularised toward the previous estimate (σ 200 ppm, clamp ±1000 ppm); one robust
pass drops residual outliers. A sample further from the fit than half its excess delay (+ fit
noise, drift uncertainty, 0.5 ms) is **quarantined**; low-delay quarantined samples in 3 bursts in a
row mean the clock stepped (e.g. NTP) and the fit restarts from them. An offset jump > 50 ms
(leader restart) or a new leader boot id resets at once. Without pongs the fit extrapolates
(holdover: 60 s cost 0.06 ms in simulation). Reported error bound: `min_delay/2 + rms`.

Simulated (unit tests, 30 min, drift ±45–100 ppm, heavy-tailed jitter, spikes, 5 % loss): clock
error mean 0.045 ms, worst < 0.5 ms; busy 2.4 GHz (asymmetric jitter, 15 % loss) worst < 1 ms.

#### 7.4.4 Sync packets: timeline anchors
Every 250 ms while active (every 2 s idle) and at once on a change (state, item, brightness,
blackout, anchor epoch), unicast to each follower:
```
{"t":"sync","leader":id,"showVersion","state":"idle|playing|paused|testing|effect","item":{type,id,name},
 "posMs":u64,"sentAtMs":u64,                                  // protocol 1 rendering (integer ms)
 "anchor":{"posMs":f64,"atMs":f64,"rate":f64,"epoch":u64},     // protocol 2
 "effect"?:EffectPreset,"test"?:TestRequest,"brightness","blackout"}
```
The anchor says: the lights timeline was at `posMs` when the leader clock read `atMs`, and
advances `rate` ms per leader ms (0 while paused). `atMs` is the **engine's own timestamp** of
the position (µs precision), not the time the packet was built. `epoch` changes on every
discontinuity (new item, seek, pause/resume, sound-delay change, a jump of the leader's audio
clock). Anchors are idempotent: loss and reordering cost nothing, holdover is exact to the
drift estimate. The follower converts an anchor to its own clock with the clock model:
`atLocal = to_local(atMs)`, `rateLocal = rate · (1 + b)`, so
`target(t) = posMs + rateLocal · (t − atLocal)` for any local time t.

#### 7.4.5 Following the timeline (`player/clock.rs Servo`)
Followers evaluate the anchor **every output frame** (not only when a packet arrives) and track
it with a servo: a new epoch or an error > 100 ms jumps; otherwise
`rate = rateLocal + clamp(e / 500 ms, ±2 %)` — continuous, **no deadband**, so model updates
of a fraction of a millisecond are absorbed within about a second. The leader's own lights use
the same kind of servo on its audio clock (a slow PI loop, τ ≈ 2 s, that learns the sound card's
rate and filters ALSA delay jitter); its anchors carry that smooth timeline and its learnt rate.
Loss: after 3 s without packets a follower plays on (holdover) to the end of the item, holds
3 s, fades to dark.

#### 7.4.6 Presentation time (DPI)
Each frame is chosen for the moment it **lights up**, on the leader and on followers:
`t_light = v + latch`, where v is the vblank the flip will take effect at (predicted from the
page-flip timestamps: the grid `last + n·R`, after any flip still pending) and `latch` the WS281x
latch delay of this node's strings (`L × line + 0.28 ms`; L = the longest string when
bottom-aligned, else the mean string length). The frame shown is the one covering the middle of
its slot: `idx = floor((pos(t_light) + R/2) / F)`. The output thread is paced from the vblank
grid: the next update is timed for the next frame boundary of the timeline
(`clock::next_update`), moved to the vblank at which it will show, and composing starts early
enough (smoothed tick time × 1.5 + 1 ms) for the flip to make it. When R < F, frames change only at
frame boundaries (the vblanks in between are skipped); when R > F, every refresh shows the frame at
the middle of its slot. Frame changes then land within **±R/2 of the ideal instant** on every node
(±12 ms at 800 px/40 Hz, ±6 ms at 400 px, ±1.7 ms at 100 px) instead of 0..R late plus a frame of
pipeline lag. Without a scanned-out display (simulation) frames light up when written and the
loop wakes at the timeline's frame boundaries; `PIXELPLUS_SIM_REFRESH_HZ` simulates a vblank grid.

#### 7.4.7 Sound delay and calibration
`settings.audio.outputDelayMs` (i32, −500…2000, default 0) is how much later the audience hears
the sound than it leaves the leader's audio output (FM transmitter, HDMI TV, Bluetooth, and
~2.9 ms per metre of air). The leader's lights timeline is `audio position − outputDelayMs`;
anchors carry that timeline, so every controller's lights are delayed alike. Changing it starts a
new epoch (followers jump at once). **Settings → Audio → Sync lights to sound** calibrates it:
`POST /player/calibration {on}` plays a click every second (`cache/calibration-click.wav`) while
every prop on every controller flashes white for 50 ms at the same timeline instants (item type
`calibration`); the user moves a slider (±1/±10 ms steps, presets) until flash and click
coincide where the audience stands. Item ends and the status `posMs` stay on the audio clock
(what is heard).

#### 7.4.8 Wi-Fi power save, sync quality, health
* Power save makes the access point hold packets for a dozing station (50–1000 ms). The image
  sets NetworkManager `wifi.powersave = 2` (`/etc/NetworkManager/conf.d/40-pixelplus-wifi-powersave.conf`
  and the package's appliance `50-pixelplus.conf`); `pixelplus-firstboot` and `pixelplus-netwatch`
  run `iw dev wlan0 set power_save off` as a fallback; the daemon checks `iw dev wlan0 get
  power_save` every minute.
* Followers report in their beacon (`report.quality`): clock error bound, fit jitter, drift ppm,
  RTT min/p50/p95, loss %, samples, the servo's timeline error, pixel refresh (Hz), kernel
  timestamps in use, and `wifiPowerSave`. `GET /nodes` / the `nodes` WebSocket message carry them as
  `sync`, `wifiPowerSave`, `protocol`. The Controllers page shows a badge per follower ("In sync
  ±0.3 ms": excellent < 2 ms, good < 5 ms, fair < 1 frame, poor otherwise or with power save on,
  > 10 % loss, another protocol) with a detail popover and fixes. The health check's **Timing**
  item fails on a protocol mismatch and warns on power save, > 5 ms error or > 10 % loss.

#### 7.4.9 Accuracy and limits
* Network timeline error: sub-ms on decent Wi-Fi (simulation: mean ≈ 0.04 ms, worst ≈ 0.2 ms at
  up to 100 ppm drift; busy 2.4 GHz worst ≈ 0.6 ms), tens of µs on loopback/Ethernet (e2e on
  one machine: ≤ 0.035 ms). The residual floor is the (unmeasurable) asymmetry of the minimum
  path delays.
* Visible alignment per node: ±R/2 (vblank quantisation; only shorter strings, i.e. a higher
  refresh, reduce it), plus string-length skew unless latch alignment is on.
* Lights vs sound: aligned to what leaves the leader's audio device; everything after it is the
  user's `outputDelayMs`. The Pi headphone jack reports its delay in ~10 ms steps (filtered).
* Hardware options (SYNC header, GPS PPS): `docs/HARDWARE-NOTES.md`.

### 7.5 Cluster security
**Keys.** One key per follower (§7.1), never shared: compromising one follower gives no access
to the leader's admin API, to other followers, or to anything but that follower's own slot. A
cluster key **never authenticates the admin API** (`/api/v1/*` outside `/cluster/*`), only the
calls between that follower and its leader. Manifests and slices carry no secrets (no
passwords, SMTP/MQTT settings or keys). Followers adopted by an older PixelPlus (one show-wide
key) keep working and are re-keyed automatically by a signed re-adoption.

**Signed HTTP** (`cluster/sig.rs`). Leader → follower (`/cluster/command`, `/cluster/release`,
re-adoption) and follower → leader (`/cluster/manifest/<own id>`, `/cluster/slice/<own id>/…`)
carry `X-PixelPlus-Auth: v1 <senderId> <unixTime> <nonce> <hmac>`: HMAC-SHA256 with that
follower's key over method, path + query, sender, time, nonce and the SHA-256 of the body. The
receiver rejects a time more than 30 s off its clock and any nonce it has seen. Controllers
without a real-time clock may disagree about the time: a correctly signed request outside the
window gets `401` with `X-PixelPlus-Time: <unixTime> <hmac>` (MACed over the request nonce), and
the sender retries once with the corrected offset. The leader's manifest and slice replies carry
`X-PixelPlus-Reply` (HMAC over the request nonce and the body hash / slice ETag + checksum), so
a follower only installs what its leader sent. The key itself is never sent.

**UDP** (`proto.rs`). Every authenticated datagram carries the sender's boot id (`bt`) and a
sequence number (`sq`) that grows with every packet, inside the HMAC. Receivers keep, per sender,
the current boot id, the highest sequence number and which of the 64 numbers below it were
seen, and drop anything seen before or older than that window (replays of sync, overlay, pong
or beacon packets; slightly reordered packets are still accepted once). A follower accepts a *new* leader boot id only from a pong that
answers one of its own pings of the last 5 s (a replay can't); an authenticated packet from an
unknown run triggers such a ping. Boot ids that were replaced are never accepted again. Pong
timestamps (`t1`, `t2`) and sync anchors are covered by the MAC like everything else. The
leader unicasts sync packets, pongs, overlay frames (`'P'` frames with boot id and sequence
number) and a copy of its beacon to each follower, MACed with that follower's key; its
broadcast beacon is unauthenticated (discovery only).

**Sensor nodes (§12.16, UDP 32422).** ESP32 sensor nodes use the same key derivation
(X25519 + HKDF-SHA256 as `sig.rs`) and the same JSON MAC canonicalization as cluster datagrams:
the object is serialized, `,"bt":"<boot>","sq":<seq>` is appended before the closing brace, then
`,"mac":"<64 hex>"}` where the MAC is HMAC-SHA256 over every byte before `,"mac"` plus the closing
`}`. Messages: `sbeacon` (unauthenticated discovery), `sevent`/`sstatus` (MACed, replay window as
followers), leader reply `sack`. Shared test vectors: `firmware/esp32-sensor/test/vectors.json`
(WS6). A sensor key authorizes only that node's events and its own config.

**Who may adopt a controller** (`POST /cluster/adopt`, `follower::handle_adopt`):

| This controller | Accepted when |
|---|---|
| unconfigured, or a follower without leader (released) | always: trust on first use, logged ("Adopted by show leader … at …") and shown on its page |
| follower of leader L | the call is signed by L with the current key; or it repeats an adoption by L whose key L never used yet (e.g. after a timeout); or its signed-in owner clicked **Allow a new leader** (15 min, `POST /system/join-show`); or — only when this controller has no password — `force` from the local subnet after L has been silent for 10 minutes |
| leader | only while its owner has **Join another show** open (15 min, optionally only for one leader address) |

`leaderUrl` must be an IP literal on a local network (private, loopback, link-local, CGNAT or
IPv6), so a stranger's adoption can't make the controller call arbitrary hosts.

**Beacon spoofing.** An unauthenticated beacon never replaces a peer entry whose beacon proved a
key in the last 30 s, and a second unverified device announcing the same id from another address
is kept out; either marks the entry as a **possible duplicate** (shown in *New controllers found*,
adoption refused until it clears for 60 s). A spoofed beacon can at most obtain a key for that
(unadopted) slot, which grants that slot's manifest and nothing else; the leader then trusts only
traffic MACed with that key. Right after an adoption the leader ignores the follower's stale,
pre-adoption beacon for up to 10 s (no duplicate "re-adoption").

---

## 8. HTTP API (`/api/v1`, JSON, camelCase)

Auth: if a password is set, `POST /api/v1/auth/login {password}` → session cookie `pp_session`
(minimum 6 characters for new passwords; sign-in is throttled per client address — 5 tries, then
1 min doubling up to 15 min — and globally after 50 failures in 10 min).
Unauthenticated requests get 401 except `/auth/*`, `/public/*` (song requests page), `/system`
(limited info for the sign-in screen), `/system/setup` while unconfigured (local network only) and
`/cluster/*` (signed with a per-follower key, §7.5) and `/hooks/*` (secret trigger links with
their own token, §12.18). A local sidecar (games) sends
`X-PixelPlus-Local: <token>` from `/run/pixelplus/local-token` (random per daemon start, 0640
group `pixelplus-overlay`): accepted only from loopback, never with proxy headers
(`X-Forwarded-For`, `Forwarded`, `CF-Connecting-IP`, …), and only for `GET /show`, `GET /player`,
`GET /system`, `/ws`, `POST /player/{pause,resume,stop}` and `/overlay/*`.

Browser protection (`api/security.rs`), independent of the password:
* **Host allow-list** for `/api/v1/*` except `/public/*`: IP literals, `localhost`,
  `<hostname>`/`<hostname>.local`, and `settings.security.allowedHosts` (e.g. a tunnel domain;
  `*.example.com` allowed; env `PIXELPLUS_ALLOWED_HOSTS`). Others get `421` (friendly HTML page
  for browsers) — this defeats DNS rebinding.
* **CSRF header**: every request other than GET/HEAD/OPTIONS (except `/public/*`) must send
  `X-PixelPlus-Request: 1` (the web UI, sidecars and cluster calls always do), else `403 csrf`.
* **WebSocket** `Origin`, when present, must match `Host`; messages are limited to 64 KiB.
* **Headers** on every response: `Content-Security-Policy` (inline-script hashes of the built UI,
  recomputed when `index.html` changes; `PIXELPLUS_CSP` overrides, `off` disables),
  `X-Content-Type-Options: nosniff`, `X-Frame-Options: DENY`, `Referrer-Policy: same-origin`.
* **Secrets are write-only**: `GET /show` and `PUT /show/settings` return SMTP and MQTT passwords
  as `"********"`; sending that placeholder back keeps the stored value. Trigger-link token hashes are
  left out entirely (only `tokenHint`/`tokenCreatedAt` show; §12.18). `POST /mqtt/test` uses the
  stored password only for the stored broker (host + port).
* **Client address** (song-request rate limit, sign-in throttle): forwarding headers count only
  from this machine (`CF-Connecting-IP`, else the right-most `X-Forwarded-For` hop) or from
  `settings.security.trustedProxies`.

Errors: `{ "error": { "code": "not_found", "message": "Human readable" } }` with HTTP status.

| Method & path | Description |
|---|---|
| `GET /system` | `SystemInfo` {version, nodeId, role, hostname, board, boardRev, piModel, uptimeS, cpuPct, memPct, diskFreeMb, tempC, ips[], time, timezone, wifi:{ssid, signal}, needsSetup, passwordSet} |
| `POST /system/setup` | first-run wizard: {role:"leader"|"follower", showName?, board?, boardRev?, location?, timezone?, password?} |
| `POST /system/reboot`, `/system/shutdown`, `/system/restart-service` | |
| `GET /system/logs?lines=500` | text |
| `GET/PUT /system/network` | {hostname, wifi:{ssid, psk?, country}, ethernet:{dhcp, address?, gateway?, dns?}, managed (read-only), netwatch (read-only: `/run/pixelplus/netwatch.json` {state:"waiting"|"online"|"hotspot"|"connecting", hotspotSsid, hotspotSecured, portalUrl, lastError, lastJoined:{ssid, ips, at}, updatedAt} or null)}; `GET /system/network/scan` → [{ssid, signal, secure}] |
| `GET /system/helpers` | latest root-helper jobs [{verb, state:"running"|"ok"|"failed", message, updatedAt}] (also pushed as WS `helper`) |
| `GET/PUT /system/ssh` | {enabled:boolean|null, canChange, job?} / {enabled} → helper `ssh-on`/`ssh-off` |
| `POST /system/reapply` | re-apply `/boot/firmware/pixelplus.txt` (helper `reapply`) |
| `GET /system/output-geometry` | {ok, longestString, maxPixels, configuredPixels, pendingReboot, canApply, targetPixels, piMaxPixels, message} |
| `POST /system/output-geometry/apply` | {reboot?:true}: helper `config-txt:<board>:<pixels>` for the longest string, then reboot via logind → {ok, job, geometry}; 409 when nothing to do |
| `GET /public/health` | {ok, version, role}: unauthenticated liveness (Docker healthcheck) |
| `GET /system/sensors` | [{id, label, kind:"temperature"|"voltage"|"current"|"power", value, unit, warn?, crit?}]; ids: cpuTemp, driverTemp, powerTemp, enclosureTemp, inputVoltage, inputCurrent, inputPower. For voltage sensors warn/crit are minimums, otherwise maximums |
| `GET /system/sensors/history?minutes=60` | {series: {id: [[t,v]...]}} |
| `POST /system/eeprom` | {board, rev} write EEPROM |
| `GET /system/update`, `POST /system/update` | check (`apt-cache policy`; {current, latest, available, canApply, message?, job?}) / install (helper `update`) |
| `POST /auth/login`, `POST /auth/logout`, `PUT /auth/password` | |
| `GET /show` | full `Show` |
| `PUT /show/settings` | ShowSettings (partial merge) |
| `GET/POST /nodes`, `GET/PUT/DELETE /nodes/:id` | nodes; `GET /nodes/discovered` → beacons of unadopted nodes; `POST /nodes/adopt {id}` |
| `PUT /nodes/:id/outputs/:index` | OutputConfig |
| CRUD `/receivers`, `/props`, `/prop-groups`, `/effects`, `/playlists`, `/dj-clips` | `GET` list, `POST` create, `GET/PUT/DELETE /:id` |
| `POST /props/bulk` | {ops:[{op:"update"|"delete", id, patch?}]} |
| `POST /import/xlights` | multipart `rgbeffects` (+`networks`) → `ImportPreview` {props, controllers:[{name, suggestedNodeId, ip, protocol, ports, propCount}], groups, warnings[]}. In the preview, `segments[].nodeId` holds the **xLights controller name** (placeholder) until applied |
| `POST /import/xlights/apply` | {preview, controllerMap:{xlightsControllerName: nodeId}} → Show |
| `GET /sequences`, `POST /sequences` (multipart fseq + optional audio) , `GET/PUT/DELETE /sequences/:id` | |
| `GET /sequences/:id/thumbnail` | PNG |
| `GET /media`, `POST /media` (multipart), `GET/PUT/DELETE /media/:id`, `GET /media/:id/file` | |
| `GET /schedule`, `PUT /schedule` | |
| `GET /schedule/preview?days=14` | expanded occurrences [{date, start, end, entryId, playlistId, name}] |
| `GET /player` | PlayerStatus |
| `POST /player/play` | {playlistId? \| sequenceId? \| djClipId? \| effectId? \| mediaId?, startIndex?, loopUntilStopped?:bool} — see *Manual playback* below |
| `POST /player/stop` {fade?:bool}, `/player/pause`, `/player/resume`, `/player/next`, `/player/previous`, `/player/seek {posMs}` | |
| `PUT /player/volume {volume}`, `PUT /player/brightness {brightness}` | |
| `POST /player/calibration {on}` | "Sync lights to sound" test pattern (click + white flash every second, all controllers), §7.4.7 |
| `POST /test/start` | {mode:"solid"|"chase"|"rgbCycle"|"countPixels"|"walk"|"effect"|"mapCode"|"identify"|"calibration", color?, target:{nodeId?, output?, propIds?, groupIds?, all?}, effect?: EffectPreset, map?: MapPlan, mapRunId?, identify?: [{nodeId, output, color, blinks}], cal?: {seed, v}} (new modes: §12) |
| `POST /test/stop` | |
| `POST /faultfinder/start` {propId} → FaultSession; `POST /faultfinder/:session/answer {lit:boolean}` → next step or result {pixelIndex, message} ; `POST /faultfinder/stop` | binary search for first bad pixel: lights pixels [0..mid], asks "do all lit pixels light correctly?" |
| `GET /power/estimate?sequenceId=` | {perOutput:[{nodeId, output, peakAmps, avgAmps}], perReceiverPort:[...], perProp:[...], warnings[]} |
| `GET /health` | HealthReport {ok, checks:[{id, label, status:"ok"|"warn"|"fail", detail, action?:"applyOutputGeometry"|"reboot"}]} |
| `POST /health/run` | run pre-show check now |
| `GET /snapshots`, `POST /snapshots {label}`, `POST /snapshots/:id/restore`, `GET /snapshots/:id/download`, `POST /snapshots/import` (multipart), `DELETE /snapshots/:id` | |
| `GET /effects/catalog` | `effect_catalog()` → [{kind, label, description, params: ParamSpec[]}]; `GET /effects/schema` → {kind: ParamSpec[]} ; `GET /effects/builtin` → builtin presets |
| `GET /tts/status` | {mode:"device"|"browser", available:boolean, voices:[{id, name, language, gender}] } |
| `POST /tts/render` | {lines, speed} → audio/mpeg (device mode) |
| `POST /dj-clips/:id/render` | render on device → updates mediaId |
| `POST /dj-clips/:id/upload` | multipart audio rendered in browser |
| `GET /public/requests` | public song list + queue (no auth) ; `POST /public/requests {sequenceId, name?}` |
| `GET /requests`, `DELETE /requests/:id` | admin view of queue |
| `GET /cluster/manifest/:nodeId`, `GET /cluster/slice/:nodeId/:seqId`, `POST /cluster/adopt`, `POST /cluster/command`, `POST /cluster/release` | cluster internal (signed, §7.5) |
| `GET/POST/DELETE /system/join-show` | {open, secondsLeft, leaderAddress}; POST {leaderUrl?}: for 15 min another leader may adopt this controller ("Join another show" / "Allow a new leader") |
| `GET /journal?date=YYYY-MM-DD&types=a,b` | one local day of the show journal (§12.10): `[{ts, ev, …fields}]` |
| `POST /triggers/:id/fire` (= `POST /triggers/:id`) | fire a trigger through its gates (session + CSRF like every admin call) |
| `POST /triggers/:id/token`, `DELETE /triggers/:id/token`, `GET /triggers/links` | secret trigger link: make/rotate (`{token, tokenHint, tokenCreatedAt, path, rotated}`, the only time the token is shown) / revoke / `{addresses:[{kind, label, base}], links:{id: {at, from, origin, fired, message}}}` (§12.18) |
| `POST /hooks/trigger/:id` (`GET` when allowed) | **no session, no CSRF header**: `Authorization: Bearer <token>` or `?token=` → `{ok, fired, message, reason?, error?}` (§12.18) |

**Feature-wave endpoints** (one route module per feature in `api/<module>.rs`; shapes in §12
and `web/src/lib/api/types.ts`, checked against the daemon by `web/src/lib/api/contract.test.ts`):

| Module (owner) | Endpoints |
|---|---|
| `tls` (WS1) | `GET /tls/status`, `POST /tls/rotate {ca}`, `GET /public/ca.crt`, `GET /public/ca.mobileconfig` |
| `calibration` (WS1) | `POST /calibration/result {residualMs, spreadMs, matches, device?, apply}`; `POST /player/calibration {on, pattern?:"v1"\|"v2", seed?}` (playerapi, WS3) |
| `autoshow` (WS2) | `GET /media/:id/analysis`, `POST /media/:id/analyze`, `GET /autoshow/styles`, `POST /autoshow`, `POST /autoshow/preview`, `POST /sequences/:id/regenerate` |
| `preview` (WS2) | `GET /sequences/:id/preview`, `GET /sequences/:id/preview/data` |
| `library` (WS2) | `POST /sequences/tags`, `GET /playlists/:id/preview?date=&start=`, `GET /library/history?days=` |
| `mapping` (WS4) | `POST /mapping/runs`, `POST /mapping/runs/:id/{stop,results,apply}`, `GET /mapping/runs[/:id]`, `DELETE /mapping/runs/:id` |
| `pixelcount` (WS4) | `POST /pixelcount/start`, `POST /pixelcount/:session/answer`, `POST /pixelcount/:id/{result,apply}` |
| `wizard` (WS4) | `POST /wizard/receiver/identify-jack`, `POST /wizard/receiver/:session/{jack,port/:n/light,finish,cancel}` |
| `profiles` (WS6) | CRUD `/profiles`, `POST /profiles/:id/activate`, `POST /profiles/capture`, `GET /profiles/preview-switch/:id` |
| `reports` (WS6) | `GET /reports?limit=`, `GET /reports/:date`, `POST /reports/run {date?, send?}` |
| `remote` (WS5) | `GET /remote/status`, `POST /remote/tailscale/{install,up,serve,funnel,down}`, `POST /remote/cloudflare/{install,quick,token,hosts,stop}`, `POST /remote/test` (§12.12) |
| `power` (WS3) | CRUD `/power-supplies`, `GET /power/live` (`/power/estimate` gains `simulateLimiter`) |
| `sensornodes` (WS6) | `GET /sensor-nodes/discovered`, `POST /sensor-nodes/adopt`, CRUD `/sensor-nodes`, `POST /sensor-nodes/:id/release`, `GET /sensor-nodes/:id/live`, `POST /surprises/test`, `GET /cluster/sensor-config/:id` |
| `fppcompat` (WS6) | **root-mounted** (not `/api/v1`): `GET /config.php`, `/api/system/info`, `/api/sequence/:name/meta`, `/api/media/:name/meta`, `PATCH /api/file/:dir`, … (§12.14) |
| cluster/system (WS5) | `POST /nodes/:id/replace`, `POST /nodes/:id/release-retired`, `POST /system/transfer/export` → one-time `GET /system/transfer/download/:token`, `POST /system/setup` multipart restore (§12.9); `GET /system/update[?refresh=true]` (extended), `POST /system/update`, `PUT /system/update/settings`, `POST /system/update/rollback`, `GET /cluster/update/:file` (§12.13); WS `updateJob` |

**Manual playback** (`player/scheduler.rs`): playback started by hand *during* a show window
ends with that window: at the window's end it ends with the entry's `endBehavior` (finish the
song and play the outro / stop / fade), and at once if a higher-priority window takes over; if
it finishes by itself inside the window, the window's playlist starts again. Started *outside*
the windows, a playlist plays **once** (its `repeat` is ignored) and a window that starts
meanwhile waits for it. With `loopUntilStopped` ("Loop until I stop" next to *Play show now*)
the playlist repeats and keeps playing past window ends until the user stops it. Pressing Stop
during a window keeps that window quiet until the next one.
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

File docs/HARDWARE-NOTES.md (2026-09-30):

# Hardware notes: timing and sync (for the next board revisions)

Summary of the sync research (2026-09) as far as it concerns the boards
(difftx, diffsmart, difftxlarge). Short version: **no board change is needed
for good sync**; add one cheap 3-pin **SYNC header** on the next revision of
every board to keep a GPS-PPS upgrade and a hardware timing test point open.

How sync works in software is described in `docs/ARCHITECTURE.md` §7.4.

## Where the timing error comes from

| Source | Size | Fixed by |
|---|---|---|
| Network clock estimate (Wi-Fi) | 0.1–1 ms with power save off; 20–100 µs on Ethernet | software (4-timestamp exchange, kernel receive stamps, offset + drift fit) |
| Frame vs. vblank phase (per controller) | ±R/2: ±12 ms at 800 px/output (40 Hz), ±6 ms at 400 px, ±1.7 ms at 100 px | only a higher refresh, i.e. **shorter strings per output** (split long strings across more ports) |
| WS281x latch delay (string length) | L × 30.6 µs + 0.3 ms: 24.5 ms at 800 px, 49 ms at 1600 px | software (presentation time + latch alignment) |
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

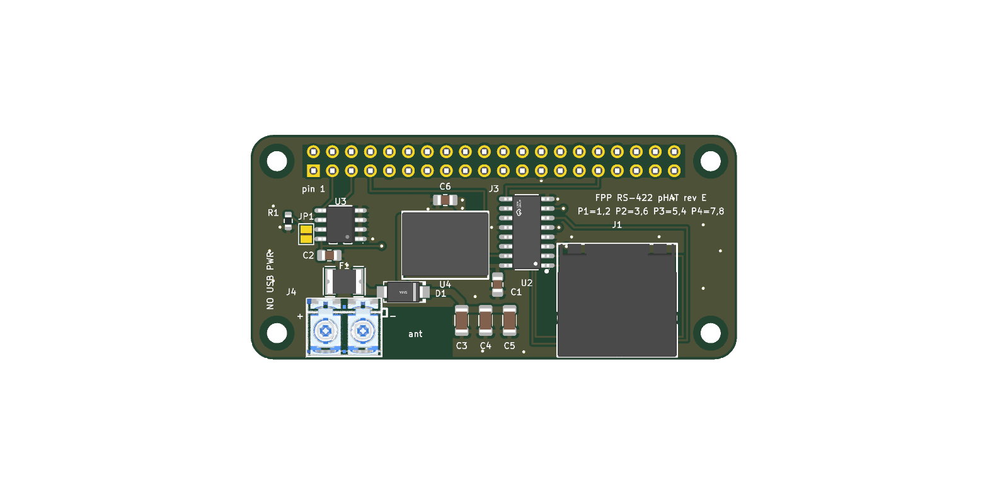
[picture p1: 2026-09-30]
boardtempinfo/difftx/render_top.png

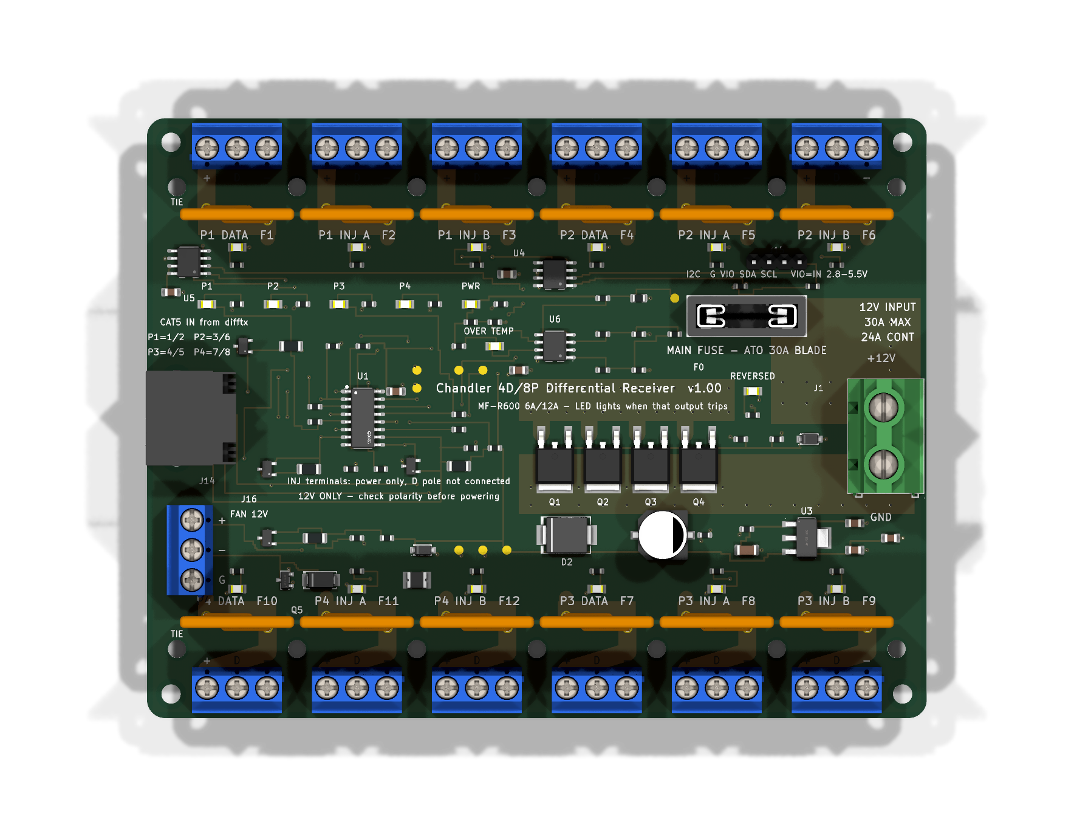
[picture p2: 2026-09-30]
boardtempinfo/diffrx/render_top.png

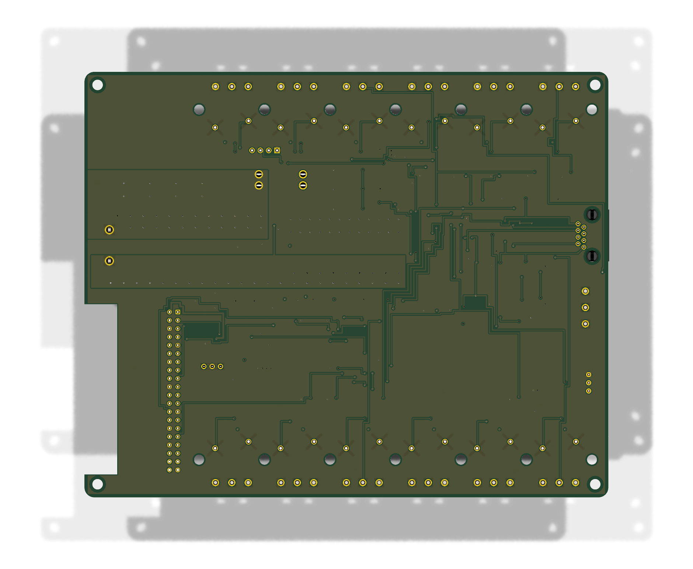
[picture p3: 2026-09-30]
boardtempinfo/diffsmart/render_bottom.png

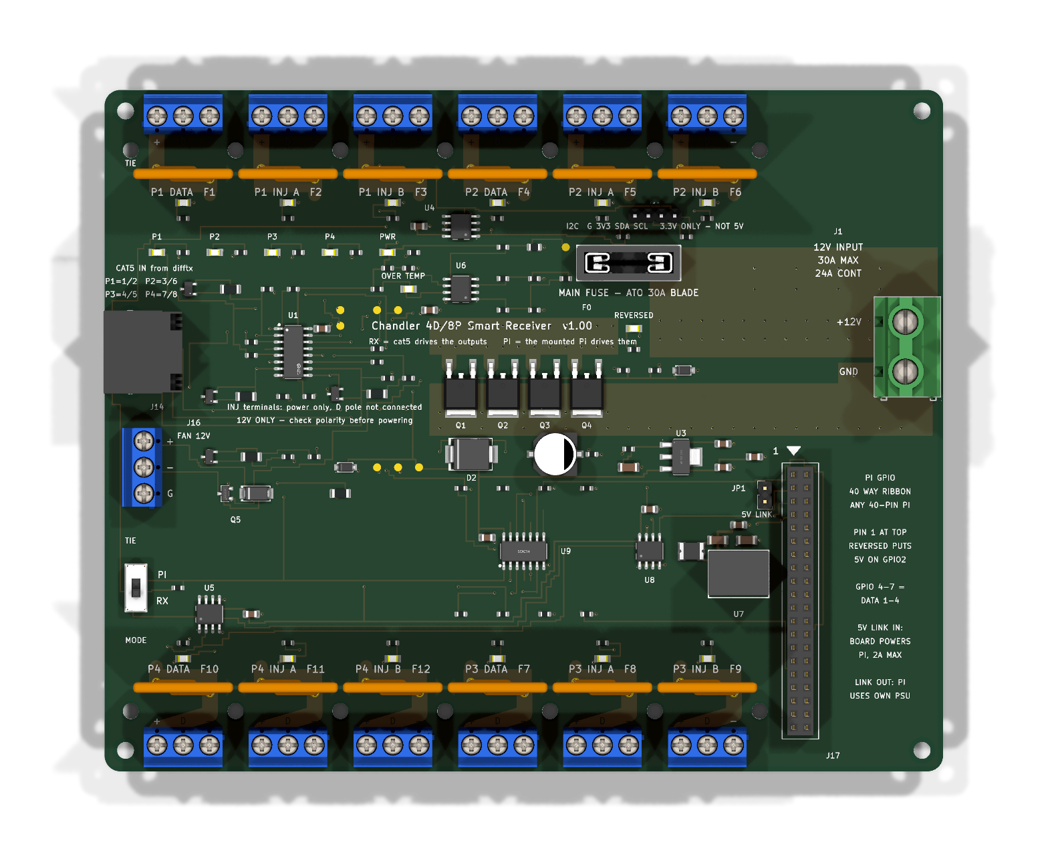
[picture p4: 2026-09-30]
boardtempinfo/diffsmart/render_top.png

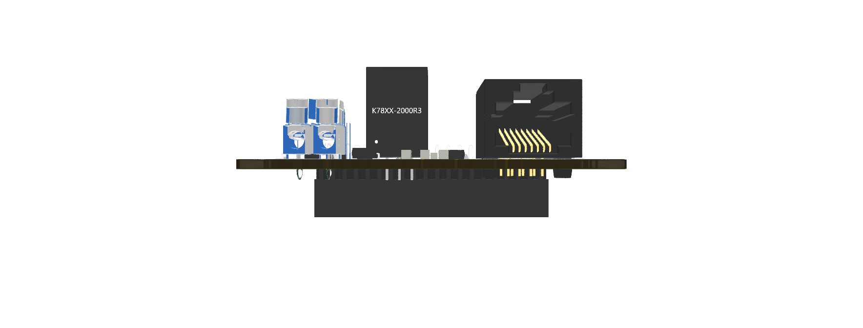
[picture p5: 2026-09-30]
boardtempinfo/difftx/render_front.png

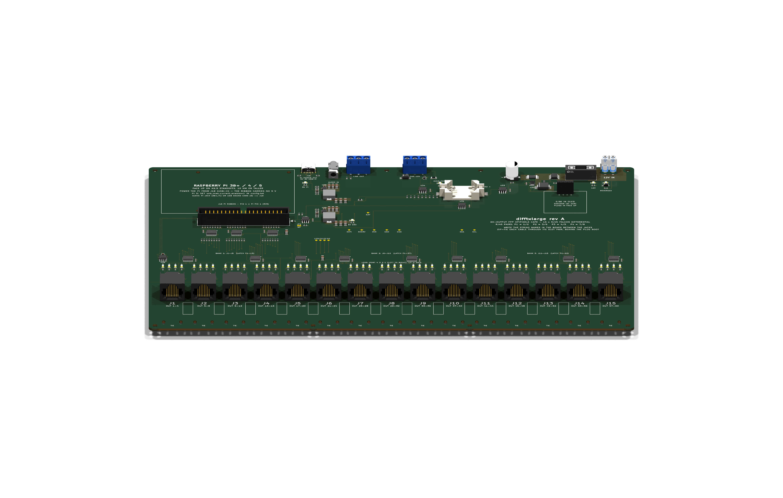
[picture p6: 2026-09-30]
boardtempinfo/difftxlarge/render_iso.png

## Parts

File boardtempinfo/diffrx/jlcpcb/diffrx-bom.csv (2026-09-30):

Comment | Designator | Footprint | LCSC Part #
470uF 25V | C1 | CAP-SMD_BD8.0-L8.3-W8.3-FD | C4747956
10uF | C2 | C_1206_3216Metric | C13585
100nF | C3,C5,C6,C7,C8,C9 | C_0805_2012Metric_Pad1.18x1.45mm_HandSolder | C49678
22uF | C4 | C_0805_2012Metric_Pad1.18x1.45mm_HandSolder | C45783
BZT52C15 | D1 | SOD-123_L2.8-W1.8-LS3.7-RD | C2104
SMDJ15A | D2 | SMC_L6.9-W5.9-LS7.9-RD | C152077
PSM712 | D3,D4,D5,D6 | SOT-23-3_L3.0-W1.7-P0.95-LS2.9-BR | C32677
BZT52C6V2 | D7 | SOD-123_L2.8-W1.8-LS3.7-RD | C173405
SS34 | D8 | SMA_L4.3-W2.6-LS5.2-RD | C8678
ATO 30A | F0 | FUSE-TH_4P-L19.8-W6.7_3557-2 | C352820
6A/12A 30V | F1,F10,F11,F12,F2,F3,F4,F5,F6,F7,F8,F9 | FUSE-TH_L19.1-W3.0-P10.20-D1.2-S2.0 | C208490
0.35A/30V | F13 | F1210 | C2876002
12V 30A IN | J1 | CONN-TH_P9.50_KF950-9.5-2P | C475106
R-RJ45R08P-A004 | J14 | RJ45-TH_R-RJ45R08P-A004 | C385834
I2C | J15 | HDR-TH_4P-P2.54-V-M | C124378
CONN-TH | J10,J11,J12,J13,J16,J2,J3,J4,J5,J6,J7,J8,J9 | CONN-TH_3P-P5.00_KF301-5.0-3P | C474882
green | LED1,LED2,LED3,LED4 | LED0805-R-RD | C2297
yellow | LED5 | LED0805-R-RD | C2296
red | LED6,LED7,LF1,LF10,LF11,LF12,LF2,LF3,LF4,LF5,LF6,LF7,LF8,LF9 | LED0805-R-RD | C2295
AOD4184A | Q1,Q2,Q3,Q4 | TO-252-2_L6.6-W6.1-P4.57-LS9.9-TL-CW | C99124
AO3400A | Q5 | SOT-23-3_L2.9-W1.3-P1.90-LS2.4-BR | C20917
10R | R3 | R_0603_1608Metric | C22859
10k | R1,R27,R29,R30 | R_0603_1608Metric | C25804
100k | R2,R32,R37 | R_0603_1608Metric | C25803
4.7k | R28,R31,R33,R34,R39,R40,RF1,RF10,RF11,RF12,RF2,RF3,RF4,RF5,RF6,RF7,RF8,RF9 | R_0603_1608Metric | C23162
1k | R35,R36,RB1,RB2,RB3,RB4,RB5,RB6,RB7,RB8,RL1,RL2,RL3,RL4,RL5 | R_0603_1608Metric | C21190
470R | RS1,RS2,RS3,RS4 | R_0603_1608Metric | C23179
120R | RT1,RT2,RT3,RT4 | R_1206_3216Metric | C17909
10k NTC | RT5 | R_0805_2012Metric | C3195213
AM26C32IDR | U1 | SOIC-16_L9.9-W3.9-P1.27-LS6.0-BL | C36693
UA78M05CDCYR | U3 | SOT-223_L6.5-W3.5-P2.30-LS7.0-BR | C201654
LM75BD | U4,U5 | SOIC-8_L5.0-W4.0-P1.27-LS6.0-BL | C34565
LM2903QDRQ1 | U6 | SOIC-8_L4.9-W3.9-P1.27-LS6.0-BL | C475499

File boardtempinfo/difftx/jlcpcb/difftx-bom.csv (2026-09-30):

Comment | Designator | Footprint | LCSC Part #
100nF | C1,C2 | C_0805_2012Metric_Pad1.18x1.45mm_HandSolder | C49678
10uF | C3,C4,C5 | C_1206_3216Metric | C89632
22uF | C6 | C_0805_2012Metric_Pad1.18x1.45mm_HandSolder | C45783
SS54 | D1 | SMA_L4.4-W2.8-LS5.4-R-RD | C22452
1.5A | F1 | F1812 | C22392774
R-RJ45R08P-A004 | J1 | RJ45-TH_R-RJ45R08P-A004 | C385834
2x20 socket for Pi | J3 | PiSocket_2x20_bottom | C5124634
terminal 2P 5.0mm | J4 | CONN-TH_P5.00_KF301-5.0-2P | C474881
10k | R1 | R_0603_1608Metric | C25804
AM26C31IDR | U2 | SOIC-16_L9.9-W3.9-P1.27-LS6.0-BL | C34923
AT24C256C-SSHL-T | U3 | SOIC-8_L4.9-W3.9-P1.27-LS6.0-BL | C6482
K7805-2000R3 | U4 | PWRM-TH_K78XX-2000R3 | C18212380

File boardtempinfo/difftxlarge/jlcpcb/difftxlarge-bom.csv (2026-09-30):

Comment | Designator | Footprint | LCSC Part #
CR2032 holder | BT1 | BAT-TH_CR2032-BS-6-1 | C70377
100nF | C1,C10,C11,C12,C13,C14,C15,C16,C17,C18,C19,C2,C20,C21,C22,C23,C24,C25,C26,C27,C3,C4,C40,C44,C5,C50,C54,C6,C60,C61,C62,C63,C64,C65,C7,C8,C9 | C_0603_1608Metric | C14663
470uF 25V | C32 | CAP-SMD_BD8.0-L8.3-W8.3-FD | C4747956
10uF | C41,C42,C43,C51,C52,C53 | C_1206_3216Metric | C13585
100pF | C48,C58 | C_0603_1608Metric | C14858
22uF | C28,C31,C45,C46,C47,C55,C56,C57 | C_1206_3216Metric | C12891
PSM712 | D1,D10,D11,D12,D13,D14,D15,D16,D17,D18,D19,D2,D20,D21,D22,D23,D24,D25,D26,D27,D28,D29,D3,D30,D31,D32,D33,D34,D35,D36,D37,D38,D39,D4,D40,D41,D42,D43,D44,D45,D46,D47,D48,D49,D5,D50,D51,D52,D53,D54,D55,D56,D57,D58,D59,D6,D60,D7,D8,D9 | SOT-23-3_L3.0-W1.7-P0.95-LS2.9-BR | C32677
BZT52C15 | D61 | SOD-123_L2.7-W1.6-LS3.7-RD | C173427
SMDJ15A | D62 | SMC_L6.9-W5.9-LS7.9-RD | C152077
1N4148W | D63 | D_SOD-123 | C81598
SS34 | D64 | SMA_L4.3-W2.6-LS5.2-RD | C8678
ATO 5A | F1 | FUSE-TH_4P-L19.8-W6.7_3557-2 | C352820
0.35A/30V | F2 | Fuse_1206_3216Metric | C2876002
2x20 box header, Pi ribbon | J16 | IDC-TH_40P-P2.54_C9138 | C9138
12V IN | J17 | CONN-TH_P5.00_KF301-5.0-2P | C474881
USB-C to Pi | J18 | TYPE-C-SMD_TYPE-C-6P-073 | C668623
AUDIO IN | J19 | AUDIO-TH_PJ-3270-4A | C961757
CONN-TH | J20,J21 | CONN-TH_3P-P5.00_KF301-5.0-3P | C474882
OLED socket | J22 | HDR-TH_4P-P2.54-V-F | C2718488
R-RJ45R08P-A004 | J1,J10,J11,J12,J13,J14,J15,J2,J3,J4,J5,J6,J7,J8,J9 | RJ45-TH_R-RJ45R08P-A004 | C385834
3.3uH | L1,L2 | IND-SMD_L8.5-W8.0_PSPMAA0803H-330M-ANP | C2962881
green | LED1,LED10,LED11,LED12,LED13,LED14,LED15,LED16,LED17,LED18,LED19,LED2,LED20,LED21,LED22,LED23,LED24,LED25,LED26,LED27,LED28,LED29,LED3,LED30,LED31,LED32,LED33,LED34,LED35,LED36,LED37,LED38,LED39,LED4,LED40,LED41,LED42,LED43,LED44,LED45,LED46,LED47,LED48,LED49,LED5,LED50,LED51,LED52,LED53,LED54,LED55,LED56,LED57,LED58,LED59,LED6,LED60,LED62,LED63,LED64,LED7,LED8,LED9 | LED0805-R-RD | C2297
red | LED61,LED65 | LED0805-RD | C84256
AO4407A | Q1 | SOIC-8_L4.9-W3.9-P1.27-LS6.0-BL | C16072
AO3400A | Q2 | SOT-23-3_L2.9-W1.3-P1.90-LS2.4-BR | C20917
20k | R12,R22 | R_0603_1608Metric | C4184
10mR | R2 | RES-SMD_L6.4-W3.2-R2512 | C2903468
75k | R10,R20 | R_0603_1608Metric | C23242
15k | R14,R24 | R_0603_1608Metric | C22809
10k | R1,R11,R21,R3,R30,R31,R36,R37,R38,R49 | R_0603_1608Metric | C25804
4.7k | R34,R35,R39,R4,R41,R42,R5,RP1,RP10,RP11,RP12,RP13,RP14,RP15,RP16,RP17,RP18,RP19,RP2,RP20,RP21,RP22,RP23,RP3,RP4,RP5,RP6,RP7,RP8,RP9 | R_0603_1608Metric | C23162
1k | R32,R33,R43,R44 | R_0603_1608Metric | C21190
100k | R13,R23,R40,R45 | R_0603_1608Metric | C25803
100R | R46,R47 | R_0603_1608Metric | C22775
330k | R48 | R_0603_1608Metric | C23137
2k | RA1,RA10,RA11,RA12,RA13,RA14,RA15,RA16,RA17,RA18,RA19,RA2,RA20,RA21,RA22,RA23,RA24,RA25,RA26,RA27,RA28,RA29,RA3,RA30,RA31,RA32,RA33,RA34,RA35,RA36,RA37,RA38,RA39,RA4,RA40,RA41,RA42,RA43,RA44,RA45,RA46,RA47,RA48,RA49,RA5,RA50,RA51,RA52,RA53,RA54,RA55,RA56,RA57,RA58,RA59,RA6,RA60,RA7,RA8,RA9 | R_0603_1608Metric | C22975
33R | RS1,RS10,RS11,RS12,RS13,RS14,RS15,RS16,RS17,RS18,RS19,RS2,RS20,RS21,RS22,RS23,RS3,RS4,RS5,RS6,RS7,RS8,RS9 | R_0603_1608Metric | C23140
10k NTC | RT1 | R_0805_2012Metric | C3195213
AM26C31IDR | U1,U10,U11,U12,U13,U14,U15,U2,U3,U4,U5,U6,U7,U8,U9 | SOIC-16_L9.9-W3.9-P1.27-LS6.0-BL | C34923
SN74AHCT573PWR | U16,U17,U18,U19,U20,U21,U22,U23,U24 | TSSOP-20_L6.5-W4.4-P0.65-LS6.4-BL | C141311
SN74AHCT541PWR | U25,U26,U27 | TSSOP-20_L6.5-W4.4-P0.65-LS6.4-BL | C50989
TPS56637RPAR | U28,U29 | VQFN-HR-10_L3.0-W3.0_RPA | C841386
INA226AIDGSR | U30 | MSOP-10_L3.0-W3.0-P0.50-LS5.0-BL | C49851
DS3231MZ+TRL | U31 | SOIC-8_L4.9-W3.9-P1.27-LS6.0-BL | C107410
LM75BD | U32,U33 | SOIC-8_L5.0-W4.0-P1.27-LS6.0-BL | C34565
LM2903QDRQ1 | U34 | SOIC-8_L4.9-W3.9-P1.27-LS6.0-BL | C475499
AT24C256C | U35 | SOIC-8_L4.9-W3.9-P1.27-LS6.0-BL | C6482

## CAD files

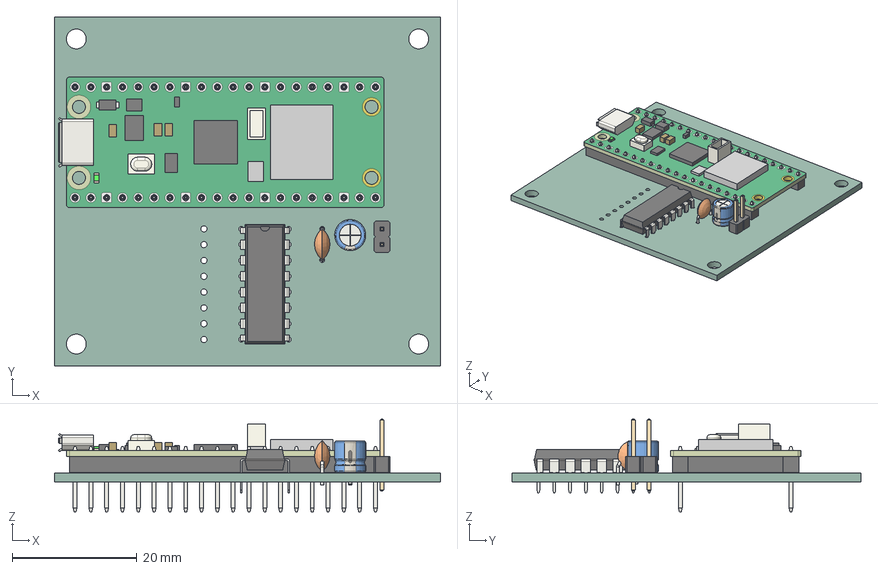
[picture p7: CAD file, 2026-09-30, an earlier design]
boardtempinfo/difftx/archive/revA/fab/difftx.step
62.0 x 56.0 x 14.9 mm
RaspberryPi_Pico_WH_Module_KiCad
RaspberryPi_Pico_Header_DIP-40_H2.54mm_KiCad
CP_Radial_D50mm_P200mm
C_Disc_D50mm_W25mm_P500mm
PinHeader_1x02_P254mm_Vertical
DIP-16_W7.62mm
difftx_PCB

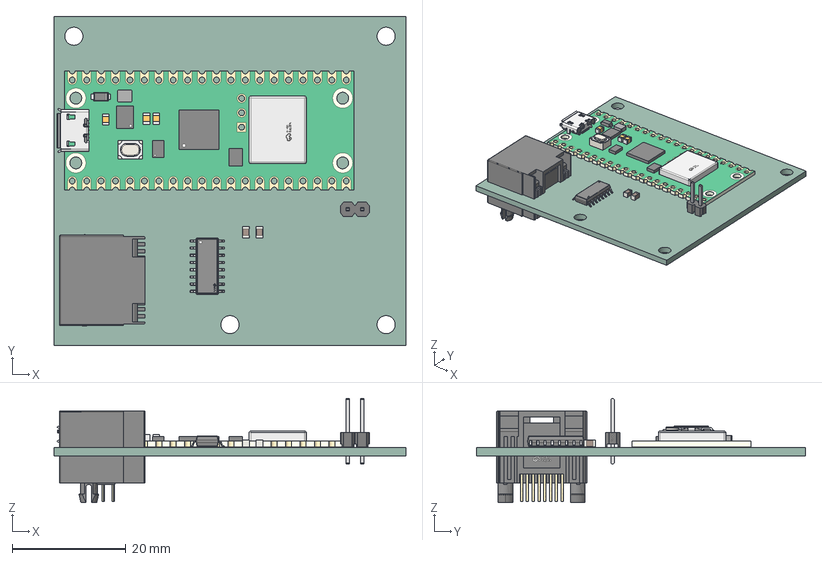
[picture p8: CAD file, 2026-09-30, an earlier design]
boardtempinfo/difftx/archive/revB/fab/difftx.step
62.0 x 58.0 x 18.3 mm
零件23
C_0805_2012Metric x 2
RJ45-TH_RJ-056-1-5
HDR-TH_2P-P2.54-M-LI-1X2P
SOIC-16_L9.9-W3.9-H1.8-LS6.0-P1.27
difftx_PCB

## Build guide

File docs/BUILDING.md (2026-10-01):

# Building PixelPlus

Developer guide for the daemon, web UI, Debian package, SD-card image, Docker image and
PixelPlus Imager. Architecture and contracts: [ARCHITECTURE.md](ARCHITECTURE.md).
End-user installation: [INSTALL.md](INSTALL.md).

```
crates/        Rust workspace: pixelplusd (daemon), pixelplus (CLI), core/output/hw libs
web/           SvelteKit SPA -> web/build (served by pixelplusd from /usr/share/pixelplus/web)
tts/, games/   Python sidecars
packaging/     Debian package: build-deb.sh, systemd units, polkit, avahi, udev, ...
image/         pi-gen stage, pixelplus.txt, first-boot applier, setup hotspot, Imager JSON
imager/        PixelPlus Imager (Tauri 2 + Svelte) with a GUI-free core crate
docker/        Dockerfile + docker-compose.yml for a PC/NAS leader
.github/       CI and release workflows
```

## Prerequisites

| For | Needs |
|---|---|
| Rust | rustup, stable toolchain (MSRV 1.80); `pkg-config libasound2-dev` (ALSA headers for the daemon's audio output; `--no-default-features` builds a lights-only daemon without them) |
| Web / Imager UI | Node 22, pnpm 10 (`corepack enable`) |
| Python parts | Python 3.11+ (`pip install pytest jsonschema` for tests) |
| arm64 .deb on x86 | `sudo packaging/ci/install-arm64-cross-deps.sh` (aarch64 gcc + `libasound2-dev:arm64`) + `rustup target add aarch64-unknown-linux-gnu`, or `cross` (Cross.toml installs the arm64 ALSA headers) |
| .deb | `dpkg-deb`, `device-tree-compiler` (arm64: DPI overlays) |
| SD image | Docker with `--privileged`, ~25 GB disk; on x86: `qemu-user-static binfmt-support` |
| Imager app | Tauri 2 prerequisites: Linux `libwebkit2gtk-4.1-dev libayatana-appindicator3-dev librsvg2-dev libxdo-dev libssl-dev`; macOS Xcode CLT; Windows WebView2 + MSVC |

## Daemon + web UI (development)

```sh
cargo build                                    # workspace
cd web && pnpm install && pnpm dev             # UI on :5173, proxies /api to PIXELPLUS_API
PIXELPLUS_DATA_DIR=./data-dev PIXELPLUS_HTTP_PORT=8080 PIXELPLUS_OUTPUT=sim cargo run -p pixelplus-daemon
```

Environment variables read by `pixelplusd`: `PIXELPLUS_DATA_DIR` (/var/lib/pixelplus),
`PIXELPLUS_WEB_DIR` (/usr/share/pixelplus/web), `PIXELPLUS_HTTP_PORT` (80),
`PIXELPLUS_HTTP_BIND`, `PIXELPLUS_CLUSTER_PORT` (32420; overlay +1), `PIXELPLUS_SENSOR_PORT` (32422),
`PIXELPLUS_HTTPS_PORT` (443, 0 = off), `PIXELPLUS_PUBLIC_PORT` (8081 on 127.0.0.1, 0 = off), `PIXELPLUS_OUTPUT`
(dpi|sim|none|auto), `PIXELPLUS_BOARD` (board override: difftx|difftxlarge|diffsmart|bare-pi|virtual|auto),
`PIXELPLUS_AUDIO` (`none` disables audio output), `PIXELPLUS_SHM_DIR` (/dev/shm),
`PIXELPLUS_TTS_URL`, `PIXELPLUS_GAMES_SOCKET`, `PIXELPLUS_MDNS` (0 = no mDNS), `PIXELPLUS_DEV`;
for tests: `PIXELPLUS_RUN_DIR` (/run/pixelplus), `PIXELPLUS_NETWATCH_STATUS`, `PIXELPLUS_BOOT_DIR`.
On the Pi they come from `pixelplusd.service` and optional overrides in `/etc/default/pixelplus`.
Cluster tuning: `PIXELPLUS_CLUSTER_PEERS` (static peers `host[:port],…` for networks without
broadcast), `PIXELPLUS_CLUSTER_OVERLAY_PORT` (cluster port + 1), `PIXELPLUS_CLUSTER_BIND`,
`PIXELPLUS_CLUSTER_BROADCAST` (0 = unicast to peers only).

`PIXELPLUS_DEV=1` (or `PIXELPLUS_OUTPUT=sim`) enables `GET /api/v1/debug/output`: the last frame
written to this controller's outputs, `{frameNo, atMs, wallMs, sequence: {id, frame}, master,
player, outputs: [{index, pixels, rgb, wire}]}` with base64 `rgb` (rendered, colour order not
applied) and `wire` (what the output backend received), optionally `?outputs=1,2`. With
`PIXELPLUS_DEV=1` on a machine without I²C, the board's sensors are simulated.

### A three-node cluster on one machine

`scripts/dev-cluster.sh` runs a leader (difftxlarge) and two followers (difftx), each with its
own data directory, HTTP port and UDP ports, finding each other through
`PIXELPLUS_CLUSTER_PEERS` on 127.0.0.1 (broadcast and mDNS off), simulated output, no audio:

```sh
cargo build -p pixelplus-daemon && (cd web && pnpm build)
scripts/dev-cluster.sh start [--fresh]   # leader http://127.0.0.1:18080, followers :18081 / :18082
scripts/dev-cluster.sh status            # PIDs, URLs, /public/health
scripts/dev-cluster.sh logs [leader|f1|f2]
scripts/dev-cluster.sh restart f1        # or: kill leader (SIGKILL, like a power cut)
scripts/dev-cluster.sh stop
```

State and logs live in `PP_CLUSTER_DIR` (default `./.dev-cluster`); `PP_BIN`, `PP_WEB_DIR`,
`PP_HTTP_BASE`, `PP_CLUSTER_BASE` and `PP_AUDIO` change the binary, UI, ports and leader audio.
A fresh cluster starts unconfigured: open the leader and run the setup wizard, choose
"follower" on the other two, then adopt them under **Controllers**.

### End-to-end tests against the real daemons

```sh
node scripts/e2e/run.mjs            # fresh cluster in a temp dir, whole scenario, then stop
node scripts/e2e/run.mjs --keep     # leave the cluster running with the e2e show
cd web && pnpm test:real            # Playwright: every page + real button clicks, desktop & phone
PIXELPLUS_E2E_URL=http://127.0.0.1:18080 pnpm vitest run src/lib/api/contract.test.ts
```

`run.mjs` (Node ≥ 22.15, no dependencies) drives the HTTP API like a user would: setup wizard,
discovery and adoption, xLights import (`crates/pixelplus-core/testdata/xlights_2025_*.xml`),
a generated zstd `.fseq` with a known pattern (every prop a solid colour that changes each
second; its first pixel encodes the frame number) plus a WAV, byte-for-byte checks of the
followers' `.ppseq` slices, a playlist started by the schedule, frame-accurate sync of all three
nodes through `/debug/output` (±1 frame, every pixel compared), test patterns, fault finder,
blackout, brightness, live looks, overlays, song requests, snapshots, health, power, sensors,
password/login, a follower restarted mid-show, a leader crash, live prop changes and
remove/re-adopt. `pnpm test:real` (`web/playwright.real.config.ts`) walks every page against the
running leader (no console errors, no failed requests) and saves screenshots to `$SCREENS_DIR`.
The contract test compares every GET endpoint's JSON shape with the demo backend the UI is built on.

## Debian package

```sh
packaging/build-deb.sh --arch amd64                # native
packaging/build-deb.sh --arch arm64                # cross (see below)
packaging/build-deb.sh --arch arm64 --bin-dir target/aarch64-unknown-linux-gnu/release --web-dir web/build
```

Output: `dist/pixelplus_<version>_<arch>.deb`. The version is the workspace version, plus
`~git<date>.<sha>` for untagged commits.

**Cross-compiling for arm64** – the script picks, in order: `cross` (Docker-based;
old glibc, so binaries run on Bookworm and Trixie), or the Debian/Ubuntu cross gcc. For
the latter it sets `CARGO_TARGET_AARCH64_UNKNOWN_LINUX_GNU_LINKER`,
`CC_aarch64_unknown_linux_gnu`/`AR_…` (needed by `zstd-sys`) and `PKG_CONFIG_ALLOW_CROSS` /
`PKG_CONFIG_LIBDIR` for the arm64 ALSA headers (`alsa-sys`, via cpal); install both with
`sudo packaging/ci/install-arm64-cross-deps.sh` (Ubuntu: adds the ports.ubuntu.com arm64
sources). Plain `cargo build|check --target aarch64-unknown-linux-gnu -p pixelplus-daemon`
works too once those are installed: `.cargo/config.toml` sets the same linker, `CC`/`AR` and
target-scoped `PKG_CONFIG_*` variables (values already in the environment win). Build on the *oldest*
distribution you target (Ubuntu 22.04 / Debian Bookworm) because glibc is only forward
compatible.

### Package layout

| Path | What |
|---|---|
| `/usr/bin/pixelplusd`, `/usr/bin/pixelplus` | daemon, CLI |
| `/usr/share/pixelplus/web/` | web UI |
| `/usr/lib/pixelplus/firstboot/` | `pixelplus.txt` applier (`firstboot.py`, `pptxt.py`, `nmconn.py`); `/usr/sbin/pixelplus-firstboot` |
| `/usr/lib/pixelplus/netwatch/` | Wi-Fi watchdog + setup hotspot + captive portal |
| `/usr/lib/pixelplus/games/` | games sidecar (Python, system interpreter) |
| `/usr/lib/pixelplus/overlays/*.dtbo` | DPI overlays (arm64); postinst copies them to `/boot/firmware/overlays/` |
| `/usr/lib/pixelplus/pixelplus-helper` | root helper (see below) |
| `/usr/lib/pixelplus/tts-capable` | `ExecCondition` for the TTS sidecar (Pi 4/5 ≥ 2 GB, amd64) |
| `/usr/share/pixelplus/pixelplus.txt.template` | the commented `pixelplus.txt` |
| `/usr/lib/systemd/system/` | `pixelplusd`, `pixelplus-tts`, `pixelplus-games`, `pixelplus-firstboot`, `pixelplus-reapply.{path,service}`, `pixelplus-netwatch`, `pixelplus-helper@`, `pixelplus-update-verify` (boot-time end of an interrupted update), `pixelplus-cloudflared{,-quick}` (remote access) |
| `/usr/share/pixelplus/keys/*.pub` | minisign keys signed updates must be signed with (`packaging/keys/`) |
| `/var/cache/pixelplus/{staged,rollback}`, `/var/lib/pixelplus-helper` | root-only: staged and kept (rollback) packages, the pending-update marker |
| `/usr/share/polkit-1/rules.d/50-pixelplus.rules` | what the `pixelplus` user may do |
| `/etc/avahi/services/pixelplus.service` | `_http._tcp` on port 80 (`_pixelplus._tcp` is published by pixelplusd, see below) |
| `/usr/lib/sysctl.d`, `/usr/lib/udev/rules.d`, `/usr/lib/tmpfiles.d`, `/etc/logrotate.d` | UDP buffers, device groups, `/run/pixelplus`, log rotation |
| `/usr/share/pixelplus/appliance/` | NetworkManager configs, linked into `/etc` only on appliances |

### Security model (decided)

`pixelplusd` runs as the **unprivileged system user `pixelplus`** with supplementary
groups `video render i2c gpio spi audio netdev dialout pixelplus-overlay` and only two
capabilities: `CAP_NET_BIND_SERVICE` (port 80) and `CAP_SYS_NICE` (the output thread switches
itself to `SCHED_FIFO`; `LimitRTPRIO=95`, `LimitMEMLOCK=infinity`). It is sandboxed
(`NoNewPrivileges`, `ProtectSystem=full`, `ProtectHome`, `PrivateTmp`, `UMask=0027`). Privileged
operations go through system services, authorised by polkit for that user only, and only for
what it uses (`packaging/polkit/50-pixelplus.rules`: NetworkManager `network-control`,
`settings.modify.system/own`, `wifi.scan`, `enable-disable-wifi`; logind reboot/power-off;
hostnamed; timedated `set-timezone` — not `set-time`, NTP keeps the clock):

| Operation | How |
|---|---|
| Wi-Fi scan/connect, Ethernet settings | NetworkManager D-Bus (`org.freedesktop.NetworkManager.*`) |
| Reboot / power off | logind (`org.freedesktop.login1.reboot`, `power-off`) |
| Hostname, time zone, NTP | hostnamed (`hostnamectl --static --transient set-hostname`) / timedated (`timedatectl set-timezone`); avahi follows via `avahi-set-host-name` (netdev group) |
| Start/stop/restart `pixelplus-{tts,games,netwatch}`; restart `pixelplusd` | systemd `manage-units` |
| Board boot config, updates, SSH on/off, re-apply `pixelplus.txt`, Wi-Fi country, `/etc/hosts` | `systemctl start --no-block pixelplus-helper@<verb>.service` (root oneshot, whitelisted verbs) |
| Board EEPROM read/write | `/dev/i2c-1` (group `i2c`, `I2C_RDWR` works even while at24 is bound); the at24 sysfs file only if it is accessible. `new_device` (root) is never used |
| Update check | signed release index (`pixelplus-<channel>.json`, below); without a signing key in the build `apt-cache policy pixelplus`, the package lists refreshed by the helper's `refresh-index` verb (at most every 6 h; the image turns apt's own daily timers off) |
| Install / roll back updates | helper `update-stage`, `update-commit`, `update-rollback`, `update-verify` (re-verify signatures as root, health gate) |
| Tailscale, Cloudflare Tunnel | helper `tailscale-*`, `cloudflared-*` (secrets through 0600 files, never argv) |

**Sidecars run as their own users, without polkit rights.**

| Service | User / groups | Sees of `/var/lib/pixelplus` | Talks to pixelplusd |
|---|---|---|---|
| `pixelplus-games` (internet-facing web page on :8088) | `pixelplus-games`, primary group `pixelplus-overlay`, `audio` | only `games/` (`TemporaryFileSystem` + `BindPaths`; 2770 `pixelplus:pixelplus-overlay`, setgid) | HTTP on loopback with the local token (below); control socket `/run/pixelplus-games/games.sock` (its `RuntimeDirectory`, 0770 → pixelplusd via the group); overlay buffers in `/dev/shm` (0660, group `pixelplus-overlay`) |
| `pixelplus-tts` (loopback :7081) | `pixelplus-tts`, `pixelplus` (to read music beds) | only `media/` (read-only) and `tts/` (its own) | pixelplusd calls it |

The **local token** replaces the old `X-PixelPlus-Local: 1` loopback trust: pixelplusd writes a
random token to `/run/pixelplus/local-token` at every start (0640, group `pixelplus-overlay`); the
games sidecar sends `X-PixelPlus-Local: <token>` (re-reading the file after a 401). pixelplusd
accepts it only from loopback, never together with proxy headers (so a reverse proxy or tunnel on
the Pi can't be used to reach the API), and only for the sidecar's routes (show, player
pause/resume/stop, overlays, events) — no settings, network, SSH or updates. The show it reads
has its secrets redacted.

**Cluster keys** are per follower and authenticate only cluster calls (ARCHITECTURE §7.5): no
bearer key on the wire, signed requests with replay protection, X25519 at adoption, clear rules
for who may adopt a controller (a leader only after its owner chose *Join another show*).

**Browser side** (ARCHITECTURE §8): Host allow-list against DNS rebinding (tunnel / own domains
under Settings → Security → *Other names for this controller*), `X-PixelPlus-Request: 1` on every
state-changing call against CSRF, WebSocket origin check, CSP with the UI's inline-script hashes,
`nosniff`, no framing, write-only SMTP/MQTT passwords, sign-in throttling (6+ character
passwords; Argon2 on at most two blocking threads), song-request limits per real client address
(forwarding headers only from this machine or `settings.security.trustedProxies`), a new
controller can be set up only from the local network, snapshot/WebSocket size limits, `nmcli
--ask` with the Wi-Fi password on stdin (never on a command line), ffmpeg restricted to local
files (`-protocol_whitelist file,pipe`).

**Remote access** (ARCHITECTURE §12.12): tunnels and funnels point at the **public-only
listener** (`127.0.0.1:8081`: song requests, games, `/api/v1/public/*`; everything else 404).
The admin UI is reachable remotely only on explicit opt-in (Tailscale `serve` to the owner's
tailnet, or a Cloudflare admin hostname), only with a password, and its host name is allowed
only while exposed. Any admin API call arriving through a proxy on the Pi (loopback peer with
forwarding headers) is refused while no password is set.

**Trigger links** (ARCHITECTURE §12.18): `/api/v1/hooks/trigger/:id` is the only admin-side
path open without a session or the CSRF header, because a per-trigger secret replaces both: a
256-bit token (`ppt_` + base64url) shown once; only its SHA-256 is stored (`Trigger.tokenHash`,
compared in constant time, never in `GET /show`, can't be set through `PUT /show/settings`). A
token runs only that trigger, through its gates. Host allow-list as for the API; home network
only unless the owner allows the trigger from the internet (then also through the public
listener); `GET` only when allowed per trigger (link previews!), `HEAD` never fires; wrong
tokens back off per address like sign-in (a separate throttle, so a misconfigured doorbell
can't lock the owner out); 10 calls / minute per trigger and address. Home Assistant over MQTT
needs no token (trigger buttons on the command topic).

**Signed updates** (ARCHITECTURE §12.13): minisign (Ed25519) signatures by a key compiled into
the daemon and installed root-owned; verified by the daemon, by followers on packages their
leader serves, and again by the root helper before `dpkg -i`; only newer versions are
installed (rollbacks come from the helper's own root-only copies). A new release must start
healthy within 180 s or the previous package is reinstalled.

**xLights FPP Connect** (WS6, ARCHITECTURE §12.14) is root-mounted, outside `/api/v1`'s guard;
`security::fpp_compat_authorize` replaces the CSRF header for it: off unless enabled, LAN
peers without proxy headers only (never through a tunnel or the public listener), Host
allow-list, reads open, writes need the dedicated upload password as HTTP Basic auth (throttled;
remembered 10 minutes so 16 MiB chunks don't each cost an Argon2 check) or, without a
password, a non-CORS-simple request (`PATCH`, JSON body) that no web page can forge.

**Security review of the feature wave** (second audit):

* *Public-only listener* (`listeners.rs`): at most 256 connections at once (then an
  immediate 503), a page request must arrive within 30 s of connecting, every response
  closes its connection; `/play/…` is bridged to the games controller with
  `Connection: close` (WebSocket upgrades only for `Upgrade: websocket`) and the visitor
  appended to `X-Forwarded-For`. Path tricks (`..`, `//`, `\`, `%2e`, `%2f`, `%5c`) → 404.
* *Visitor addresses*: `CF-Connecting-IP` is believed (sign-in throttle, song requests,
  games per-visitor limits) only while a Cloudflare tunnel set up through PixelPlus is
  the proxy and no Tailscale Funnel shares the public port (`security::cf_trusted`);
  otherwise the proxy's right-most `X-Forwarded-For` entry counts, and the bridge drops
  the header before the games controller sees it. Tailscale Funnel passes unknown
  headers through, so a visitor could otherwise choose their own address.
* *Local CA* (`services/tls.rs`): name constraints never include a bare host name that
  could be a top-level domain (letters only, or `xn--`): a dNSName constraint `christmas`
  would also permit `anything.christmas` on the internet. Such hosts use `<name>.local` /
  `.lan`; an older CA with such a constraint logs a warning (make a new one under
  Settings → Secure connection). Keys are written to fresh 0600 files (never into a
  leftover temp file). A transfer bundle's CA key must match its certificate. No HSTS:
  `:80` stays for followers, sidecars and old bookmarks.
* *xLights FPP Connect*: the legacy `GET /api/file/move/<name>` counts as a write (upload
  password, like the upload); free space is checked before every chunk (not only at
  offset 0, so parallel uploads can't fill the card) and for legacy uploads; unfinished
  uploads are deleted after 24 h; the watch folder copies with `O_NOFOLLOW` on a regular
  file only (a shared folder's file swapped for a symlink is never followed).
* *Sensor nodes*: unauthenticated beacons fill at most 64 "discovered" entries (oldest
  forgotten); `sensor-keys.json` is written to a fresh 0600 file.
* *Signed updates*: an index older than one already seen on that channel is refused
  (`<data>/updates/index-seen.json`: freeze / replay of an old signed index); versions
  only ever go up (daemon and helper), each package is verified by the daemon, by
  followers on what their leader serves, and by the root helper.
* *Root helper*: files from the service user (packages, signatures, Tailscale auth keys,
  tunnel tokens) are read by one `open(O_NOFOLLOW|O_NONBLOCK)` + `fstat` (regular file,
  size-capped, streamed) into a copy created 0600, so no symlink swap between check and
  read and no FIFO can block it.
* *CI*: tag / input values reach workflow scripts through the environment, and the
  release version is checked against `^[0-9][A-Za-z0-9.+-]*$` first.
* *Web*: `/trust?next=` accepts only same-site paths without control characters or
  white space (browsers drop tabs/newlines, turning `/\t/evil.com` into `//evil.com`).

Known limits: the first adoption of a new or released controller is trust-on-first-use (someone
on the LAN could adopt it first; the owner sees who adopted it on the controller's page and in
its log, and can release it). Plain HTTP on the LAN: a sign-in session cookie and MQTT/SMTP
traffic without TLS can be sniffed by someone who can already read the LAN's traffic.
`SameSite=Lax` cookies don't separate ports (the games page on :8088 is "same-site"); the CSRF
header covers that. Sensor nodes are adopted trust-on-first-use too, keep their key in
unencrypted ESP32 flash (physical access reads it), and an unadopted node's `/wifi` and
`/adopt` accept any LAN client. Tailnet devices (100.64/10) count as the local network.
With both a Cloudflare tunnel and Tailscale Funnel on, `CF-Connecting-IP` is ignored
(the right-most `X-Forwarded-For` hop is used). The release index has no expiry (a
seasonal product can go months without a release); the "never older than seen" rule
covers replays after a newer index was seen.

Helper verbs (`packaging/bin/pixelplus-helper`), arguments `:`-separated in the instance name:

* `config-txt:<board>[:<pixels>]` – regenerate `/boot/firmware/pixelplus.conf` via
  `pixelplus config-txt --board <board> [--pixels N]`. **No reboot**; the daemon asks the user
  and then reboots via logind.
* `update` – `apt-get update` + upgrade `pixelplus` (postinst restarts the daemon).
* `refresh-index` – `apt-get update` only (fresh package lists for the update check).
* `ssh-on`, `ssh-off`, `reapply`.
* `wifi-country:<CC>` – `raspi-config nonint do_wifi_country` (or `iw reg set`).
* `hosts` – point `/etc/hosts`' `127.0.1.1` line at the current hostname (after the daemon
  renamed the host through hostnamed) and keep cloud-init from resetting it.
* `update-stage:<ver>`, `update-commit:<ver>`, `update-rollback`, `update-verify`,
  `update-channel:<stable|beta>` – signed updates (ARCHITECTURE §12.13). Versions with `~`
  (`1.3.0~beta1`) arrive systemd-escaped (`\x7e`); the polkit rule allows the backslash and the
  helper validates every argument.
* `tailscale-install`, `tailscale-up`, `tailscale-serve:<on|off>`, `tailscale-funnel:<on|off>`,
  `tailscale-down`, `cloudflared-install`, `cloudflared-quick:<on|off>`, `cloudflared-token`,
  `cloudflared-stop` – remote access (ARCHITECTURE §12.12). Auth keys / tunnel tokens are read
  from 0600 files in `/var/lib/pixelplus/remote/` (never through a symlink, size- and
  format-checked, deleted after use).

Each writes `/run/pixelplus/helper-<verb>.json`
(`{"verb","state":"running|ok|failed","message","updatedAt"}`) for the UI to poll.
`/run/pixelplus` belongs to `pixelplus` (tmpfiles.d), so root writers never write through a
path there: the helper writes in root-only `/run/pixelplus-helper` and renames into place,
netwatch and firstboot create files with `O_EXCL` under random names and rename them.

pixelplusd (`crates/pixelplus-daemon/src/services/platform.rs`) polls the file (only results
newer than the start count; a unit that fails without writing one is detected with
`systemctl is-failed`), forwards progress as `helper` WebSocket messages and toasts, and lists
the latest runs at `GET /api/v1/system/helpers`. Without the helper (development machine,
Docker) the API answers 403 with an explanation; running as root without the package it does
the same work directly.

### mDNS (decided)

avahi-daemon owns the host's mDNS names (`<hostname>.local`) on PixelPlus images. The daemon
publishes its cluster record `_pixelplus._tcp` (TXT `id`, `role`, `board`, `ver`) **through
avahi** (`avahi-publish -s`, D-Bus, package `avahi-utils`), and the static avahi service file
carries only `_http._tcp`, so there is exactly one responder and one `_pixelplus._tcp` instance
per controller. Two responders sharing UDP 5353 is not the problem (avahi and mdns-sd both
use `SO_REUSEADDR`/`SO_REUSEPORT` and receive every multicast packet); the problem is two
responders *claiming the same host name* with different address sets: each treats the other's
answer as a conflict and renames the host (`pixelplus-2.local`). Where avahi isn't running
(Docker, PCs) the built-in `mdns-sd` responder publishes the record; in Docker (the host may
run its own responder) its SRV target is `pixelplus-<id>.local`, never the machine's own name.
`PIXELPLUS_MDNS=0` turns mDNS off (UDP beacons still find controllers).

### Provisioning (`provision.json`)

`firstboot.py` hands the settings only the daemon may apply to
`/var/lib/pixelplus/provision.json` (0600, owner `pixelplus`; keys all optional: `role`,
`uiPassword`, `board`, `source`, `createdAt`; `name`, `showName`, `timezone` are also
accepted). pixelplusd checks for it at startup and every 5 s, applies it exactly like
`POST /api/v1/system/setup` (password hashed with Argon2, role/board set, show defaults
seeded for a leader), and deletes it. A file that can't be applied is deleted too (it holds
a plain-text password) and the reason is shown as a toast and logged.

### CLI contract used by the image

`firstboot.py` runs `pixelplus --json detect` (reads `board.board`: id or `null`, and
`board.rev`), `pixelplus config-txt --board <id> [--pixels N]` (prints the fragment; the
comment `up to N pixels per output` is what pixelplusd reads back from `pixelplus.conf`), and
`pixelplusd.service` runs `pixelplus pins release` after every stop (board from `--board`,
`PIXELPLUS_BOARD`, `/run/pixelplus/board` written by pixelplusd, or the EEPROM; no board =
nothing to do, exit 0). All of them work with `--simulate <board>` on a PC.

### apt repository (optional)

```sh
packaging/apt-repo.sh --repo ./apt --suite stable --key <GPG-KEYID> dist/*.deb   # a release
packaging/apt-repo.sh --repo ./apt --suite beta   --key <GPG-KEYID> dist/*.deb   # also beta
```

creates `apt/dists/<suite>/main/binary-{arm64,amd64}/Packages`, signed `Release`/`InRelease`
and `pixelplus-archive-keyring.gpg`. Host it on GitHub Pages or any HTTPS server; see the
script header for the client `sources.list` line. Settings → Updates → Channel switches the
suite (helper `update-channel`). Controllers on PixelPlus images update through signed
releases instead and don't need it.

### Signed updates (release key handling)

Over-the-air updates only install packages signed with a key listed in
`packaging/keys/pixelplus-release.pub` (compiled into pixelplusd, installed to
`/usr/share/pixelplus/keys/`). Until a key is listed there, builds don't offer signed
updates (apt still works). One-time setup by the maintainer, on a trusted machine:

```sh
sudo apt install minisign
minisign -G -p pixelplus-release.pub -s minisign.key     # choose a strong password
grep '^RW' pixelplus-release.pub >> packaging/keys/pixelplus-release.pub   # commit this
```

Store the **contents** of `minisign.key` (it is itself encrypted with the password) as the
repository secret `MINISIGN_SECRET_KEY` and the password as `MINISIGN_PASSWORD`; keep an
offline backup of both, and never commit `minisign.key`. The release workflow's `sign` job then
signs every `.deb`, writes `pixelplus-stable.json` / `pixelplus-beta.json`
(`packaging/release-index.py`), signs them, checks every signature against the committed
public key, and attaches everything to the (draft) release; publishing the release runs
`ota-publish.yml`, which copies the indexes to the `gh-pages` branch under `ota/` (enable
GitHub Pages for that branch; controllers read `https://<owner>.github.io/PixelPlus/ota`,
overridable with `PIXELPLUS_UPDATE_URL`). Tags like `v1.3.0-beta1` become `1.3.0~beta1` and
go to the beta channel only.

**Rotating the key:** add the new public key as a second line, ship a release signed with the
old key (controllers now trust both), switch the secrets to the new key, and remove the old
line a release later. **A leaked key:** remove it from the file and ship a release signed with
a new key through apt / a new image; controllers that still trust the old key can be offered
packages signed with it until they update. Signing by hand:
`minisign -S -s minisign.key -m pixelplus_1.2.3_arm64.deb` (creates `.minisig`).

## SD-card image (pi-gen)

```sh
packaging/build-deb.sh --arch arm64
image/build-in-docker.sh --deb dist/pixelplus_<ver>_arm64.deb                      # Trixie
image/build-in-docker.sh --deb dist/pixelplus_<ver>_arm64.deb --release bookworm
```

`image/build.sh` clones [pi-gen](https://github.com/RPi-Distro/pi-gen) at a **pinned tag**
(`2026-09-15-raspios-trixie-arm64` / `…-bookworm-arm64`), copies `image/stage-pixelplus`
into it, writes the pi-gen `config`, and builds `stage0 stage1 stage2 stage-pixelplus`
(= Raspberry Pi OS Lite + PixelPlus; stage2's own export is skipped). `--docker` (what
`build-in-docker.sh` does) runs pi-gen's `build-docker.sh`, which needs a **privileged**
container (loop devices, binfmt_misc); on x86 hosts qemu-user-static must be installed.
The release workflow builds on GitHub's native `ubuntu-24.04-arm` runners. Other options:
`--no-tts`, `--no-tts-models`, `--version`, `--out`, `--continue`, `--pigen-ref`.

Output in `image/deploy/`: `pixelplus-<ver>-<release>-arm64.img.xz`, `.sha256`, `.info`,
and `os-list-<release>.json` (Raspberry Pi Imager fragment). The release workflow merges
the fragments into `pixelplus-imager.json`:

```sh
python3 image/rpi-imager/make-os-list.py --merge image/deploy/os-list-*.json --out pixelplus-imager.json
```

### What the stage does

* **00-packages**: NetworkManager, dnsmasq-base, nftables, iw, rfkill, avahi, alsa-utils,
  ffmpeg, i2c-tools, raspi-utils (`pinctrl`), python3-venv/numpy/qrcode, libretro-nestopia,
  polkitd, logrotate.
* **01-pixelplus**: creates `/etc/pixelplus/appliance` (marker that enables the first-boot
  and hotspot services), installs the `.deb`.
* **02-system**: `config.txt` base block (i2c on, UART off, no splash, camera/display
  auto-detect off, **`include pixelplus.conf`** at the end; `vc4-kms-v3d` stays on),
  `cpufreq.default_governor=performance` on the kernel command line (build time only),
  `pixelplus.txt` template and an empty `pixelplus.conf` on the boot partition,
  `i2c-dev` module, volatile journald (32 MB), zram-only swap (`rpi-swap` on Trixie,
  `zram-tools` on Bookworm), Wi-Fi radio enabled, apt timers / wait-online /
  `raspi-config.service` disabled, console banner with the URL, user `pi` **locked**.
* **03-tts** (optional): `/opt/pixelplus-tts/venv` from `tts/` (binary wheels only) and
  the int8 Kokoro model in `/var/lib/pixelplus/tts/models`.

Image defaults: hostname `pixelplus`, locale `en_US.UTF-8`, time zone UTC, SSH off, user
`pi` with a random locked password (unlocked by `ssh_password=`/`ssh_key=` or replaced by a
Raspberry Pi Imager user), cloud-init kept on Trixie.

### Board boot configuration

The Pi's firmware reads `config.txt` → `include pixelplus.conf`. `pixelplus.conf` holds
the output of `pixelplus config-txt --board <id> [--pixels N]` (DPI overlay with the
right geometry, `gpio=…=op,dl`, RTC overlay, Pi 5 USB current…). It is written:

1. on first boot by `pixelplus-firstboot` after `pixelplus --json detect` identified the
   board (or `board=` in `pixelplus.txt`), followed by **one automatic reboot** (loop
   guard: at most 3 consecutive reboots). It is regenerated at boot only if missing, if the
   board changed, or if the card moved to a different Pi model;
2. whenever the daemon needs a different geometry (longest string) or the user picks a
   board in the wizard: `pixelplus-helper@config-txt:<board>:<pixels>`, then a user-confirmed
   reboot.

Older images that wrote a managed block into `config.txt` are migrated automatically.

### First boot / `pixelplus.txt` (image/firstboot)

`pixelplus-firstboot.service` (every boot, before `pixelplusd`, after NetworkManager and
cloud-init's local/network stages) and `pixelplus-reapply.path` (when the file is saved
while running) run `firstboot.py apply`:

1. Parse + validate (`pptxt.py`); problems go to `pixelplus-errors.txt` on the boot partition.
2. If the file's SHA-256 changed since the last run: apply only changed values –
   country (`raspi-config nonint do_wifi_country`), hostname (`hostnamectl`, `/etc/hosts`,
   cloud-init `preserve_hostname`), time zone, Wi-Fi profiles as NetworkManager keyfiles
   (`pixelplus-wifi`, `pixelplus-wifi2`, `pixelplus-ethernet`; secrets never on a command
   line), SSH (`raspi-config nonint do_ssh`), login password/key for uid 1000.
3. Role, UI password and board go to **`/var/lib/pixelplus/provision.json`** (0600,
   owner `pixelplus`) for the daemon; hotspot settings to `/etc/pixelplus/netwatch.json`.
4. Applied secrets are blanked in `pixelplus.txt` (comment `# [applied <date>] …`), and
   the new digest is stored in `/var/lib/pixelplus-system/state.json`.
5. Wi-Fi radio unblocked; board boot configuration as above.

Logs: `/var/log/pixelplus-firstboot.log` and `journalctl -u pixelplus-firstboot`.
Validate a file on your PC: `python3 image/firstboot/firstboot.py check pixelplus.txt`.

**Raspberry Pi Imager compatibility.** Current Raspberry Pi OS uses two customisation
formats: Bookworm images use `firstrun.sh` (Imager adds
`systemd.run=/boot/firmware/firstrun.sh … systemd.unit=kernel-command-line.target` to
`cmdline.txt`; the script runs in its own boot and reboots), Trixie images use cloud-init
(`user-data`, `network-config`, `meta-data` on the boot partition, `init_format:
cloudinit-rpi`). PixelPlus keeps both mechanisms intact: it never edits `cmdline.txt` at
runtime, keeps cloud-init and `userconf-pi`, orders its first-boot unit after them, and
treats empty `pixelplus.txt` values as "leave alone", so Imager's hostname, Wi-Fi (a
netplan-generated NetworkManager profile, which the hotspot logic counts as a known
network), user and SSH survive. The os_list entries advertise `cloudinit-rpi` (Trixie)
and `systemd` (Bookworm) so Imager uses the right format.

### Setup hotspot (image/netwatch)

`pixelplus-netwatch.service` (root, standalone Python, stdlib only):

* **Boot:** online (any Ethernet/Wi-Fi device connected) → nothing to do. Otherwise, after
  `hotspot_timeout` (75 s; 25 s when no Wi-Fi profile exists at all) and with no Ethernet
  → hotspot. **Runtime:** offline for 5 min → hotspot, but at least 10 min when a network was
  connected within the last 30 min (a deauthentication attack has to last that long).
* **Hotspot:** NetworkManager AP profile `pixelplus-hotspot`, SSID `PixelPlus-XXXX` (last 4
  hex digits of the Wi-Fi MAC), WPA2 `pixelplus` by default (or open) until the controller has
  been online once; after that `hotspot_password=` if the owner set one, else a random
  per-device password (`/var/lib/pixelplus-system/netwatch-state.json`, root 0600) written to
  `PIXELPLUS-HOTSPOT.txt` on the boot partition and shown to the signed-in owner under
  Settings → Network (`netwatch.json` is 0640 root:pixelplus) — never open. 2.4 GHz channel 6,
  `ipv4.method=shared` at 10.42.0.1/24. NM's dnsmasq gets
  `/etc/NetworkManager/dnsmasq-shared.d/pixelplus-portal.conf`: every DNS name → 10.42.0.1
  and DHCP option 114 (RFC 8910 captive-portal URL). An nftables table redirects TCP 80
  from the hotspot interface to the portal on 10.42.0.1:8099 and rejects 443 (so phones
  fall back to HTTP probes quickly); pixelplusd keeps port 80 everywhere else.
* **Portal** (`portal.py` + `portal/index.html`, 10 s socket timeout, bounded threads): Apple/Android/Windows/Firefox probe URLs
  and foreign hosts get a 302 to `http://10.42.0.1/`; API `GET /api/status`,
  `GET /api/scan[?rescan=1]` (scan cached before the AP starts – most Pi radios can't scan
  in AP mode), `POST /api/connect {ssid,password,hidden,country}`, `POST /api/stay`.
* **Connect:** reply first, then drop the AP, write profile `pixelplus-portal-<ssid>`
  (WPA3-only networks get `key-mgmt=sae`), `nmcli connection up` (45 s). Failure →
  profile removed, hotspot back with the error shown on the page.
* **Retry:** every 5 min while no phone is associated, stop the AP for ~45 s to let
  NetworkManager rejoin known networks (router came back after a power cut).
* **Ethernet** plugged in → hotspot off.
* Status for the daemon/UI: `/run/pixelplus/netwatch.json`
  (`{state, hotspotSsid, hotspotSecured, portalUrl, lastError, lastJoined, updatedAt}`).

Try the portal page on your PC with fake data:

```sh
python3 image/netwatch/netwatch.py --portal-only 127.0.0.1:8099   # open http://127.0.0.1:8099
```

### Signed-update rollback copy

The stage also copies the installed package (and its `.minisig`, if `image/build.sh` was
given a signed `.deb`) to `/var/cache/pixelplus/rollback/`, so the first signed update can go
back to the image's version without apt or `dpkg-repack`.

### Testing

```sh
python3 -m pytest image/tests          # parser, scrubbing, keyfiles, firstboot (sandboxed), portal, state machine, os_list
RPI_IMAGER_SCHEMA=/path/to/rpi-imager/doc/json-schema/os-list-schema.json python3 -m pytest image/tests/test_os_list.py
shellcheck image/*.sh image/stage-pixelplus/*/*.sh packaging/*.sh packaging/bin/*
node packaging/tests/polkit-rules.test.js
python3 -m pytest packaging/tests    # root helper: verbs, argument checks, symlink safety,
                                     # signed updates (fake dpkg/minisign), tunnels; release index
systemd-analyze verify packaging/systemd/*
```

Nothing in `image/` can boot a real Pi in CI. Before a release, flash the image and check:
first boot with only `pixelplus.txt` Wi-Fi; with Raspberry Pi Imager 2 customisation
(Trixie and Bookworm images); no network → hotspot → portal on iPhone and Android →
join; wrong password → hotspot returns with the error; Ethernet only; board detection +
single reboot on each board; `pixelplus.txt` edit while running.

## Docker image

```sh
docker build -f docker/Dockerfile -t pixelplus .                          # full: + TTS venv + games
docker build -f docker/Dockerfile --build-arg VARIANT=slim -t pixelplus:slim .
docker compose -f docker/docker-compose.yml up -d
```

Multi-stage: `node:22` builds `web/`, `rust:1-bookworm` builds `pixelplusd` + `pixelplus`,
the runtime is `debian:bookworm-slim` with ffmpeg/alsa, user `pixelplus` (uid 1000,
`cap_net_bind_service` file capability for port 80), `tini` as PID 1,
`PIXELPLUS_OUTPUT=none`, `PIXELPLUS_BOARD=virtual`, `PIXELPLUS_AUDIO=none` (set `auto` when
passing `/dev/snd`), volume `/var/lib/pixelplus`, and a healthcheck on the unauthenticated
`GET /api/v1/public/health` (`{"ok", "version", "role"}`); the build stage installs
`libasound2-dev`. The compose file uses host networking
(UDP broadcast + mDNS) and runs TTS/games as optional profiles from the same image
(`games` shares the daemon's IPC namespace for the `/dev/shm` overlay buffers).
`docker/Dockerfile.dockerignore` keeps the build context small. Multi-arch
(amd64 + arm64) images are pushed to `ghcr.io/<owner>/pixelplus` by the release workflow.

## PixelPlus Imager

```sh
cd imager
pnpm install
pnpm dev                    # UI only, in a browser, with a mock backend (nothing is written)
pnpm tauri dev              # the real app
pnpm tauri build            # installers for this OS (src-tauri/target/release/bundle/)
cargo test -p pixelplus-imager-core     # core logic, no GUI deps
```

* `imager/core` (`pixelplus-imager-core`, no Tauri): settings validation + rendering into
  the image's own `pixelplus.txt` (golden file shared with the Python parser:
  `image/tests/fixtures/imager-rendered.txt`; regenerate with `UPDATE_GOLDEN=1`),
  MBR + FAT32 access via the `fatfs` crate (no mounting), streaming `.img.xz`
  decompression (`lzma-rs`, pure Rust), SHA-256 read-back verification, safe drive
  listing (Linux `lsblk`, macOS `diskutil`, Windows `Get-Disk`; never system/boot disks,
  never >1 TB unless `PIXELPLUS_IMAGER_ALLOW_LARGE=1`), per-OS raw device access, GitHub
  release + Raspberry Pi Imager JSON parsing. It also builds `pixelplus-imager-cli`
  (`list`, `customize IMAGE.img SETTINGS.json`, `write JOB.json`).
* **Order of operations:** stream-write the image → flush caches and verify by reading back
  → write `pixelplus.txt` into the FAT boot partition *on the card* through the same raw
  handle (sector-aligned adapter) → sync/eject. (Injecting after verification keeps the
  verification comparable to the published image checksum.)
* **Privileges:** the app re-runs itself as a helper (`pixelplus-imager --helper write
  JOB.json --progress FILE`) with admin rights: Linux `pkexec` (the AppImage file itself
  via `$APPIMAGE`, since root cannot read the user's FUSE mount; the .deb/.rpm ship a
  polkit action for a clear prompt), macOS `osascript … with administrator privileges`
  (writes `/dev/rdiskN`), Windows `requireAdministrator` manifest (the app starts elevated;
  volumes are locked and dismounted before `\\.\PhysicalDriveN` is written). The job file
  (contains the Wi-Fi password) is 0600 in a private temp dir and deleted by the helper as
  soon as it is read; progress is a JSON-lines file; cancel = create `<progress>.cancel`.
* Releases: `tauri-apps/tauri-action` builds Windows (.msi/NSIS), macOS (universal .dmg)
  and Linux (.AppImage/.deb/.rpm). Unsigned builds work but trigger SmartScreen /
  Gatekeeper warnings; add Apple/Windows signing secrets to the release workflow for
  public releases.

## CI

`.github/workflows/ci.yml`: Rust fmt/clippy/test + aarch64 cross build; web check/test/build;
Python tests for `image/`, `games/`, `tts/`; shellcheck, `systemd-analyze verify`, polkit
rule test, overlay compile; Imager core tests on Linux/macOS/Windows and the Tauri app
check; Docker build.

`.github/workflows/release.yml` (tag `v*`): `.deb` for amd64/arm64, SD images (Trixie,
Bookworm) on native arm64 runners, `pixelplus-imager.json`, multi-arch Docker image to
GHCR, Imager installers, the minisign signatures and signed update indexes (job `sign`, see
"Signed updates"), all attached to a draft GitHub release. `.github/workflows/ota-publish.yml`
copies the update indexes to GitHub Pages when the release is published.

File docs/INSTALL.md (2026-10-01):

# Installing PixelPlus

This guide gets a PixelPlus controller onto your network and ready to use. You need:

* a Raspberry Pi **Zero 2 W, 3, 4 or 5** (with or without a PixelPlus board: difftx,
  difftxlarge, diffsmart),
* a **microSD card of 4 GB or more** (8–32 GB recommended, "A1"/"A2" cards boot faster),
* a computer with an SD-card slot or a USB card reader,
* your Wi-Fi name and password, or a network cable.

There are three ways to make the SD card. Pick one:

| | Best for |
|---|---|
| [A. PixelPlus Imager](#a-pixelplus-imager-recommended) | Everyone. Downloads, writes, checks and sets up Wi-Fi in one go. |
| [B. Raspberry Pi Imager](#b-raspberry-pi-imager) | If you already use Raspberry Pi Imager. |
| [C. Any SD-card writer + `pixelplus.txt`](#c-any-sd-card-writer--pixelplustxt) | balenaEtcher, `dd`, or preparing many cards at once. |

Then [start the Pi](#first-start) and [open PixelPlus](#first-run-wizard).
Want the show leader on a PC or NAS instead of a Pi? See [Docker](#running-the-leader-in-docker).

---

## A. PixelPlus Imager (recommended)

1. Download **PixelPlus Imager** for Windows, macOS or Linux from the
   [latest release](https://github.com/tlchandler/PixelPlus/releases/latest)
   (`.msi`/`.exe`, `.dmg`, `.AppImage`/`.deb`).
2. Start it and follow the four steps:
   1. **Image** – the newest PixelPlus is already selected. (You can also pick an
      `.img` / `.img.xz` file you downloaded yourself.)
   2. **SD card** – insert the card; it appears automatically. Only removable drives are
      listed – never your computer's own disks. *Everything on the card is erased.*
   3. **Settings**
      * **Wi-Fi**: network name, password (click *Show* to check it), and your country.
        Leave Wi-Fi empty if you use a network cable or want to set it up from your
        phone later.
      * **Name**: what the controller is called on your network, e.g. `pixelplus-garage`.
        You'll open it at `http://pixelplus-garage.local`. Give every controller its own name.
      * **Role**: *Show leader* for your main controller (exactly one per show),
        *Follower* for every extra controller.
      * **Time zone**: taken from your computer.
      * *Security & remote login (optional)*: a password for the PixelPlus web page, and
        SSH for advanced users.
   4. **Write** – confirm, enter your computer password when asked (writing an SD card
      needs administrator rights), and wait. The card is written, **read back and
      checked**, and your settings are saved on it.
3. When it says *Your SD card is ready*, take the card out and put it in the Pi.

> Windows asks "Do you want to allow this app to make changes?" when PixelPlus Imager
> starts – it needs that to write SD cards. macOS asks for your password when you click
> *Write*; Linux shows a password dialog (pkexec).

## B. Raspberry Pi Imager

PixelPlus can be installed with the official
[Raspberry Pi Imager](https://www.raspberrypi.com/software/) **version 2.0 or newer**:

1. Open Raspberry Pi Imager → **App Options** (gear / "Customisation" menu) →
   **Content Repository** → **Use custom URL** and enter

   ```
   https://github.com/tlchandler/PixelPlus/releases/latest/download/pixelplus-imager.json
   ```

   (or start it from a terminal: `rpi-imager --repo <that URL>`).
2. Choose your Raspberry Pi model, then **PixelPlus (Trixie, 64-bit)**, then your SD card.
3. When asked *"Would you like to apply OS customisation settings?"* choose **Edit
   settings** and fill in hostname, Wi-Fi (SSID, password, country), time zone and
   – if you like – a user name/password and SSH. PixelPlus applies these on first boot,
   exactly like Raspberry Pi OS does.
4. Write the card.

Good to know:

* Raspberry Pi Imager **1.x** cannot customise the *Trixie* image (its settings would be
  silently ignored). Update to Imager 2, or use the *Bookworm* PixelPlus image, or set
  Wi-Fi in `pixelplus.txt` (method C).
* The **role** (leader/follower) and the PixelPlus web password are not part of Raspberry
  Pi Imager: choose them in the browser on first start, or put them in `pixelplus.txt`.
* If you set something in **both** Raspberry Pi Imager and `pixelplus.txt`, the value in
  `pixelplus.txt` wins.

## C. Any SD-card writer + `pixelplus.txt`

1. Download `pixelplus-<version>-trixie-arm64.img.xz` from the
   [latest release](https://github.com/tlchandler/PixelPlus/releases/latest).
2. Write it with any tool, e.g. [balenaEtcher](https://etcher.balena.io/), or on Linux:
   `xzcat pixelplus-*.img.xz | sudo dd of=/dev/sdX bs=4M conv=fsync status=progress`.
3. Take the card out and put it back in. A drive called **bootfs** appears. Open the file
   **`pixelplus.txt`** on it with any text editor (Notepad, TextEdit, …).
4. Fill in what you need and save:

   ```ini
   wifi_ssid=MyHome
   wifi_password=my secret password
   wifi_country=US
   hostname=pixelplus-garage
   role=follower
   timezone=America/Chicago
   ```

5. Eject the card properly, then put it in the Pi.

### Everything `pixelplus.txt` can do

The file on the card has a friendly explanation above every line. In short:

| Setting | Example | Meaning |
|---|---|---|
| `wifi_ssid` / `wifi_password` | `MyHome` / `secret123` | Your Wi-Fi. Case sensitive. Empty password = open network. |
| `wifi_country` | `US`, `GB`, `DE`, `AU` | Country the Pi is used in (legal Wi-Fi channels). |
| `wifi_hidden` | `yes` / `no` | Your network does not broadcast its name. |
| `wifi2_ssid` / `wifi2_password` | | A second network to try (phone hotspot, show site). |
| `hostname` | `pixelplus-garage` | Name on the network → `http://pixelplus-garage.local`. |
| `role` | `leader` / `follower` | Empty = choose in the browser. |
| `timezone` | `America/New_York` | Used by the schedule and sunset times. |
| `board` | `auto`, `difftx`, `difftxlarge`, `diffsmart`, `bare-pi` | Normally `auto` (read from the board's memory chip). |
| `ip_address` / `ip_gateway` / `ip_dns` | `192.168.1.50/24` / `192.168.1.1` / `192.168.1.1` | Fixed IP address (most people leave this empty). `dhcp` = back to automatic. |
| `ip_interface` | `wifi` / `ethernet` | Which connection gets the fixed address. |
| `ui_password` | | Password for the PixelPlus web page (at least 6 characters). |
| `ssh` | `on` / `off` | SSH remote login (user `pi`). Empty = keep as is. |
| `ssh_password` / `ssh_key` | | Password (8+ characters) or public key for SSH. |
| `hotspot` | `on` / `off` | The setup hotspot (below). |
| `hotspot_password` | `pixelplus` | 8–63 characters, or `none` for an open hotspot. If you keep the default, it applies only to the first setup; once the Pi has been online it uses its own password from `PIXELPLUS-HOTSPOT.txt` (and never an open hotspot). |
| `hotspot_timeout` | `75` | Seconds to wait for Wi-Fi at power-on before opening the hotspot. |

Rules:

* **Empty means "leave as it is".** A new card starts with everything empty, so nothing
  is overwritten by accident.
* The file is read **every time the Pi starts** and also when it is saved while the Pi is
  running. Only settings that changed are applied.
* **Passwords are removed from the file once they are applied** (they're stored safely
  on the Pi). You'll see a note like `# [applied 2026-10-01 18:22] Saved on the device…`.
  Type a new password to change it; the Wi-Fi name stays so you can see what is set.
* If something is wrong, the Pi writes **`pixelplus-errors.txt`** next to
  `pixelplus.txt` telling you what to fix. Everything else is still applied.
* Changing the SSID without typing a password means the new network is **open**. To keep
  the saved password, don't change the SSID line.

---

## First start

Put the card in the Pi, connect your PixelPlus board if you have one, and power on.

* The first start takes **1–2 minutes**. If a PixelPlus board is detected the Pi
  **restarts once by itself** to switch on the pixel outputs – that's normal.
* Then open **`http://<name>.local`** in a browser on the same network, e.g.
  `http://pixelplus.local` (or the name you chose).

**`.local` doesn't open?** Some Android phones and older Windows PCs don't support
`.local` names. Look in your router's list of connected devices for the name and open
its IP address instead (e.g. `http://192.168.1.57`). A connected screen also shows the
address on the Pi's console.

### No Wi-Fi? Use the setup hotspot

If a **new** Pi (one that has never been online) can't join a Wi-Fi network within about
a minute (wrong password, network not set, router out of range) **and no network cable is
plugged in**, it opens its own Wi-Fi network:

* **Network name:** `PixelPlus-XXXX` (the four characters are unique to each Pi)
* **Password:** `pixelplus` while you set it up for the first time. Once the Pi has been
  online, the hotspot uses **its own password** instead (so a neighbour can't use it): it is
  written to **`PIXELPLUS-HOTSPOT.txt`** on the SD card (open the card on any computer) and
  shown in PixelPlus under **Settings → Network**. Choose your own with
  `hotspot_password=` in `pixelplus.txt`.

1. On your phone, join **PixelPlus-XXXX**.
2. A *Sign in to network* page opens by itself (if not, open any web page, or go to
   `http://10.42.0.1`).
3. Tap your Wi-Fi network, type its password, check the country, tap **Connect**.
4. The page shows the address to use, e.g. `http://pixelplus.local`. Your phone leaves the
   hotspot; reconnect it to your normal Wi-Fi and open that address after about a minute.

If the password was wrong, the hotspot comes back within a minute and the page tells you
what happened – just try again. Other details:

* **Leave it alone and it fixes itself:** if a known network comes back (e.g. the router
  was still starting after a power cut), the Pi checks every 5 minutes while no phone is
  connected to the hotspot, and rejoins it.
* **Once a Pi has been online** (or it is a controller adopted into your show), a router
  reboot or a Wi-Fi hiccup never turns it into a hotspot mid-show. It keeps trying its
  known networks (every 20 seconds for the first 10 minutes after power-on, then every
  minute) and opens the hotspot only after it has been offline for **30 minutes in a row**
  (and no cable is connected), with its own password (see above). The long wait also means
  someone jamming your Wi-Fi for a while can't make it switch.
* **Use PixelPlus without Wi-Fi:** on the setup page tap *Use PixelPlus without Wi-Fi*,
  stay connected to the hotspot and open `http://10.42.0.1` – handy at a show site with
  no internet. PixelPlus itself never needs the internet.
* Turn the hotspot off with `hotspot=off` in `pixelplus.txt`.

Why a password on the hotspot? An open setup network would let anyone nearby point your
controller at *their* network. The default password is public, so it only keeps out
passers-by; set your own `hotspot_password` if that matters to you.

### Network ports

On your network PixelPlus uses TCP **80** (web page and API), TCP **443** (HTTPS for phone
camera/microphone pages; 8443 in Docker), UDP **32420** (controllers finding and syncing
each other), UDP **32421** (live overlay pictures sent to other controllers) and UDP
**32422** (ESP32 sensor nodes). If you run a firewall between controllers, allow these.
PixelPlus also listens on **127.0.0.1:8081** (only on the controller itself): the public-only
port that remote-access tunnels use (song request page and games, nothing else).
The cluster used UDP 32320 before; that port belongs to FPP / xLights *FPP Connect*, so
all controllers of a show must run the same PixelPlus version (update them together).

## First-run wizard

The first time you open PixelPlus it asks a few questions (anything you already set in
the Imager or `pixelplus.txt` is filled in):

1. **Leader or follower?** Your main controller is the *leader*; it holds the show and the
   music. Extra controllers are *followers*: they show "Waiting to be adopted…" and appear
   on the leader under **Controllers → New controllers found** – click **Adopt**.
2. **Board** – detected automatically from the board's memory chip. If it isn't (e.g. a
   blank chip), pick it; PixelPlus can write the chip for you. Changing the board
   restarts the controller once.
3. **Show name, location and time zone** – used for sunset-based schedules.
4. **What will you use?** – *Essentials* (recommended), *Everything*, or *Let me choose*.
   Features you don't pick stay out of the menus; see
   [Customize what you see](#customize-what-you-see).
5. **Password** (optional) for the web page.

Then import your xLights layout and sequences (see the in-app guide).

## Running the leader in Docker

A PC or NAS can be the show leader (the Pis with boards are followers). Requirements:
Linux host (or NAS with Docker/Container Manager), **host networking** (followers are
found by broadcast and mDNS – this does *not* work in Docker Desktop on macOS/Windows).

```sh
curl -fsSLO https://raw.githubusercontent.com/tlchandler/PixelPlus/main/docker/docker-compose.yml
docker compose up -d                       # PixelPlus on port 80
docker compose --profile tts up -d         # + on-device DJ voices (Kokoro TTS)
```

* Open `http://<nas-address>` (port 80). If port 80 is taken (Synology DSM uses it), set
  `PIXELPLUS_HTTP_PORT=8080` in the compose file or an `.env` file.
* Set `TZ=` to your time zone.
* Show data lives in the `pixelplus-data` volume (`/var/lib/pixelplus`); back it up or use
  PixelPlus snapshots.
* For show music through the NAS/PC speakers, uncomment the `devices: /dev/snd` lines.
* The image runs as an unprivileged user (uid 1000). If you bind-mount a folder instead of
  the named volume, `chown -R 1000:1000` it first.

## Updating

* **Pi:** **Settings → Updates → Update everything** on the show leader. PixelPlus downloads
  the signed release once, checks its signature, and updates the followers first and then
  itself (the lights pause for about a minute). Every controller checks that the new
  version starts properly; if any one doesn't, **all of them go back** to the version they
  had, by themselves, and you get a message. Also there:
  * **Channel** – *Stable* (recommended) or *Beta* (new features first).
  * **Automatic updates** – *Off*, *Tell me* (default) or *Install* inside a daily window
    (10:00–14:00 by default); never while a show plays or within 2 hours of a show window,
    and only when every controller is online.
  * **History** and **Roll back to …** (the previous version, on every controller).

  The SD card never needs to be re-written. Pulling the power in the middle of an update is
  safe: the controller finishes or undoes it when it starts again.
* **Docker:** `docker compose pull && docker compose up -d`.

## Replacing a controller

**A follower died** (bad SD card, fried Pi): flash a new SD card with PixelPlus, put it in the
controller (or a new board), power it up on the same network, and choose *This is a
follower*. On the leader, open **Controllers**, click **Replace…** on the dead controller and
pick the new one. It takes over the old one's name, address name, wiring, props and
sequences in one step and syncs within a minute. A new board whose ID chip is blank is set
up as the old board type automatically. If the old controller ever turns up again it is
listed as *retired* — it can no longer take part; **Release it** to reuse it.

**The show leader died:** you need its **transfer file**. Make one now and after big
changes: **Settings → Updates → Controller transfer file** (or *Replace…* on the leader's
card). It holds the whole show — sequences, music, the followers' keys and the phones'
secure-connection certificate — encrypted with a passphrase you choose (at least 10
characters; without it nobody can open the file, you included). To replace the leader:
flash a new SD card, open the new Pi in the browser and choose **Replace a show leader?
Restore a show from a transfer file** in the welcome screen. The new Pi becomes the leader
under the old name; the followers find it by themselves and phones keep trusting it.
Remote access (Tailscale / Cloudflare) is set up again on the new Pi.

## Remote access (without port forwarding)

**Settings → Remote access** sets up either (or both):

* **Tailscale** – install, **Connect** (open the login link / scan the QR code with your
  phone, or paste an auth key), then:
  * **Admin pages on your tailnet** – `https://<name>.<tailnet>.ts.net` works from your own
    devices signed in to Tailscale. Turn on *MagicDNS* and *HTTPS certificates* in the
    Tailscale admin console (DNS page) first. Needs a PixelPlus password.
  * **Public song request page (Funnel)** – optional: `https://<name>.<tailnet>.ts.net:8443/request`
    for visitors (allow Funnel for the device in the tailnet's access controls).
* **Cloudflare Tunnel** – install, then:
  * **Quick link** – a temporary `https://….trycloudflare.com` address, no account needed; it
    changes when the controller restarts.
  * **Your own address** – create a tunnel in the Cloudflare Zero Trust dashboard, add a
    public hostname (e.g. `lights.example.com`) → `http://localhost:8081`, paste the tunnel
    token and the host name. Optionally an admin hostname → `http://localhost:80`: that puts
    the sign-in page on the internet, so PixelPlus requires a password, and you should protect
    it with **Cloudflare Access** (Access → Applications → self-hosted, email one-time PIN).
  * **Test** checks each address from the outside.

Only the song request page and the games are ever public by default: tunnels point at
PixelPlus's public-only port. The song request page's QR codes follow the public address.
Docker: see `docker/README.md` (compose profile `tunnel`).

* **Remote sign-in alerts** – whenever someone signs in to the admin pages from outside your
  home network (through Tailscale, a Cloudflare Tunnel or another proxy, or straight from the
  internet), you get a *Remote sign-in* alert with the address it came from (in the app, and by
  email / push if alerts are set up in **Settings → Alerts**). If it wasn't you, change the
  password in **Settings → Security**.
* **Fair turns for visitors** – each visitor (one internet address: a household, or a phone
  network's shared address) may request up to **6 songs an hour** (never more than 3 in
  10 minutes), and everyone together up to **60 an hour** (**Settings → Song requests**;
  0 = no limit). In the games, at most **3 phones** from one address wait in line or play at
  the same time (**Games → Game → Phones per visitor in line**). Behind a tunnel PixelPlus
  still tells visitors apart by their real address; forwarded addresses are believed only from
  the tunnel on the controller itself (or a proxy listed in `security.trustedProxies`).

## Home Assistant & doorbells

Let Home Assistant, a video doorbell, a Stream Deck or any other gadget start something on the
show — a surprise on the candy canes when the doorbell rings, "lights off" from a scene.

**With MQTT (simplest for Home Assistant).** Turn on **Settings → Home Assistant & MQTT** with
*Home Assistant discovery*: every trigger that is a *button on the controller* or a *web link*
shows up in Home Assistant as a button called **Trigger: <name>**. Nothing else to set up.

**With a secret link (anything that can call a web address).** In **Settings → Triggers** add a
**Web link** trigger, choose what it does, open **Connect Home Assistant & other devices** and
tap **Make a secret link**. The link and its token are shown **once** (with copy buttons, a QR
code, and the examples below) — copy them right away. The link works even when the web pages
have a password. Anyone who has it can run that trigger (and nothing else), so keep it private;
**Make a new link** replaces it (the old one stops working at once) and **Turn off link**
removes it. Home Assistant's `configuration.yaml`:

```yaml
rest_command:
  pixelplus_doorbell:
    url: "http://pixelplus.local/api/v1/hooks/trigger/<trigger id>"
    method: POST
    headers:
      Authorization: "Bearer ppt_…your token…"
```

then use `action: rest_command.pixelplus_doorbell` in an automation. From a computer:
`curl -X POST -H 'Authorization: Bearer ppt_…' http://pixelplus.local/api/v1/hooks/trigger/<id>`.

* Sending the token in the `Authorization` header is best. Devices that only take one address
  can use `…/hooks/trigger/<id>?token=ppt_…` instead (it may end up in their logs).
* Some doorbells can only *open* a link (GET). Turn on **Allow simple GET links** for that
  trigger — but then a chat app or browser that opens the link by itself to show a preview sets
  it off, so don't paste it into messages.
* By default the link works only on your home network. **Allow from the internet** also lets it
  through your tunnel (Settings → Remote access): `https://<your public address>/api/v1/hooks/…`.
  The first time it is used from a new internet address you get an alert.
* The trigger's limits still apply (wait between runs, at most per hour, when, hours), and it
  is answered with `202` when it ran, `409` when a limit said no (the answer says why), `401` for
  a wrong token (too many wrong tokens from one address and it has to wait), `429` after more
  than 10 calls a minute.
* The panel shows when the link was last used and from where.

## Show features at a glance

Where to find what, once the show is running. Everything is on the show leader's web page.

* **Phones as cameras and microphones (Secure connection)** – phone pages that use the camera
  or microphone need HTTPS. PixelPlus makes its own certificate for your home network: open
  **Settings → Secure connection**, scan the QR code with the phone and follow the steps for
  iPhone or Android on the *Trust this phone* page (once per phone). The certificate only works
  for addresses in your home network.
* **Sync lights to sound** (**Sync to sound** in the menu) – stand where visitors watch, aim
  the phone at the lights and start: it listens to the speakers and watches the lights at the
  same time, then sets the audio delay so the music and the lights land together.
* **Make a light show** (**Sequences & Audio**, on a song) – PixelPlus finds the beats, tempo
  and loud and quiet parts of the song and builds a show for your props in a style you pick
  (classic, candy, rock, calm, party, or *voice* for DJ clips). Re-roll until you like it; it
  is a normal sequence afterwards. **Preview** plays any sequence on your phone's picture of
  the display without touching the lights.
* **Countdown to showtime** (**Playlists → Intro → Countdown**) – a big countdown on the matrix
  with the other props filling up, a tick or a DJ clip, and the first song starting exactly on
  zero. Turn on *Start exactly on time* on the schedule entry to have the
  countdown end right on the minute.
* **Map my yard** (menu) – point the phone's camera at the house; every output blinks its own code,
  and PixelPlus proposes where each prop goes on the Layout page and fixes for swapped or
  reversed wiring (nothing changes until you apply them; a backup is made first). **Check pixel count** on a prop
  counts the pixels actually connected, and **Controllers → Add a receiver** walks you through
  wiring a new receiver one port at a time.
* **Tags and smart playlists** – tag songs (*kids*, *classic*, *new*) on the Sequences page; a
  **Smart** playlist picks tonight's songs by tags and length, skips songs played on recent
  nights and can rotate through your whole library. *Tonight* shows exactly what will play.
* **Seasons** (**Settings → Seasons**) – keep a Halloween and a Christmas show (props, playlists,
  schedule) and switch all of it with one click, or let PixelPlus switch by date.
* **Power** (**Settings → Power**) – tell PixelPlus which supply or fuse feeds which outputs and
  it keeps each within its rating by dimming only what is over budget (in *Warn* mode it only
  tells you). *Late-night dimming* lowers the whole display after a time you choose. The
  dashboard shows a badge while any controller is limiting.
* **Nightly report** (**Reports**, **Settings → Nightly report**) – every morning: how long the
  show ran, songs, requests, problems, temperatures, sync quality and pixels to check, by email
  or push, or only when something went wrong.
* **Upload from xLights** (**Settings → xLights**) – turn on *Let xLights upload here*, then in
  xLights use **Tools → FPP Connect** → **Add FPP** with the leader's address; set *FSEQ type* to
  *V2 zstd*, tick *Media*, and upload. A drop folder on the controller works too.
* **Sensors and surprises** (**Settings → Sensors**, **Settings → Triggers**) – ESP32 boards in
  the yard with motion sensors, buttons, light beams or door contacts
  (`firmware/esp32-sensor/README.md` explains building and flashing one). Power it, join its
  *PixelPlus-Sensor-XXXX* hotspot to give it your Wi-Fi, then **Add** it under *New sensors
  found*. A trigger such as "Driveway · Motion 1 → a sparkle on the candy canes" layers a short
  surprise over the song that is playing; **Test** tries it without walking outside. The
  sensor talks to the leader on UDP port 32422 with its own key, so nobody else on the network
  can fake it.

## Customize what you see

PixelPlus can do a lot, and most displays use only part of it. **Settings → Features** (also
*Customize what you see* at the bottom of the menu, or under **More** on a phone) turns
optional features on and off for this show, so the rest of the interface shows only what you
actually use:

* **Presets** – *Essentials* (props, controllers, sequences, playlists and schedule, plus
  Effects & looks, Layout & preview, the fault finder, pixel count check, receiver wizard and
  the power limiter), *Everything*, or *Custom* (your own mix). New shows start with the choice
  from the setup wizard; a show from an older version keeps everything on.
* **Groups** – *Show extras* (DJ Studio, Effects & looks, Light shows from music, Smart
  playlists & tags, Countdown, Seasons, Song requests, Games), *Setup tools* (Layout & preview,
  Fault finder, Pixel count check, Receiver wizard, Map my yard, Sync to sound, Phone trust
  (HTTPS)) and *Running the show* (Nightly report, Alerts, Power limiter, Buttons & triggers,
  Sensor nodes, Surprises, Home Assistant & MQTT, Remote access, Upload from xLights). Each
  shows what it's used for right now ("4 clips · used in 2 playlists").
* **Some features need others** – *Map my yard* and *Sync to sound* need *Phone trust (HTTPS)*;
  *Sensor nodes* and *Surprises* need *Buttons & triggers*. Turning one on turns on what it
  needs; turning one off turns off what needs it (PixelPlus tells you first).
* **Nothing is deleted.** A feature that's off disappears from the menus, pages, dashboard and
  playlist editor, its background work stops (MQTT disconnects, games close, tunnels stop
  answering, the sensor port closes, the power limiter and nightly report pause) and playlist
  items of its kind (DJ clips, countdowns, looks, game invites) are **skipped** during the show
  and noted in the journal. Turn it back on and everything is exactly as you left it.
* Turning off the **Power limiter** also turns off its protection of fuses and supplies, and
  turning off **Remote access** makes the show unreachable from outside your home network
  (your tunnel settings are kept). **Updates**, **Backups** and the core pages are always there.

Opening the address of a feature that's off shows a short explanation with a **Turn on**
button; its public pages (song requests, games) answer "not available" to visitors.

## Troubleshooting

| Problem | What to do |
|---|---|
| Can't find `http://pixelplus.local` | Wait 2 minutes after power-on. Try the IP address from your router. Make sure your phone/PC is on the same network (not a guest network). |
| Two controllers with the same name | The second one becomes `pixelplus-2.local`. Give each its own `hostname=`. |
| Hotspot doesn't appear | It only opens when there is no working network **and** no cable. Unplug the cable, wait ~75 s. Pi 3/Zero 2 W: 2.4 GHz only. |
| Wi-Fi network not listed on the setup page | 5 GHz networks are invisible to Pi Zero 2 W / Pi 3 (older ones). Use *Other network* for hidden networks. |
| Settings in `pixelplus.txt` ignored | Look for `pixelplus-errors.txt` on the card, and `/var/log/pixelplus-firstboot.log` on the Pi. |
| Pixels don't light | Check the board was detected (Controllers page). Run *Test* on a prop. See the board's README. |
| End of a long string stays dark | The pixel output's string length is set when the controller starts. The Dashboard / Controllers page shows **Apply & reboot** when a string got longer than that. |

Advanced: log in with SSH (`ssh pi@pixelplus.local`, after setting `ssh=on` and
`ssh_password=`, or turning SSH on in **Settings → Security**), then `pixelplus doctor`, `journalctl -u pixelplusd -f`,
`journalctl -u pixelplus-netwatch`.

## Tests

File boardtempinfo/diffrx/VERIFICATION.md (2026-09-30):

# Chandler 4D/8P Differential Receiver v1.00 (diffrx rev C) — verification record

**diffrx** is the receiving half of the pair whose transmitter is `../difftx` (the FPP Remote pHAT).
One cat5 in, four WS2811 pixel data outputs, eight power-injection outputs, and a 12 V 30 A distribution
bus with a main fuse and a resettable fuse per output — so the board *is* the marine fuse panel, and the
supply cable lands on it directly.

**Rev C adds everything the board can do without an MCU on it**: a trip LED across every fuse, an
NTC/comparator fan thermostat with an over-temperature alarm, a reverse-polarity LED, two I²C
temperature sensors on a header, test points, a bleeder and zip-tie strain relief. Nothing added needs
firmware, and nothing added is in the path of the pixel data.

Generated files: `diffrx.kicad_sch` / `diffrx.kicad_pcb` (from `gen_sch.py` and `gen_pcb.py`),
`jlcpcb/` (gerber zip, BOM, CPL from `export_jlc.py`), renders `render_*.png`.
`fetch_parts.py` pulls the JLCPCB parts into `jlc/`; `verify.py` reads the finished board back;
`silkcheck.py` sweeps the silkscreen.

## Port 3 polarity fix (2026-09-29)

**J14 port 3 is now pin 5 (+) / pin 4 (−), the Falcon standard.** Before this fix, the board had 4 (+) / 5 (−), copied from difftx
rev D. On 2026-09-29, a PixelController SRx1 v5.01 fed by difftx rev D showed that assignment was reversed: port 3 sparkled
white and ignored data, and a cable with pins 4 and 5 swapped at one end fixed it. (Source for the pinout: Dan Kulp,
"blue (5, 4) is for port 3", https://falconchristmas.com/forum/index.php?topic=15638.0. See also the repo `CLAUDE.md`.)

- Schematic: the J14 pin 4 and 5 labels are swapped (pin 4 = P3N, pin 5 = P3P), and the notes are updated.
- Board (`patch_port3.py`, mirrored in `gen_pcb.py`): P3P drops through a new via at (13.0, 50.51) and runs on B.Cu
  between pads 4 and 6 to pad 5 (0.2 mm track, 0.22 mm to each pad). P3N takes an F.Cu hop from (12.0, 49.49) to pad 4.
  The silkscreen now reads `P3=5/4`.
- Checks: ERC 0; DRC with `--schematic-parity --refill-zones` gives 0 violations, 0 unconnected and 0 parity issues.
  All-severity results are unchanged apart from the expected `lib_footprint_mismatch` warnings. `jlcpcb/` has been re-exported.
- **Compatibility:** this board now matches Falcon transmitters. Paired with a **difftx rev D**, port 3 is inverted, so use a
  lead with pins 4 and 5 swapped at one end (the same lead that makes rev D work with Falcon receivers).
- A backup of the board before this fix is in `../_backups/`.

## What changed from rev B

| Rev B | Rev C |
|---|---|
| Bolt-down MIDI main fuse, hand-fitted, in neither BOM nor CPL | **Keystone 3557-2 ATO holder** (C352820), machine-placed, takes a standard 30 A ATO blade fuse |
| Nothing said which output had tripped | A **red LED and a 4.7 k across every fuse** — dark in normal operation, lit at ~2 mA once it opens |
| No thermal sensing of any kind | **NTC + LM2903**: fan on at ~43 °C, **OVER TEMP** LED at ~65 °C. No firmware |
| No fan provision | Fused, switched **12 V fan output** on the left edge |
| No way to read board temperature | Two **LM75B** sensors on an I²C header, powered from the header's **VIO** |
| A reversed supply just looked dead | **REVERSED** LED across the FET bank |
| No test points, no bleeder | Eight test points and a 10 k bleeder across C1 |
| Pigtails pulled directly on the screws | **Fourteen 3 mm zip-tie holes** |
| Two full-width F.Cu +12 V bars | One island per fuse, which opens a 6 mm routing lane between terminals |
| Vias at 0.15 mm annular ring (JLCPCB's *absolute* minimum) | All 211 vias at **0.20 mm**, their recommended figure |
| `min_hole_clearance` 0.25 mm, looser than the fab | **0.30 mm**, stricter than JLCPCB's 0.28 mm |
| Red LEDs carried the green LED's `LCSC Part` property from the library | Both LCSC fields now agree on every part |

The board stays **130 × 100 mm**. Part count goes from 79 to 152 footprints (126 of them placed) and the BOM from 23 to 34 lines.

## Automated checks (KiCad 10.0.6, 2026-09-20)

| Check | Result |
|---|---|
| `kicad-cli sch erc --severity-error --severity-warning` | **0 violations** |
| `kicad-cli pcb drc --schematic-parity` | **0 unconnected, 0 schematic parity issues**; 66 `lib_footprint_mismatch` warnings, all expected (see below) |
| router | **0 routing failures** |
| `verify.py` read-back of the *saved* board | matches every table below; ratsnest 0 |
| `silkcheck.py` (silk vs silk, silk vs pads, silk vs board edge) | **0 / 0 / 0** |
| 3D renders top / bottom | inspected |
| adversarial design review | 1 blocker, 1 wrong footprint, 4 false claims in this file — all fixed |

### The adversarial review, and the blocker it found

Rev C went through a second skeptical review. It found **one blocker that would have killed the fan
outright**, plus a wrong part footprint and four false claims in this file. All are fixed below.

**BLOCKER — D8, the fan flyback diode, was fitted backwards.** The SS34 symbol has **pin 1 = cathode**,
and the footprint's polarity band is on the pad-1 side. The board had the cathode on the switch node and
the anode on the fused +12 V. That is not merely a useless flyback — it is a **forward-biased diode
straight across the fan supply every time Q5 turns on**. The loop is F13 (0.30 Ω) + the diode (~0.5 V) +
the FET (<32 mΩ), so roughly 20–35 A of inrush, past the AO3400A's 30 A pulsed rating, and F13 trips in
single-digit milliseconds and stays tripped. The fan would never have run — and it would have failed at
precisely the moment the board wanted cooling, with nothing to indicate why.

Every other diode in the generator (D1, D2, D7) is correctly wired pin 1 = cathode, so this was a
transcription slip rather than a misunderstanding.

It survived the first round because **`verify.py` was wrong in the same direction**: it hard-coded
`("D8", "1", "flyback anode")`, so the read-back printed a confident "D8.1 /FANM flyback anode" and
confirmed the bug. A check that can agree with the fault it exists to catch is worse than no check at
all. `verify.py` now reads the pin *names* out of the netlist and asserts the cathode is on `/FAN12`,
so it cannot make the same mistake twice.

**Also fixed:** R27 was C25804, a **0603** part, placed on an 0805 land — the same class of error as the
R34 one found earlier, and a tombstone risk. It is now on the 0603 land and merges into the existing
10 k line, taking the BOM from 34 rows to 33.

### Two things the first pass found that were wrong before

**The DRC rules were not being enforced.** `gen_sch.py` writes the tightened JLCPCB limits into
`diffrx.kicad_pro`. `min_connection` had gone back from 0.2 to **0.0**, `min_via_annular_width` from
0.15 to **0.1**, and `min_text_height` from 1.0 to **0.8**, so several DRC runs passed against looser
rules than intended.

The culprit is **`pcbnew.SaveBoard()` at the end of `gen_pcb.py`**, which writes the *bound project file*
from the board's in-memory design settings — overwriting whatever `gen_sch.py` had put there with
KiCad's defaults for every constraint the board object did not carry. Exactly the three that survived
(clearance, track width, edge clearance) were the three `gen_pcb.py` was already setting. The fix is
therefore to set **all** of them on `board.GetDesignSettings()` before the save, which is now done.

Two corrections to what an earlier draft of this file claimed:

- It is **not** `kicad-cli` that resets the project. Running `pcb drc` and `sch erc` and diffing the
  rules dict shows no change in KiCad 10.0.6.
- The constraints do **not** "live in the board file". KiCad does not serialise them into
  `.kicad_pcb` at all — load the board alone in an empty directory and every one reads back as a
  default. They live in `.kicad_pro`; setting them on the board object matters only because
  `SaveBoard()` writes that file. `verify.py` now reads the JSON directly and compares it against the
  intended values, so it is checking the thing it claims to check:

| Constraint | mm | | Constraint | mm |
|---|---|---|---|---|
| MinClearance | 0.200 | | HoleClearance | 0.250 |
| MinConn | 0.200 | | HoleToHoleMin | 0.250 |
| TrackMinWidth | 0.200 | | SilkClearance | 0.150 |
| ViasMinSize | 0.600 | | MinSilkTextHeight | 1.000 |
| ViasMinAnnularWidth | 0.150 | | MinSilkTextThickness | 0.150 |
| MinThroughDrill | 0.300 | | CopperEdgeClearance | 0.300 |

`min_hole_clearance` is **0.30 mm**, deliberately stricter than JLCPCB's own 0.28 mm PTH-to-track, so
the board cannot pass something the fab would reject.

`MinResolvedSpokes` is deliberately 1. It guards against a pad hanging off a zone by a single thermal
spoke, which matters when that zone is the pad's only connection. Here it is not: every ground pad also
lands on the solid In1 plane, and the B.Cu fill uses thermal relief purely so bottom-side pads stay
hand-solderable.

**The maze router could finish a track short of a round pad.** Its target-cell test used the pad's
*bounding box*, and a round pad's bbox corners lie outside the copper by (√2−1)·r — 0.37 mm on the
1.8 mm through-hole fuse pads, more than a grid step. A path allowed to end on a corner cell stopped in
bare laminate while the router believed it had arrived. It now asks the pad itself (`pad.HitTest`).
This is fixed in `grid_router.py` and applies to the transmitter board too.

### The 66 expected DRC warnings

`lib_footprint_mismatch` fires because this board deliberately strips the silkscreen outline from the
terminals, fuses, jack, I²C header and every passive. Those outlines tell an assembler nothing the port
labels do not, and rev C needs the room. The gerbers come from the board file, so the libraries not
matching has no manufacturing effect. It cannot be silenced from the project file, because — as above —
`kicad-cli` resets that file.

## Board

130 × 100 mm, 3 mm corner radius. Four M3 holes, 3.2 mm, at (4, 4) (126, 4) (4, 96) (126, 96), each with
a copper keepout so a steel screw cannot reach the +12 V plane.

**Four layers, 1 oz copper on all four.** This is not JLCPCB's 4-layer default, which is 1 oz outer and
**0.5 oz inner** — and the inner layers carry the 30 A. The stack-up is in the board file and in
`diffrx-job.gbrjob`; confirm it on the order form anyway.

| Layer | Filled | Role |
|---|---|---|
| F.Cu | — | components, signal routing, and the power islands below |
| In1.Cu | 11789 mm² | solid GND plane |
| In2.Cu | 11701 mm² | solid +12 V plane — this is what feeds the twelve output fuses |
| B.Cu | 9765 mm² | GND fill (thermal relief) plus signal routing |

F.Cu power islands: twelve `12V_top*` / `12V_bot*` islands of 38.6 mm², one per fuse, in parallel with
the In2 plane; `GND_sources` 252 mm² at the FET sources, stitched to In1 with **24** vias (an earlier
draft said 51 — that was the count of every GND via on the board, not the ones in this island). 30 A
over 24 vias is 1.25 A each.

Two islands have no inner plane behind them, because they are on the *supply* side of the protection and
every plane is on the protected side. Both are carried on **both outer layers and stitched**:

| Island | F.Cu | B.Cu | stitching vias | carries |
|---|---|---|---|---|
| `/12VIN` | 525 mm² | 525 mm² | 12 | J1 positive → F0 |
| `/GNDIN` | 660 mm² | 660 mm² | 25 | J1 negative → the four FET drains |

`/GNDIN`'s stitching used to be a single row at y = 64.5, which meant the B.Cu half of the island
reached the FET drains at y = 59.29 through only the eight vias nearest them, at about 1.9 A each. A
second row of nine at y = 61.5 now sits directly under the drains.

## Can this really carry 30 A? — the arithmetic

IPC-2221, 1 oz = 35 µm = 1.37 mil, external *k* = 0.048, internal *k* = 0.024:

| Conductor | Geometry | Current for a 10 °C rise | Rise at 30 A |
|---|---|---|---|
| In2 +12 V plane | internal, ~128 mm wide | 40 A | under 10 °C |
| `/12VIN` islands | two external layers, 21 mm wide | ~43 A combined | under 10 °C |
| `/GNDIN` islands | two external layers, 10 mm wide | ~25 A combined | **~15 °C** |

`/GNDIN` is the tightest conductor on the board and the reason it is on two layers — on one, IPC-2221
gives 30 A as a **70.6 °C** rise (an earlier draft said 45 °C, which was wrong). IPC-2221 assumes an
isolated trace in still air; both islands sit 0.21 mm above a solid ground plane, so the real figures
are lower. Note that these are raw IPC-2221 numbers throughout — no plane-proximity correction has been
applied to any of them.

## Power budget

A 12 V WS2811 bullet draws about 60 mA (0.72 W) at full white. 800 nodes on one line is 48 A; four such
lines is 192 A, six times the supply. **12 V × 30 A = 360 W is the limit**: about 500 nodes at full
white, or roughly 3200 at the 15–20 % average a real sequence runs at.

That 15 % on a full 800-node line is 7.2 A — more than one MF-R600 will hold. It does not have to: each
data port has **three** fused feeds (the data terminal plus two injection taps), so 7.2 A arrives as
roughly 2.4 A per fuse, and the port's total fused capacity is 18 A.

## Fusing

### F0 — main fuse

**Keystone 3557-2** (LCSC C352820), a pre-assembled two-receptacle PCB holder with four solder pins,
30 A / 500 V, ~$0.96 at quantity, ~4,950 in stock, and JLCPCB wave-solders it. It takes a **standard ATO
blade fuse** — the ones in every auto parts shop.

> **Fit a 30 A ATO fuse, and keep the real continuous load under about 24 A.** The holder is rated 30 A,
> so at a full 30 A it is at 100 % of rating, and automotive practice de-rates a continuously loaded
> blade fuse to 70–80 % or it nuisance-blows. Any realistic sequence is well under this — the 30 A is
> the supply's ceiling, not its working current — but a rig that genuinely draws 30 A all evening wants
> the bolt-down MIDI that rev B used.

Worth recording why this part and not something better: **JLCPCB has nothing better.** The only other
"30 A" PCB fuse holder in their library, C142933 (Littelfuse MINI FL1), is rated **22 A continuous**
despite accepting 30 A fuses, and the proper 30 A ATO holder (C207060, Littelfuse 178.6165.0001) is out
of stock. Most boards in this class do not fuse 30 A on-board at all — they split into 5–10 A branches,
which is exactly what the twelve MF-R600s do.

### F1–F12 — output fuses

Bourns **MF-R600** PPTC, LCSC C208490, from the MF-R series datasheet:

| I<sub>hold</sub> | I<sub>trip</sub> | V<sub>max</sub> | I<sub>max</sub> | R<sub>min</sub> | R<sub>1max</sub> | 1 h post-trip max | max time to trip | tripped P |
|---|---|---|---|---|---|---|---|---|
| 6.00 A | 12.00 A | 30 V | 40 A | 0.005 Ω | 0.020 Ω | 0.040 Ω | 16.0 s at 30 A | 3.50 W |

Sized for the **18 AWG** core of a three-core Ray Wu pigtail. Three things about this choice:

- **Hold current derates hard with ambient** (I<sub>hold</sub> / I<sub>trip</sub>): 6.00 / 12.00 A at
  23 °C, 4.98 / 9.96 at 40 °C, 4.62 / 9.24 at 50 °C, **4.08 / 8.16 at 60 °C**, 3.66 / 7.32 at 70 °C.
  This is the single best reason the board now measures its own temperature.
- **Resistance is a range and it grows.** 0.005–0.020 Ω initially, up to **0.040 Ω** an hour after a
  trip, which is 0.24 V at 6 A and shows as dimming at the far end of that line.
- **PPTCs are slow.** 16 seconds at 30 A. They protect the wiring, not the pixels.

Mechanically the MF-R600 is 19.3 mm wide (A max) on 10.2 mm leads. Terminal columns are 20 mm apart, so
**two neighbouring fuses at maximum body width leave about 0.7 mm between them.** They fit; they are not
loose.

### Trip indicators (new)

A **KT-0805R red LED and a 4.7 k** across each polyfuse. In normal operation the fuse drops a few tens
of millivolts and the LED is dark. When it trips, the load drags the downstream side away from the bus,
about 12 V appears across the fuse, and the LED lights at **2.1 mA**. That current is far too small to
hold the fuse open or to power anything downstream. With the output unplugged there is no current, no
drop and no light — correct, because nothing is wrong.

Read back from the board: every `LF{n}` anode is on `+12V`, its cathode on `/LT{n}`, and `RF{n}` runs
`/LT{n}` → `/V{n}`, for all twelve.

## Thermal: fan thermostat and over-temperature alarm (new)

No MCU. An NTC divider feeds both halves of one comparator.

- **RT5**, Vishay NTCS0805E3103FHT (C3195213): 10 kΩ at 25 °C, B25/85 = 3940 K, ±1 %, −40…+150 °C. It
  sits between the FET bank and the main fuse — the hot corner.
- **U6**, TI LM2903QDRQ1 (C475499), SOIC-8, **AEC-Q100 grade 1, −40…+125 °C**. This matters: the
  ordinary LM393 parts JLCPCB stocks are 0…70 °C commercial, and a box that can reach 70 °C is the wrong
  place for a comparator that stops being specified there.

With a 10 k top resistor the divider node falls as the board heats: **1.60 V at 43 °C**, **0.88 V at
65 °C**.

| Half | Reference | Trips at | Drives |
|---|---|---|---|
| A (pins 1–3) | 10 k / 4.7 k loaded by the 100 k hysteresis leg | **on 44.2 °C, off 40.9 °C** (3.2 °C) | `/FANDRV` → Q5 gate |
| B (pins 5–7) | 4.7 k / 1 k = 0.877 V | **64.6 °C**, no hysteresis | **OVER TEMP** LED |

The fan numbers are *not* the 1.60 V the unloaded divider would give: R32, the hysteresis resistor, sits
on the reference node and pulls it to **1.552 V** with the output low and **1.693 V** with it released.
So TP8 crosses 1.55 V on the way up, not 1.60 V, and the hysteresis is 3.2 °C rather than the 2.4 °C an
earlier draft claimed.

Half A is wired reference-to-IN+ and NTC-to-IN− so its open-drain output releases when hot, and the
4.7 k pull-up then takes the gate high. Half B is the other way round, so its output pulls low when hot
and sinks the LED.

**U6 runs from +12 V, not the 5 V rail.** Its outputs are open-drain, so R33 and R36 still pull up to
+5 V and drive the gate and the LED at 5 V — only the supply pin moved. The reason is the input
common-mode range: at V_CC = 5 V the ceiling is V_CC − 1.5 V (25 °C) or V_CC − 2 V over temperature,
and the NTC node climbs to 3.85 V at 0 °C and 4.88 V at −40 °C. TI SLCS141M's footnote does permit
this — *"the upper end of the input voltage range is V_CC − 1.5 V for one input, and the other input can
exceed the V_CC level; the comparator provides a proper output state"* — and our reference input sits at
1.55 V, comfortably in range. So it was never a defect. But an outdoor board would have spent much of
every year relying on a footnote whose wording differs between datasheet revisions. At V_CC = 12 V the
input window is 0–10 V and the question does not arise, for about 1 mA.

Two honest limitations:

- **R37 (100 k) does not hold the fan off if U6 is unpopulated.** R33 (4.7 k) is pulling the same node
  up to +5 V, so the divider sits at **4.78 V** and Q5 is hard on. An earlier draft of this file claimed
  the opposite. In practice this fails in the safe direction — no comparator means the fan simply runs —
  but do not rely on R37 for anything. It only pulls the released output from 5.00 V down to 4.64 V.
- **Half B has no hysteresis**, so the OVER TEMP LED will hover for a few seconds as the board crawls
  through 65 °C. This is not easily fixable: hysteresis needs positive feedback to the *non-inverting*
  input, and half B's non-inverting input is the NTC node itself, which is shared with half A. Feeding
  the output back there would drag half A's threshold around too. A flickering alarm LED is the cheaper
  outcome.

> **An open NTC fails silently and unsafely.** RT5 is the bottom leg, so if it goes open — cracked
> chip, bad joint, cut trace — R29 pulls the node to +5 V, which both halves read as "very cold". The
> fan stays off and the alarm stays dark. A *short* fails safe and visible (fan on, alarm on). The
> divider cannot be turned round to fix this: with the NTC on top, open reads as 0 V, which the
> reversed comparator sense would also read as "cold". **If TP8 reads 5.0 V, the NTC is open — it does
> not mean the board is cold.** A board that has never once run its fan is the symptom.

## Fan output (new)

**The fan belongs on the enclosure wall, not on the board.** What matters is air moving across the two
fuse rows, which sit at the board edges; a board-mounted fan blows down on one spot. So this is an
output, not a mount.

J16 is a KF301-5.0-3P on the left edge marked **+ − G**. Feed: `+12V` → **F13**, a Fuzetec
FSMD035-30-1206R PPTC (0.35 A hold / 30 V) → `/FAN12` → J16 pole 1. Return: J16 pole 2 → `/FANM` →
**Q5** (AO3400A, 30 V 5.7 A) to ground, with **D8** (SS34) as flyback. Pole 3 is a spare ground.

> **Keep the fan under about 200 mA** — a 40 or 60 mm fan, not an 80 mm. That is the polyfuse, which
> derates with ambient like any other.
>
> And the obvious caveat: venting an outdoor enclosure invites water and insects. A metal backplate or a
> bigger box is the cheaper first move; the fan is the fallback.

Total board dissipation at a sustained full 30 A is **~8–10 W** (polyfuses 1.5 W, FETs 1.6 W, `/GNDIN`
copper 1.5 W, other copper 0.9 W, main fuse ~2–3 W, regulator 0.35 W). A typical sequence at 15–20 %
average is nearer 3 W.

## I²C temperature sensors (new)

Two **NXP LM75BD** (C34565), ±2 °C, SOIC-8:

| Sensor | Address | Placed at | Nearest heat source |
|---|---|---|---|
| U4 | 0x48 (A2/A1/A0 all low) | (68, 26) | top fuse row, 12.2 mm; FET bank, 30 mm; F0, 25.8 mm |
| U5 | 0x49 (A0 high) | (7, 24) | F1's pad, 9.5 mm |

> **Known limitation — these are not a "hot spot vs ambient" pair, whatever you might want them to be.**
> U4 ended up 26–30 mm from both the FET bank and the main fuse, and U5, nominally the cool corner, is
> actually *closer* to a dissipating polyfuse than U4 is to anything. On top of that, both sit on the
> same two solid copper planes spanning the whole board, which makes it close to isothermal laterally.
> Expect a few degrees between them at most, against **±2 °C per sensor** — so up to ±4 °C on the
> difference. Read them as two board-temperature measurements, which is genuinely useful against the
> MF-R600 derating table, and do not read much into the difference. A real hot-spot sensor would need
> U4 within ~5 mm of F0's pads, which is a v1.01 change.

The sensor that actually matters for control is **RT5**, the NTC, at (82, 30) — 11.3 mm from F0's pad
and the closest thing on the board to the power section.

**They run from VIO on the header, not from the board's 5 V rail.** Whatever you plug in — a 3.3 V ESP32
or a 5 V Pi — supplies VIO, so the sensors and the bus sit at the master's own logic level and **no level
shifter is ever needed**. With nothing plugged in they are simply unpowered, which costs nothing because
there is no master on the board to read them. The fan and the alarm LED do not depend on them at all.

J15 is marked `I2C  G VIO SDA SCL   VIO=IN`. Read-back confirms no +5 V reaches either sensor.

## Signal path (read back from the board, not from the generator)

| Port | RJ45 pins | U1 inputs | U1 output | series R | terminal |
|---|---|---|---|---|---|
| P1 | 1 (+), 2 (−) | 6 = 1A/P1P, 7 = 1B/P1N | 5 → RXD1 | RS1 | J2 pole 2 |
| P2 | 3 (+), 6 (−) | 10 = 3A/P2P, 9 = 3B/P2N | 11 → RXD2 | RS2 | J5 pole 2 |
| P3 | 5 (+), 4 (−) | 14 = 4A/P3P, 15 = 4B/P3N | 13 → RXD3 | RS3 | J8 pole 2 |
| P4 | 7 (+), 8 (−) | 2 = 1A/P4P, 1 = 1B/P4N | 3 → RXD4 | RS4 | J11 pole 2 |

The Falcon standard (port 3 = 5+/4−). Identical to difftx except port 3, which difftx rev D has reversed (see
"Port 3 polarity fix" above). U1 pin 4 (G) = +5 V, pin 12 (Ḡ) = GND — permanently enabled.
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

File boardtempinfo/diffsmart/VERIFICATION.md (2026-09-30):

# Chandler 4D/8P Smart Receiver v1.00 (diffsmart) — verification record

**diffsmart** is the dual-mode member of the family. It is the whole of `../diffrx/archive/revC_release` — one
cat5 in, four WS2811 data outputs, eight power-injection outputs, a 12 V 30 A fused distribution bus,
an NTC fan thermostat and two I²C temperature sensors — **plus the brains of `../difftx`**: a 40-pin
Raspberry Pi header, a 2 A supply for the Pi and an EEPROM on its I²C bus.

The Pi connects by **40-way ribbon** and lives in the enclosure, not on the board, so **any 40-pin
Raspberry Pi works** — Zero 2 W, 3A+, 3B+, 4 — the same set `../difftx` accepts.

One slide switch decides which of the two drives the four pixel outputs:

| Switch | `/MODE` | AM26C32 `G` | 74HCT125 `~OE` | The board is |
|---|---|---|---|---|
| **RX** | HIGH | enabled | Hi-Z | a differential receiver — the cat5 link drives the outputs |
| **PI** | LOW | Hi-Z | enabled | a standalone smart controller — the Pi on J17 drives them |

Generated from `gen_sch.py` and `gen_pcb.py` exactly as the other two boards; `verify.py` reads the
finished board back, `silkcheck.py` sweeps the silkscreen, `export_jlc.py` writes `jlcpcb/`.

## Port 3 polarity fix (2026-09-29)

**J14 port 3 is now pin 5 (+) / pin 4 (−), the Falcon standard.** Before this fix, the board had 4 (+) / 5 (−), copied from difftx
rev D. On 2026-09-29, a PixelController SRx1 v5.01 fed by difftx rev D showed that assignment was reversed: port 3 sparkled
white and ignored data, and a cable with pins 4 and 5 swapped at one end fixed it. (Source for the pinout: Dan Kulp,
"blue (5, 4) is for port 3", https://falconchristmas.com/forum/index.php?topic=15638.0. See also the repo `CLAUDE.md`.)

- Schematic: the J14 pin 4 and 5 labels are swapped (pin 4 = P3N, pin 5 = P3P), and the notes are updated.
- Board (`patch_port3.py`, mirrored in `gen_pcb.py`): P3P drops through a new via at (13.0, 50.51) and runs on B.Cu
  between pads 4 and 6 to pad 5 (0.2 mm track, 0.22 mm to each pad). P3N takes an F.Cu hop from (12.0, 49.49) to pad 4.
  The silkscreen now reads `P3=5/4`.
- Checks: ERC 0; DRC with `--schematic-parity --refill-zones` gives 0 violations, 0 unconnected and 0 parity issues.
  All-severity results are unchanged apart from the expected `lib_footprint_mismatch` warnings. `jlcpcb/` has been re-exported.
- **Compatibility:** this board now matches Falcon transmitters. Paired with a **difftx rev D**, port 3 is inverted, so use a
  lead with pins 4 and 5 swapped at one end (the same lead that makes rev D work with Falcon receivers).
- A backup of the board before this fix is in `../_backups/`.

## Automated checks (KiCad 10.0.6, 2026-09-20)

| Check | Result |
|---|---|
| `kicad-cli sch erc` | **0 violations** |
| `kicad-cli pcb drc --schematic-parity` | **0 unconnected, 0 schematic parity issues** |
| router | **0 routing failures** |
| `verify.py` read-back | mode logic, both data sources, Pi interface and supply widths all as designed |
| `silkcheck.py` (silk vs silk / pads / edge) | **0 / 0 / 0** |
| 3D renders | inspected |

Remaining DRC output is 83 `lib_footprint_mismatch` (expected — this board strips footprint silkscreen
outlines, see `gen_pcb.py`) and 7 `track_dangling`, discussed under *Known issues*.

`verify.py` also now reports the Pi's real geometry, solved out of the socket's pad positions rather
than taken from the generator's intent — see *The Pi*. That check exists because the first build of this
board had the socket mirrored and every other check passed.

## Why one switch is enough

This was the piece of luck that kept the design cheap. TI's AM26C32 function table (SLLS104M Table 7-1)
puts the outputs in high-impedance **only when `G` = L AND `~G` = H**. Tie `~G` permanently high and the
enable collapses to `G` alone — and the 74HCT125's `~OE` wants the *same* polarity:

```
/MODE = H  ->  G = H : receiver drives      ~OE = H : buffer in Hi-Z
/MODE = L  ->  G = L : receiver in Hi-Z     ~OE = L : buffer drives
```

So a plain SPDT slide switch does it, with no inverter and no second pole. Each source keeps **its own
470 Ω** into the shared node (RS1–4 for the receiver, RS5–8 for the Pi), so even if both were somehow
enabled the contention is about 10 mA rather than a short.

`R45` (10 k to +5 V) defaults the board to **receiver** mode if the switch is ever open mid-travel.

Read back from the board: `SW1.2`, `U1.4` and all four of `U9`'s `~OE` pins are on `/MODE`; `U1.12` is
on `+5V`.

## The Pi

**The Pi is not on this board.** J17 is a **2×20 male header** and a 40-way ribbon runs to a Pi mounted
in the enclosure. That is what makes this board work with **every model difftx supports** — Zero 2 W,
3A+, 3B+, 4 — rather than only the one that is hard to buy.

The earlier design had a Zero 2 WH plugged upside down into a socket here. It could never have grown
past that one model:

| Pi | Size | Footprint on the board, measured from the socket |
|---|---|---|
| Zero 2 W | 65 × 30 | x 129.3–159.3, y 65–130 — fits exactly, and only exactly |
| 3A+ | 65 × 56 | x 129.3–**185.3** — 25 mm off the east edge |
| 3B+ / 4 | 85 × 56 | that, **and** y 65–**150**, 20 mm off the south edge |

There is no 65 × 56 clear area on a 160 × 130 board carrying twelve screw terminals, let alone 85 × 56.
A bigger Pi would hang unsupported off two edges with its mounting holes in mid-air, over the bottom
terminal row.

**The numbering un-swapped, and that is the safety-critical part.** The socket's odd/even pads were
deliberately mirrored, because a Pi presented upside down shows the board its solder side. A ribbon is a
straight 1:1 pin map, so that same mirror would now deliver pin 1 to pin 2 — **5 V into the Pi's 3.3 V
rail**, which is precisely the fault the swap was introduced to fix, reappearing from the other
direction. `verify.py` asserts the handedness with the sign flipped, and then checks all eighteen
connected pins against the published Raspberry Pi header:

```
  1->2 (2.54, 0.0) (2.54 across)   1->3 (0.0, 2.54) (2.54 along)   handedness +6.45
  OK - straight through, so a standard ribbon lands pin n on pin n
  22 pins left open, 18 connected
```

**What goes with the Pi:** the notch in the east edge, both M2.5 standoff holes, the Pi outline on the
silk, and the whole class of mechanical risk that came with a computer hanging 11 mm over the copper —
antenna clearance, microSD ejection, the buck module's height, what is underneath it. The outline is a
plain 160 × 130 rectangle again, so the fab no longer routs an internal slot. It also routes more
easily: un-mirrored puts every signal pin on the **outer** column with open board beside it, which is
the arrangement that never had a dead end.

**The one thing a ribbon can get wrong is orientation.** A plain 2×20 male header has no key, so an IDC
socket will seat either way round, and reversed it hands 5 V to GPIO2. The board carries a filled
triangle and a `1` drawn from pad 1's own position, a box around the field, and `PIN 1 AT TOP /
REVERSED PUTS 5V ON GPIO2` beside it. **The same forty holes take a shrouded DC3-40P box header**, which
is keyed — the silk box is its shroud outline, so there is clearance if you would rather have the key.

**The GPIO map is unchanged**, so an existing FPP configuration needs no edit:

| Pi pin | GPIO | net | buffer | output |
|---|---|---|---|---|
| 7 | 4 | `/DPI_D0` | U9 4A → 4Y | DATA4 |
| 29 | 5 | `/DPI_D1` | U9 1A → 1Y | DATA1 |
| 31 | 6 | `/DPI_D2` | U9 2A → 2Y | DATA2 |
| 26 | 7 | `/DPI_D3` | U9 3A → 3Y | DATA3 |

These four are **DPI_D0–D3**, four consecutive bits of the Broadcom parallel display bus, which is what
FPP's DPIPixels output clocks a framebuffer out of. That is why it is these pins and not any others, and
it is also why an Orange Pi Zero 2W cannot substitute: its header is pin-compatible, but those four pins
land on PI13, PH9, PI0 and PI15 — four unrelated GPIOs in two different Allwinner port banks.

**R41–R44 are 2 k, not 10 k.** They hold all four DPI lines low, so an unpopulated header leaves the
outputs at the WS2811 idle state. The case that actually sets the value is a *populated, booting* Pi:
GPIO4–7 are four of the nine BCM pins that come out of reset with the **internal pull-up enabled**, and
it stays enabled for the whole boot and again through shutdown. Against 10 k that divider sits at 0.55 V
typical and **0.77 V** if the Pi's pull-up is at the low end of the published spread — against a
74HCT125 V_IL of **0.8 V flat over the whole temperature range**. Thirty millivolts, with all four
inputs parked near threshold drawing crowbar current. 2 k gives 0.19 V worst case.

**U9 is a 74HCT125**, not an HC part: HCT inputs read 3.3 V logic reliably from a 5 V rail, and the
outputs swing to 5 V for the pixels.

## Power

**Two 5 V rails, deliberately.**

- **U7, a K7805-2000R3** (12 V → 5 V, 2 A) feeds *only* the Pi, and only through **JP1**. A Zero 2 W
  peaks near 1.4 A at 5 V, which the existing UA78M05 in a SOT-223 cannot do.
- **JP1 is the 5 V link, and it exists because 2 A is not enough for every Pi.** Raspberry Pi ask for
  2.5 A on a 3A+/3B+ and 3 A on a Pi 4. Fit the shunt and the board powers the Pi off the 12 V bus as
  before — a Zero 2 W or a 3A+. Pull it for anything larger and the Pi runs from its own supply, with
  the two 5 V rails never meeting and nothing to back-feed. Ground and all four data lines are
  unaffected either way, and the Pi's own 3V3 still arrives on pin 1 to run the sensors, so *only* the
  supply is broken. **Never fit the link and plug a supply into the Pi at the same time.**
- **F14, a 1.5 A PPTC, is on the 12 V side of U7, not the 5 V side.** At the Pi's peak that node carries
  only 0.67 A, so F14 is not sized for the Pi — it is sized to open on a shorted module, which is the
  fault that would otherwise sit straight across the 30 A bus. (A 1.5 A PPTC on the *5 V* side would
  have been a nuisance-trip candidate: ~1.0 A hold at 60 °C against a 1.46 A peak.)
- **Two 10 µF/50 V input capacitors, C13 and C14, both beside U7 pin 1.** The K78xx-2000R3 datasheet
  calls for 22 µF at the input and says both capacitors must be as close as possible to the module's
  terminals; one 10 µF 7.6 mm away, behind the PPTC, was a third of that. 20 µF nominal is still 2 µF
  short of the figure — recorded here rather than papered over — but it is the same dielectric under the
  same DC bias, with an order of magnitude less loop area.
- **The linear UA78M05 stays** for the board's own logic. The RS-422 receiver resolves a ±200 mV
  differential against a threshold referenced to that rail, and it is not worth putting buck ripple
  underneath it for the sake of one part.

The two rails share ground and are never tied together.

**Track widths matter here and DRC caught it.** The router's default 0.25 mm of 1 oz copper carries
0.88 A at a 10 °C rise by IPC-2221 — not enough for a 1.2 A peak. The Pi supply nets are routed wide:

| net | width | IPC-2221 at 10 °C rise |
|---|---|---|
| `/PI5V` | 0.5 mm | 1.44 A |
| `/PI12` | 0.4 mm | 1.23 A |
| `/P3V3` | 0.3 mm | 0.98 A (load is a few mA) |

## The Pi can read the sensors

The Pi's own I²C (pins 3 and 5) joins the board's `/SDA` and `/SCL`, so **a fitted Pi reads both LM75
temperature sensors natively** — no external master, no extra wiring. The HAT EEPROM (U8, AT24C256C)
sits on the same bus at **0x50**, clear of the sensors at **0x48** and **0x49**.

**D9 is gone and `/VIO` is now just `/P3V3`.** D9 was a Schottky from the Pi's 3V3 to the sensor rail,
there to stop the J15 header back-feeding the Pi. It could not do that: the Pi carries **physical 1.8 kΩ
pull-ups from GPIO2 and GPIO3 to its own 3V3 rail**, and `/SDA` and `/SCL` go straight to those pins —
about 3.25 kΩ in parallel with the diode, which is the classic partial-power-through-a-GPIO condition.
Meanwhile it cost real headroom: at −20 °C, with the Pi's 3V3 3 % low, its forward drop put the sensor
rail at **2.78 V against the LM75B's 2.80 V floor**. On an outdoor Christmas-light controller that is an
ordinary December night, and the LM75B is rated to −55 °C, so it would be alive and out of spec rather
than simply off.

> **J15's supply pin is 3.3 V now, and the silkscreen says `3.3V ONLY - NOT 5V`.** On the receiver-only
> board this pin took 2.8–5.5 V and the master set the bus level. That is not available here, because
> SDA and SCL are hard-wired to GPIO2 and GPIO3, which are **not 5 V tolerant** — the old legend, with a
> Pi fitted, invited someone to destroy two GPIOs. This is a deliberate loss of a rev C feature.

**U8 is a user EEPROM, not a HAT ID EEPROM.** It sits at 0x50 on **GPIO2/GPIO3 (pins 3 and 5, i2c-1)**.
The Pi's firmware reads the HAT ID EEPROM **only** on ID_SD/ID_SC, pins 27 and 28, which this socket
leaves unconnected. So there is no device-tree overlay, no automatic GPIO configuration and no HAT
detection of any kind — read it with `i2cdump -y 1 0x50`. WP is tied low so it can be flashed in place
with difftx's `make_eeprom.py`. It runs from the Pi's own 3V3, so with no Pi it is absent from the bus.
(difftx carries the same mislabelling and has not been changed.)

## What moved, and what did not

The board grew from 130 × 100 to **160 × 130 mm**. All four edges of the receiver were already
committed — terminals top and bottom, RJ45 and fan left, 12 V input right — so the Pi could not simply
be dropped in; it needed an edge of its own.

- Everything in the original 130 × 100 keeps its **x** position.
- The **bottom block** (terminals, fuses, trip LEDs, zip-tie holes, labelling) moved down 30 mm.
- **J1 moved 30 mm right and 4 mm up** onto the new edge. Right, to make room for the Pi column; up,
  to clear the Pi's microSD card, which ejects northward across y = 65 at x 136.4–148.4 and wanted the
  same space as the terminal's body. Clearance is now 1.61 mm. Because J1's negative pad then sits
  north of the `/GNDIN` island, that island is an **L** rather than a rectangle — it reaches up to
  y = 52 in its eastern 18 mm only, which keeps it clear of the `/VG` gate bus crossing F.Cu at y = 55.
  The islands are longer but not narrower, so their temperature rise is unchanged; the extra drop is
  about 20 mV at 30 A.
- The band the bottom block vacated (y 76–104) now holds the Pi's support circuitry. It had to go
  there: the two supply islands are keepouts on **both** outer layers across y 30–66, so anything in
  the Pi column below them cannot reach anything above without a trip round the west side.
- The **east edge is a plain rectangle again** and H4 is back to an M3 corner: the notch and the two
  M2.5 standoff holes existed only for a Pi sitting over the board.
- The activity LEDs **moved onto the shared output nodes** (through 2 k) so they indicate in *both*
  modes rather than only in receiver mode. 2 k, not the 4.7 k first fitted: the LED is a KT-0805G at
  2.6 V minimum, not the 2.4 V an earlier note assumed, so 4.7 k in series with the port's own 470 Ω
  gave **0.46 mA** — a tenth of the test current, and only while data is high, which on a WS2811 frame
  is about a fifth of the time. Invisible outdoors. 2 k gives 0.97 mA for 0.46 V of output swing,
  leaving ~4.5 V at the terminal against a WS2812B threshold of 3.5 V.
- **U5**, the second temperature sensor, moved to (20, 100). It was jammed against the left board edge
  with three nets trying to leave the same two columns. This also partly answers the rev C review's
  point that it was not actually in a cool spot — though see *Known issues*.
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

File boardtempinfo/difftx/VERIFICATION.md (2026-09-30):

# Rev E verification record — FPP Remote pHAT on the Pi Zero 2 W outline (rev D + port 3 polarity fix)

Rev D is rev C shrunk onto the Raspberry Pi Zero 2 W footprint: 65 x 30 mm, R3 corners, the four M2.5 holes on the
Pi's own 58 x 23 mm pattern, so the board stacks exactly over the Pi. The 66 x 66 mm rev C is archived in `archive/revC_66mm/`.

Generated files: `difftx.kicad_sch` / `difftx.kicad_pcb` (from `gen_sch.py` and `gen_pcb.py`), `jlcpcb/` (gerber
zip, BOM, CPL from `export_jlc.py`), `eeprom/difftx-eeprom.bin` (from `make_eeprom.py`), renders `render_*.png`.

## Rev E (2026-09-29): port 3 polarity
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

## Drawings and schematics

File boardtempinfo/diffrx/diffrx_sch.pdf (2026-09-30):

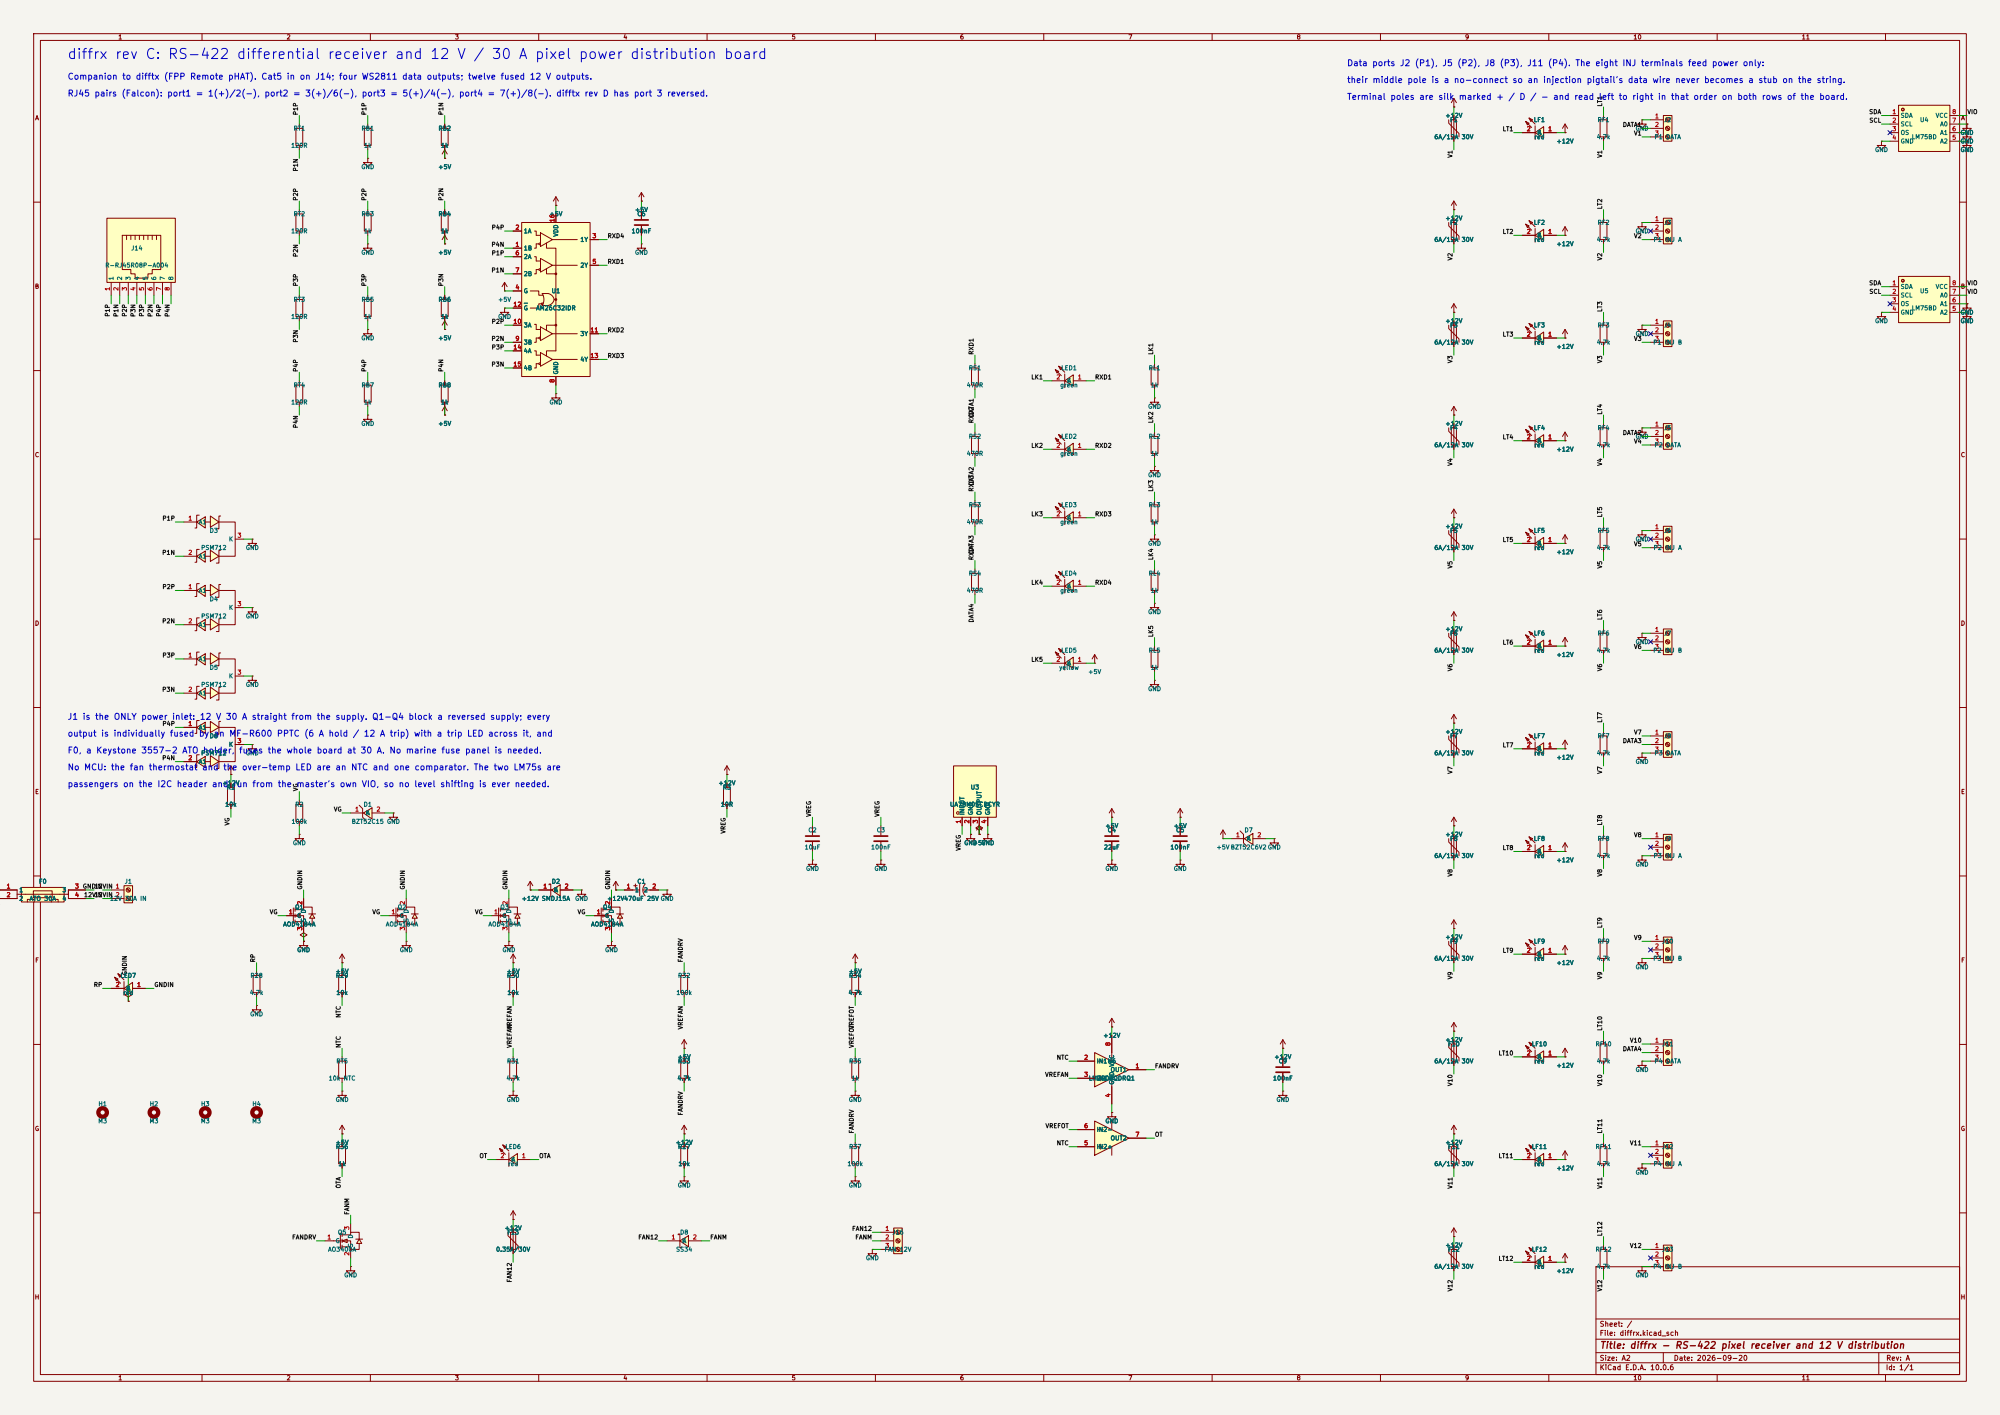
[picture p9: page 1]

diffrx rev C: RS-422 differential receiver and 12 V / 30 A pixel power distribution board

Data ports J2 (P1), J5 (P2), J8 (P3), J11 (P4). The eight INJ terminals feed power only:

Companion to difftx (FPP Remote pHAT). Cat5 in on J14; four WS2811 data outputs; twelve fused 12 V outputs.
RJ45 pairs (Falcon): port1 = 1(+)/2(-), port2 = 3(+)/6(-), port3 = 5(+)/4(-), port4 = 7(+)/8(-). difftx rev D has port 3 reversed.

their middle pole is a no-connect so an injection pigtail's data wire never becomes a stub on the string.
Terminal poles are silk marked + / D / - and read left to right in that order on both rows of the board.

J1 is the ONLY power inlet: 12 V 30 A straight from the supply. Q1-Q4 block a reversed supply; every
output is individually fused by an MF-R600 PPTC (6 A hold / 12 A trip) with a trip LED across it, and

passengers on the I2C header and run from the master's own VIO, so no level shifting is ever needed.

Sheet: /
File: diffrx.kicad_sch
Title: diffrx - RS-422 pixel receiver and 12 V distribution

Size: A2 | Rev: A
KiCad E.D.A. 10.0.6 | Id: 1/1

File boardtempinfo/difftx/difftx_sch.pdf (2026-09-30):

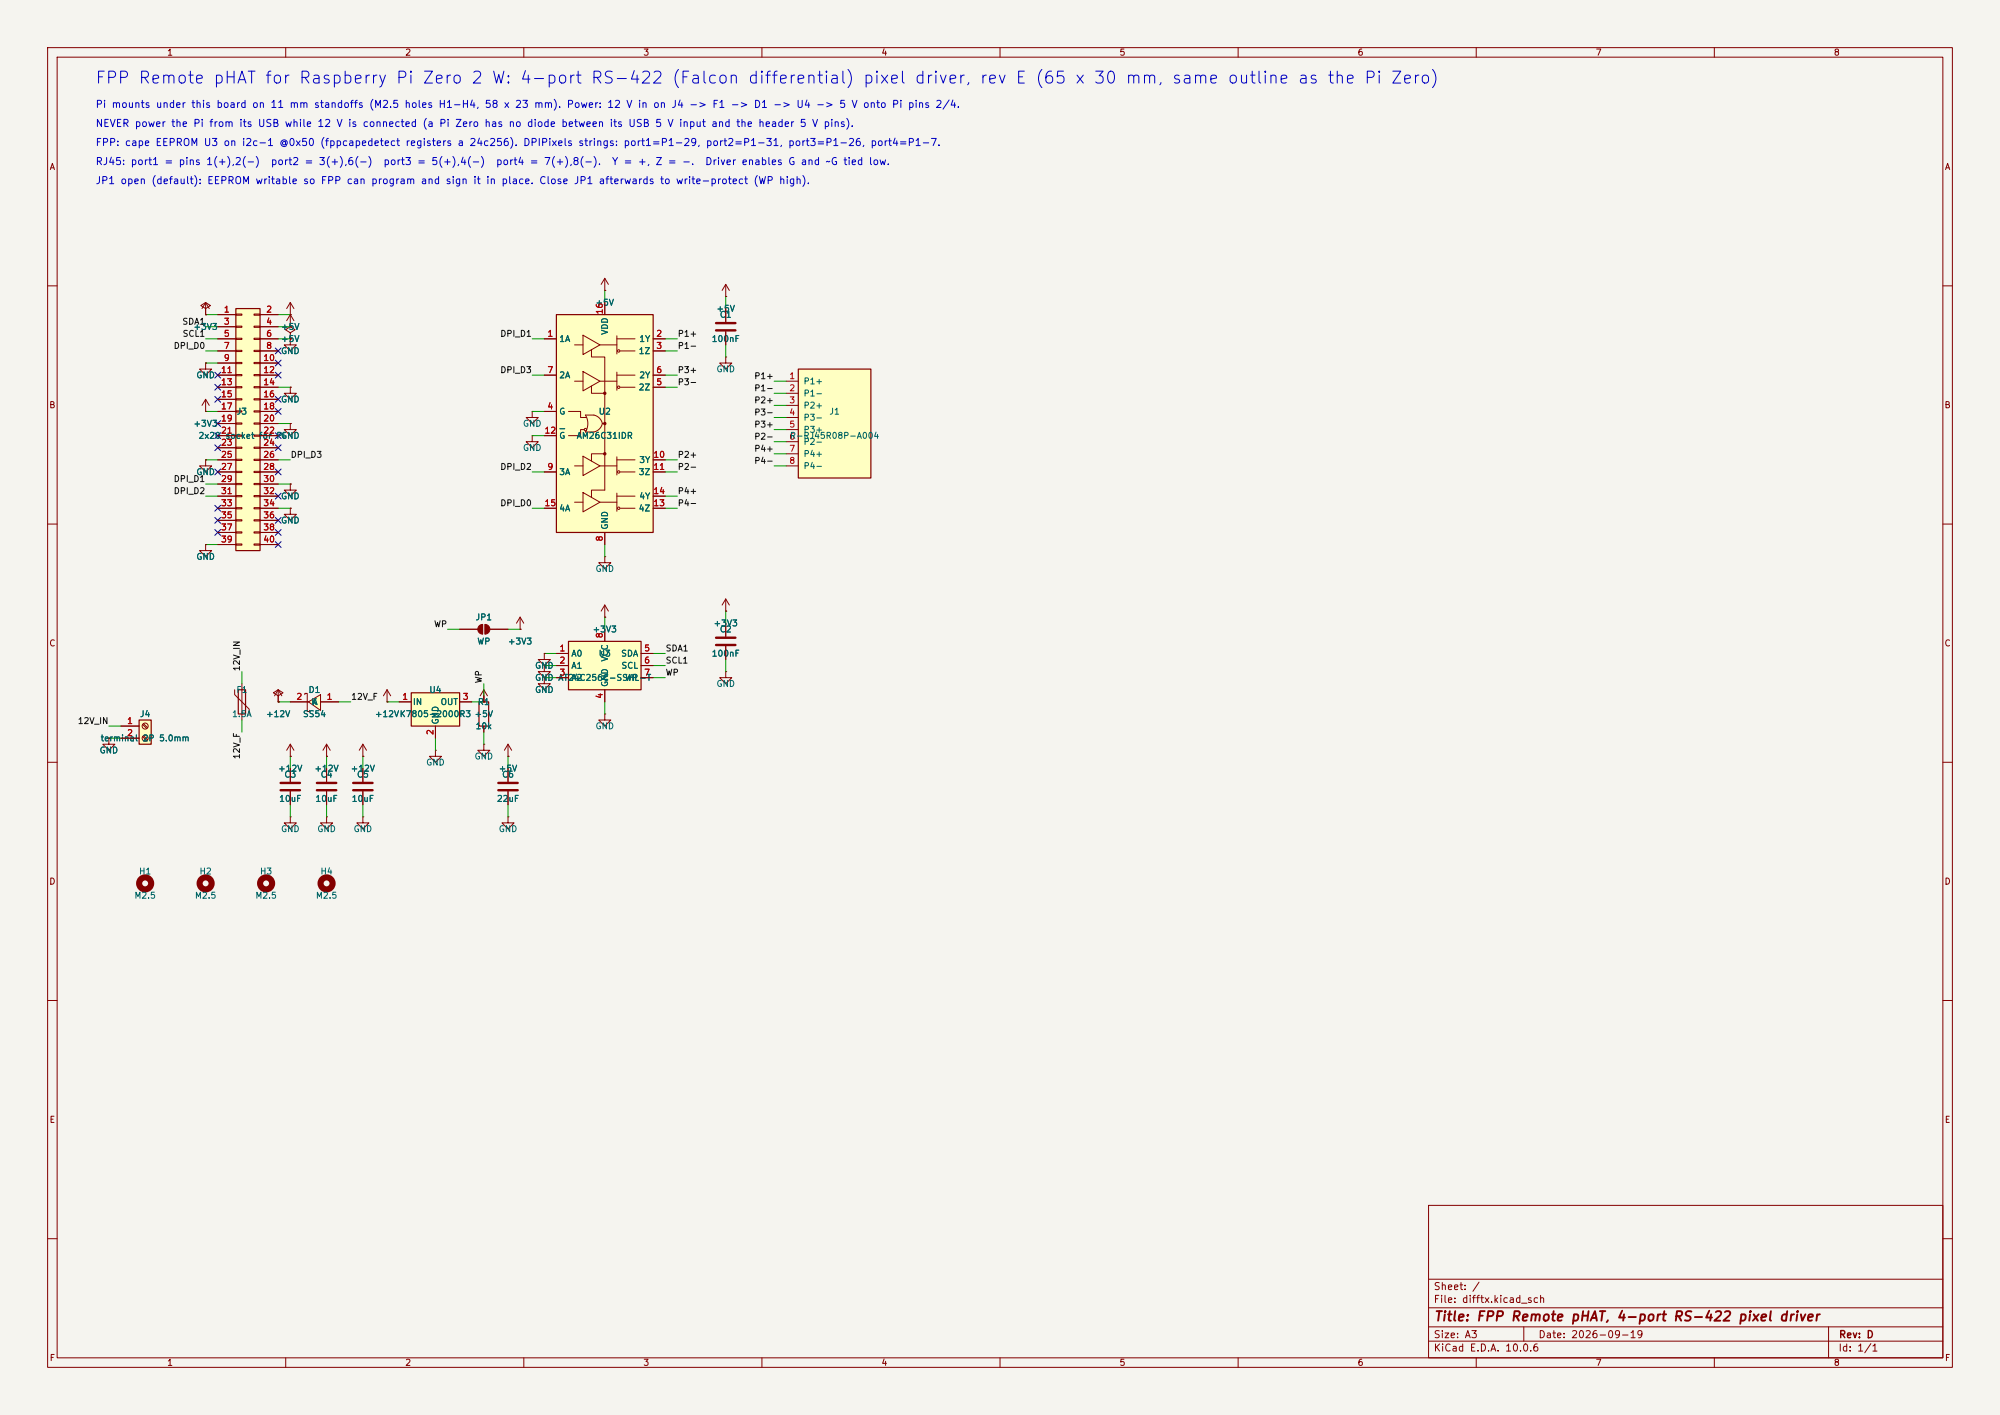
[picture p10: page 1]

FPP Remote pHAT for Raspberry Pi Zero 2 W: 4-port RS-422 (Falcon differential) pixel driver, rev E (65 x 30 mm, same outline as the Pi Zero)

Pi mounts under this board on 11 mm standoffs (M2.5 holes H1-H4, 58 x 23 mm). Power: 12 V in on J4 -> F1 -> D1 -> U4 -> 5 V onto Pi pins 2/4.
NEVER power the Pi from its USB while 12 V is connected (a Pi Zero has no diode between its USB 5 V input and the header 5 V pins).
RJ45: port1 = pins 1(+),2(-) port2 = 3(+),6(-) port3 = 5(+),4(-) port4 = 7(+),8(-). Y = +, Z = -. Driver enables G and ~G tied low.
JP1 open (default): EEPROM writable so FPP can program and sign it in place. Close JP1 afterwards to write-protect (WP high).

Sheet: /
File: difftx.kicad_sch
Title: FPP Remote pHAT, 4-port RS-422 pixel driver

Size: A3 | Rev: D | F Date: 2026-09-19
KiCad E.D.A. 10.0.6 | Id: 1/1

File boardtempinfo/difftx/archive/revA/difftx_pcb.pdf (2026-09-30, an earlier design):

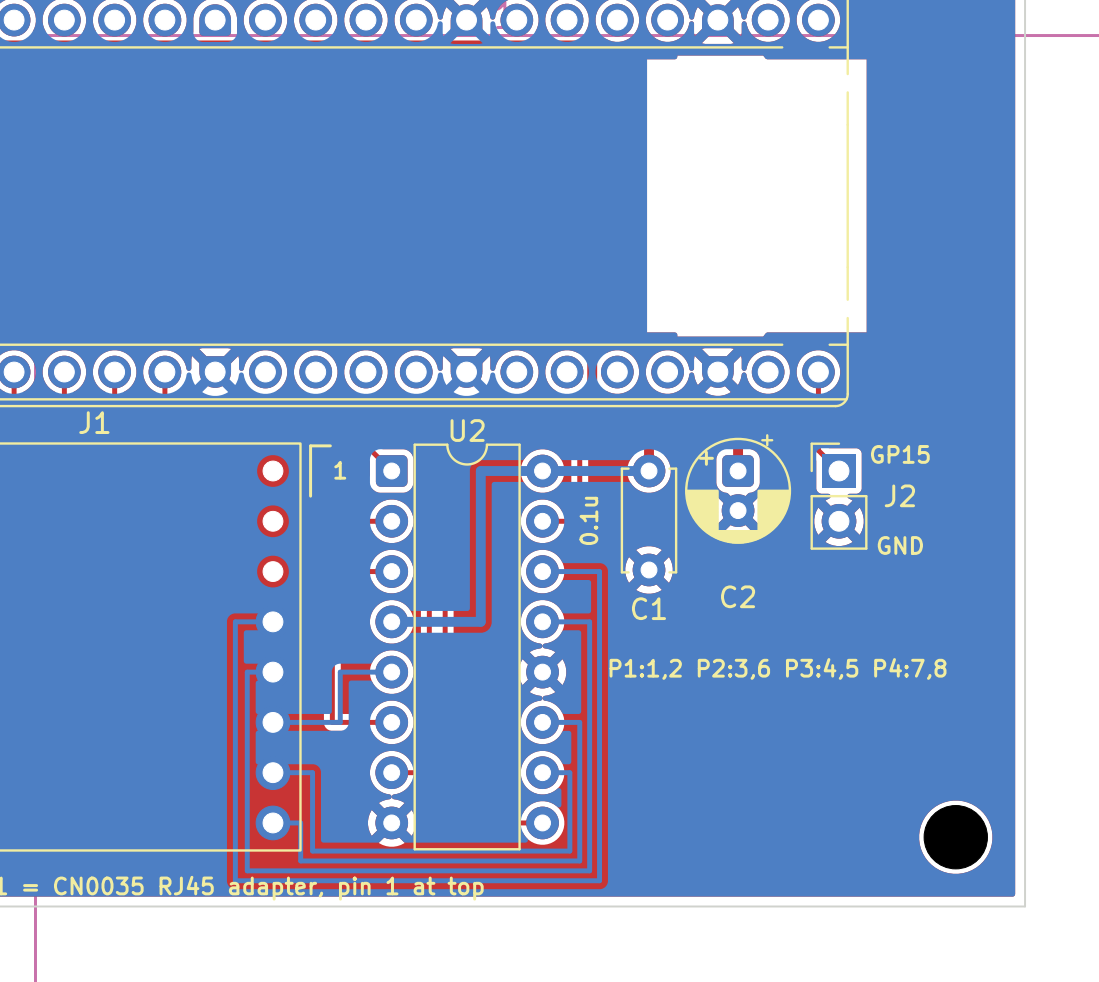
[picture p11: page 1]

Size: A4 | Rev:
KiCad E.D.A. 10.0.6 | Id: 1/1

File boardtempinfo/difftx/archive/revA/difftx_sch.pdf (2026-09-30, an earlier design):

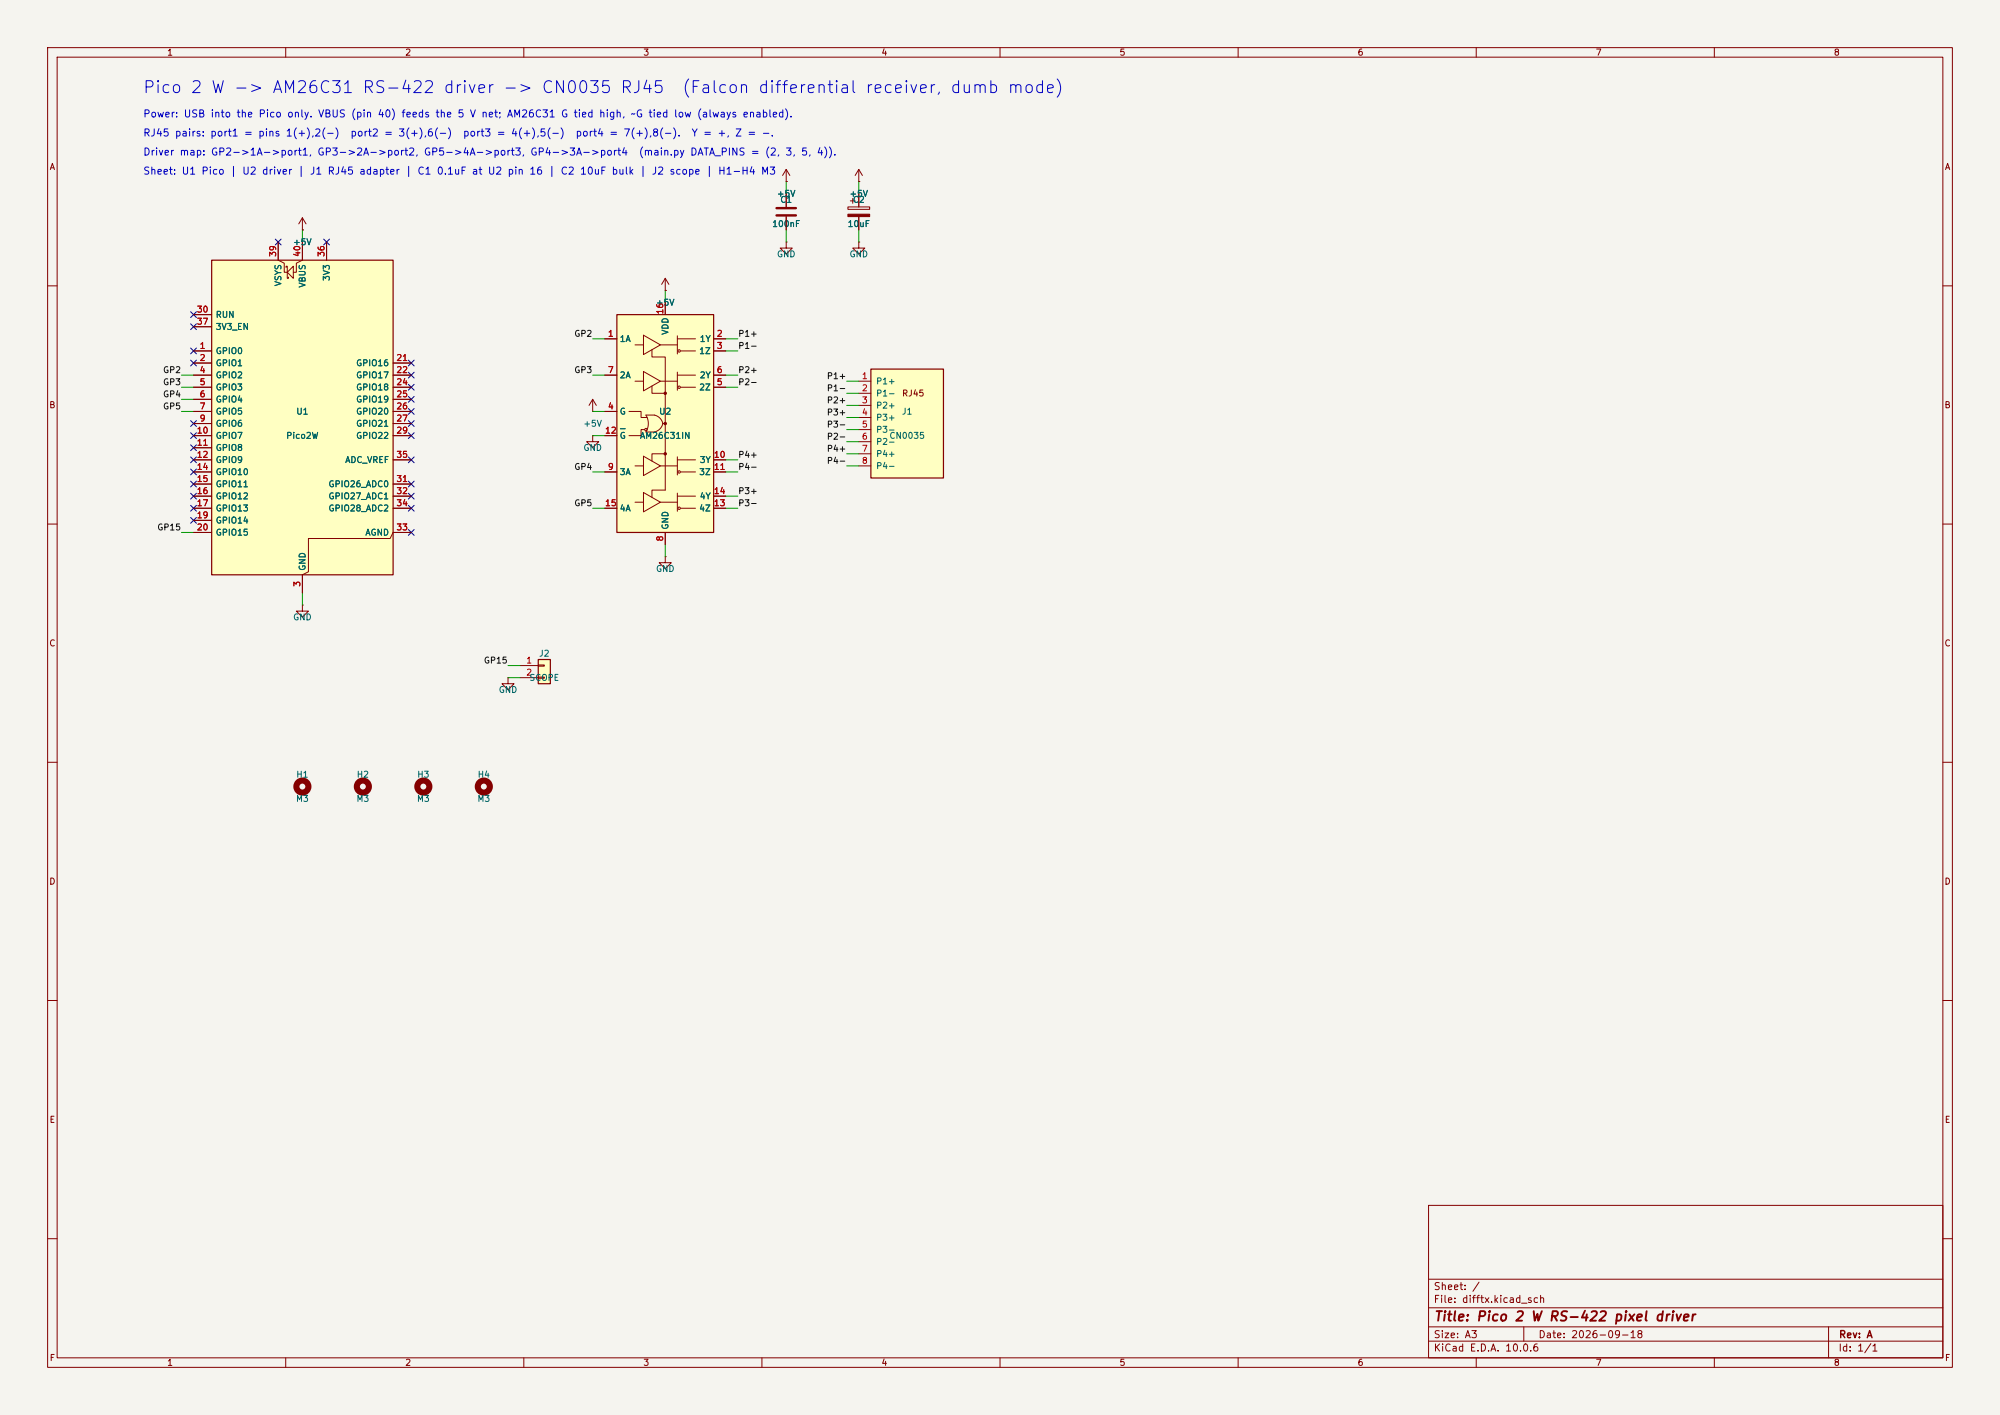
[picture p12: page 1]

Pico 2 W -> AM26C31 RS-422 driver -> CN0035 RJ45 (Falcon differential receiver, dumb mode)

Power: USB into the Pico only. VBUS (pin 40) feeds the 5 V net; AM26C31 G tied high, ~G tied low (always enabled).
RJ45 pairs: port1 = pins 1(+),2(-) port2 = 3(+),6(-) port3 = 4(+),5(-) port4 = 7(+),8(-). Y = +, Z = -. Driver map: GP2->1A->port1, GP3->2A->port2, GP5->4A->port3, GP4->3A->port4 (main.py DATA_PINS = (2, 3, 5, 4)).

Sheet: U1 Pico | U2 driver | J1 RJ45 adapter | C1 0.1uF at U2 pin 16 | C2 10uF bulk | J2 scope | H1-H4 M3

Sheet: /
File: difftx.kicad_sch
Title: Pico 2 W RS-422 pixel driver

Size: A3 | Rev: A | F Date: 2026-09-18
KiCad E.D.A. 10.0.6 | Id: 1/1

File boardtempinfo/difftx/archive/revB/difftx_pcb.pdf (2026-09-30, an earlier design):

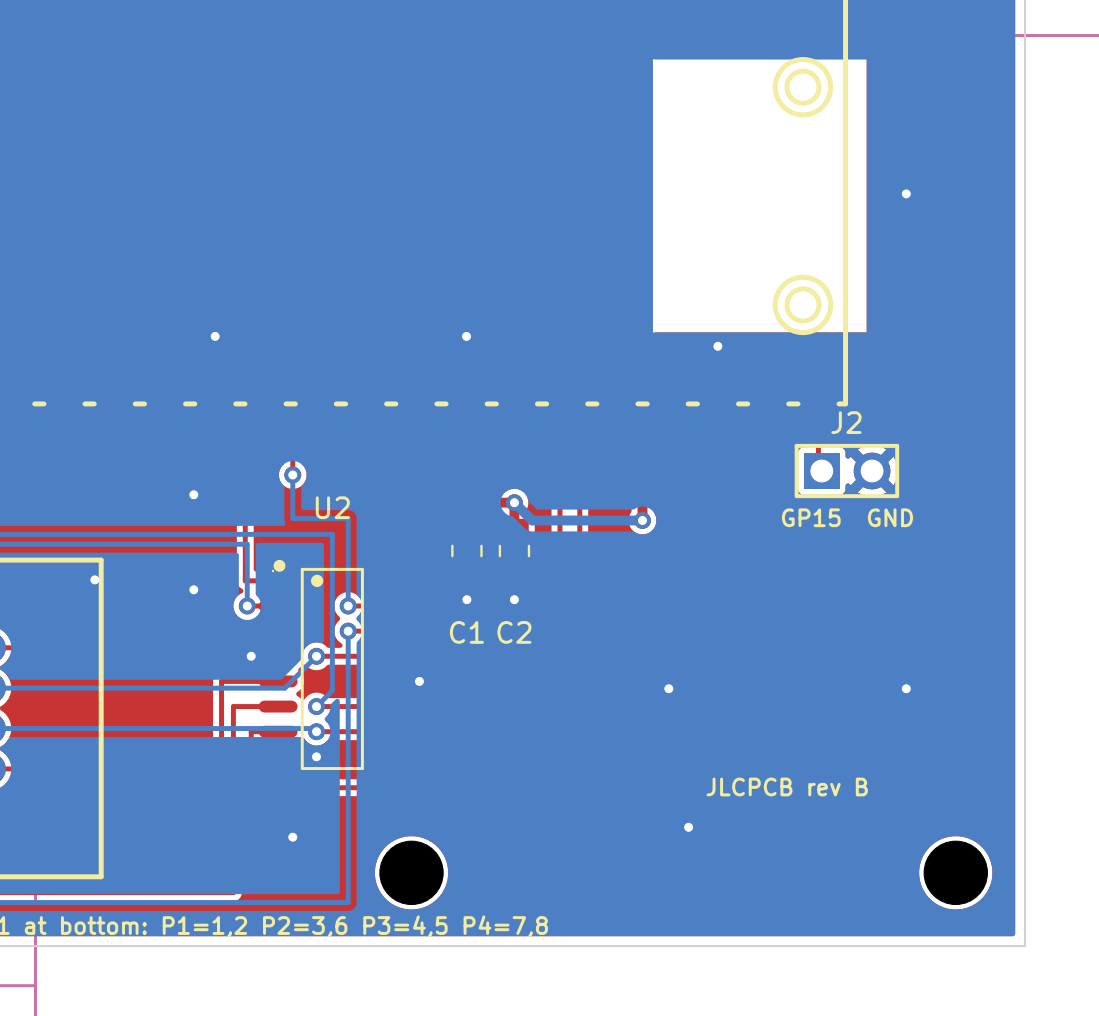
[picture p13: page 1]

GP15 GND USB PICO 2W RS-422 PIXEL DRIVER rev B

Size: A4 | Rev:
KiCad E.D.A. 10.0.6 | Id: 1/1

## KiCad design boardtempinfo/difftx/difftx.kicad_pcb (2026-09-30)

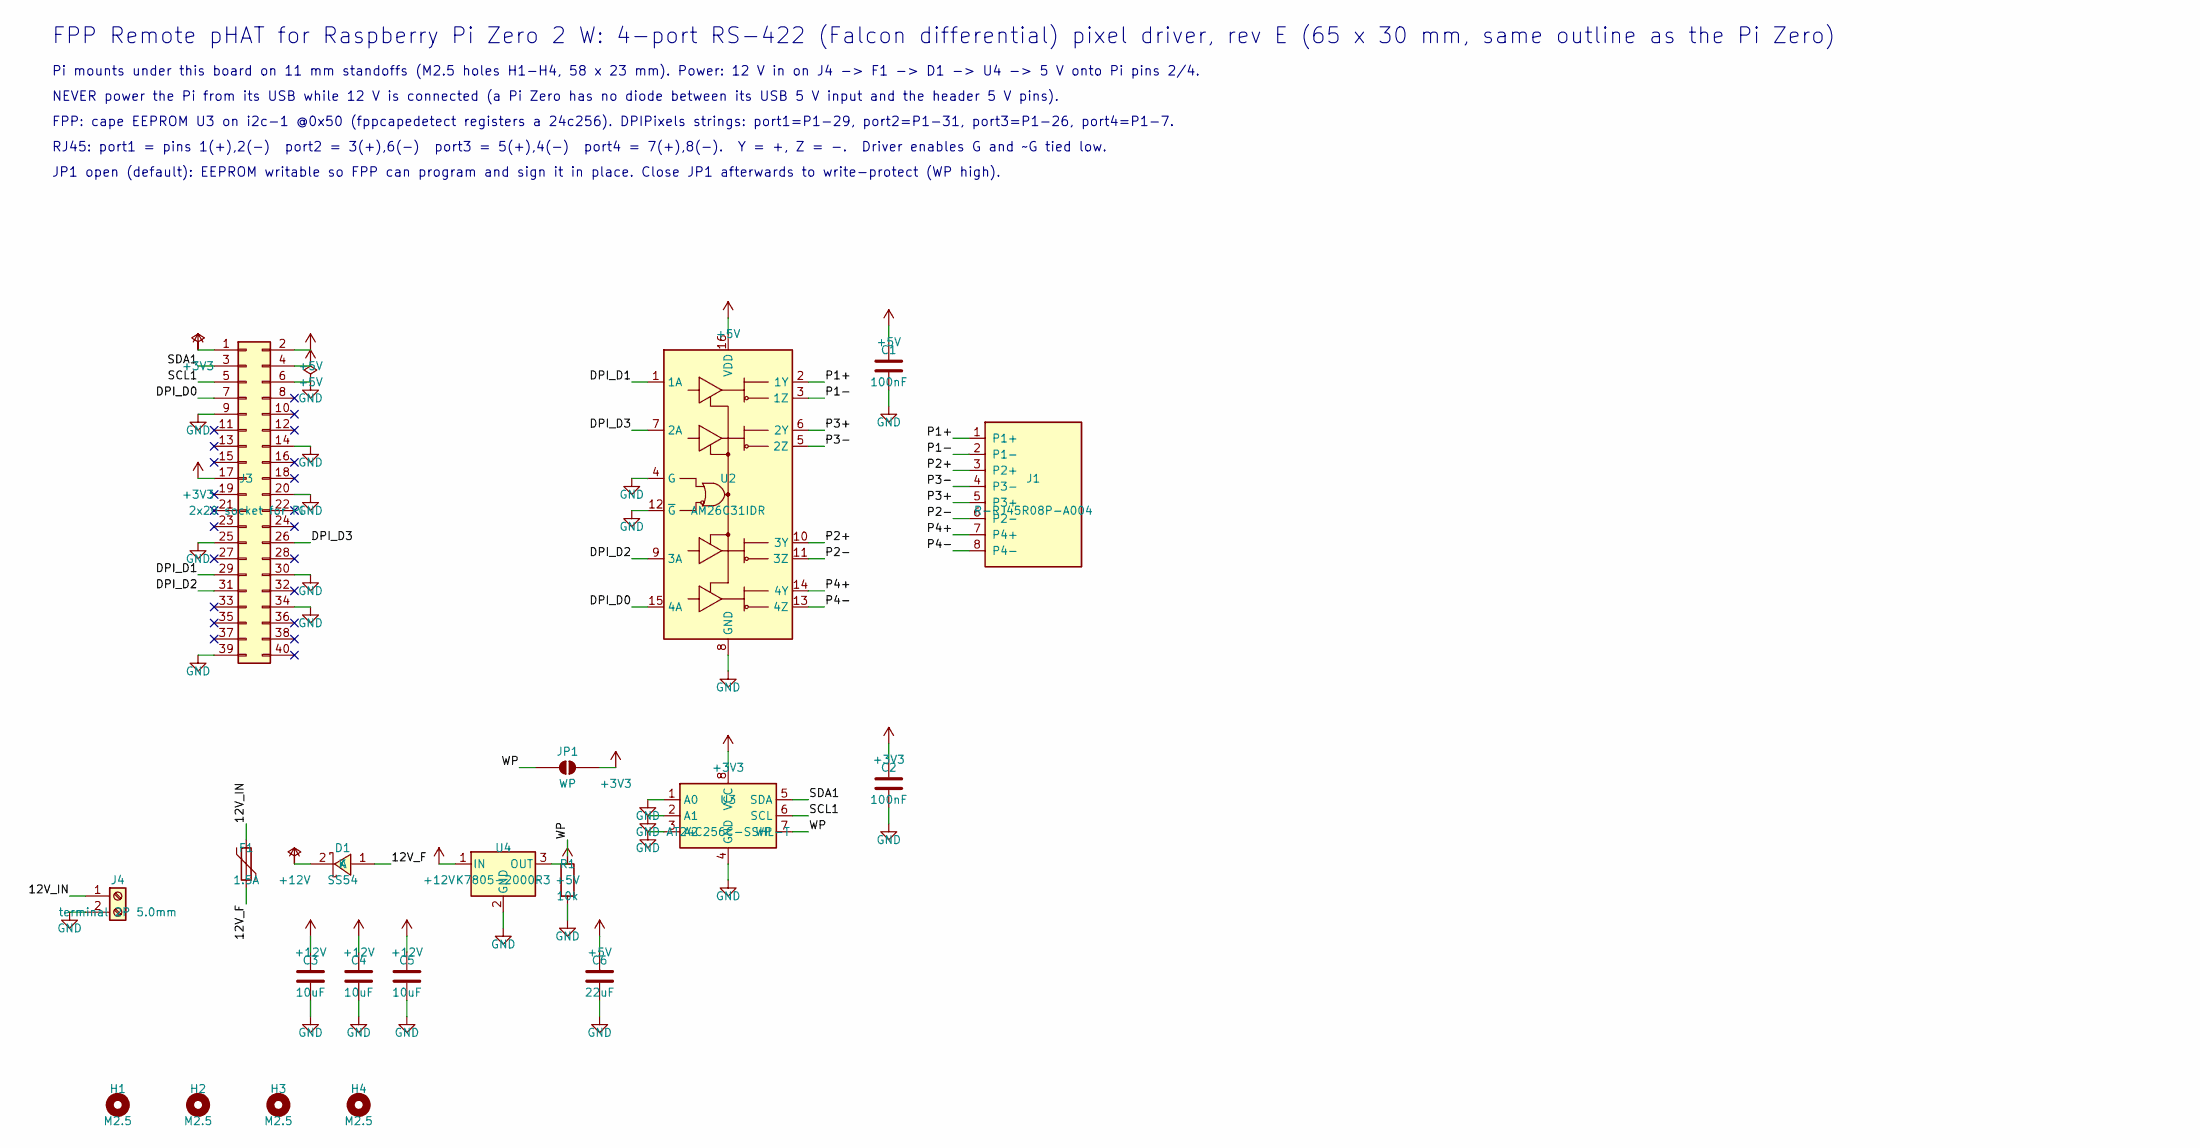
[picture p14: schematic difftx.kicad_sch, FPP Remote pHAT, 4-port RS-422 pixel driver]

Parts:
C1, C2: 100nF; C_0805_2012Metric_Pad1.18x1.45mm_HandSolder; LCSC C49678
C3, C4, C5: 10uF; C_1206_3216Metric; LCSC C89632
C6: 22uF; C_0805_2012Metric_Pad1.18x1.45mm_HandSolder; LCSC C45783
D1: SS54; SMA_L4.4-W2.8-LS5.4-R-RD; LCSC C22452
F1: 1.5A; F1812; LCSC C22392774
H1, H2, H3, H4: M2.5; MountingHole_2.7mm_M2.5
J1: R-RJ45R08P-A004; RJ45-TH_R-RJ45R08P-A004; LCSC C385834
J3: 2x20 socket for Pi; PiSocket_2x20_bottom; LCSC C5124634
J4: terminal 2P 5.0mm; CONN-TH_P5.00_KF301-5.0-2P; LCSC C474881
JP1: WP; SolderJumper-2_P1.3mm_Open_Pad1.0x1.5mm
R1: 10k; R_0603_1608Metric; LCSC C25804
U2: AM26C31IDR; SOIC-16_L9.9-W3.9-P1.27-LS6.0-BL; LCSC C34923
U3: AT24C256C-SSHL-T; SOIC-8_L4.9-W3.9-P1.27-LS6.0-BL; LCSC C6482
U4: K7805-2000R3; PWRM-TH_K78XX-2000R3; LCSC C18212380

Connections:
+3V3: C2.1, J3.1, J3.17, JP1.2 (B), U3.8 (VCC)
+5V: C1.1, C6.1, J3.2, J3.4, U2.16 (VDD), U4.3 (OUT)
+12V: C3.1, C4.1, C5.1, D1.2 (K), U4.1 (IN)
/12V_F: D1.1 (A), F1.2
/12V_IN: F1.1, J4.1
/DPI_D0: J3.7, U2.15 (4A)
/DPI_D1: J3.29, U2.1 (1A)
/DPI_D2: J3.31, U2.9 (3A)
/DPI_D3: J3.26, U2.7 (2A)
/P1+: J1.1 (P1+), U2.2 (1Y)
/P1-: J1.2 (P1-), U2.3 (1Z)
/P2+: J1.3 (P2+), U2.10 (3Y)
/P2-: J1.6 (P2-), U2.11 (3Z)
/P3+: J1.5 (P3+), U2.6 (2Y)
/P3-: J1.4 (P3-), U2.5 (2Z)
/P4+: J1.7 (P4+), U2.14 (4Y)
/P4-: J1.8 (P4-), U2.13 (4Z)
/SCL1: J3.5, U3.6 (SCL)
/SDA1: J3.3, U3.5 (SDA)
/WP: JP1.1 (A), R1.1, U3.7 (WP)
GND: C1.2, C2.2, C3.2, C4.2, C5.2, C6.2, J3.6, J3.9, J3.14, J3.20, J3.25, J3.30, J3.34, J3.39, J4.2, R1.2, U2.4 (G), U2.8 (GND), U2.12 (~G), U3.1 (A0), U3.2 (A1), U3.3 (A2), U3.4 (GND), U4.2 (GND)

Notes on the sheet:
FPP Remote pHAT for Raspberry Pi Zero 2 W: 4-port RS-422 (Falcon differential) pixel driver, rev E (65 x 30 mm, same outline as the Pi Zero)
Pi mounts under this board on 11 mm standoffs (M2.5 holes H1-H4, 58 x 23 mm). Power: 12 V in on J4 -> F1 -> D1 -> U4 -> 5 V onto Pi pins 2/4.
NEVER power the Pi from its USB while 12 V is connected (a Pi Zero has no diode between its USB 5 V input and the header 5 V pins).
FPP: cape EEPROM U3 on i2c-1 @0x50 (fppcapedetect registers a 24c256). DPIPixels strings: port1=P1-29, port2=P1-31, port3=P1-26, port4=P1-7.
RJ45: port1 = pins 1(+),2(-) port2 = 3(+),6(-) port3 = 5(+),4(-) port4 = 7(+),8(-). Y = +, Z = -. Driver enables G and ~G tied low.
JP1 open (default): EEPROM writable so FPP can program and sign it in place. Close JP1 afterwards to write-protect (WP high).

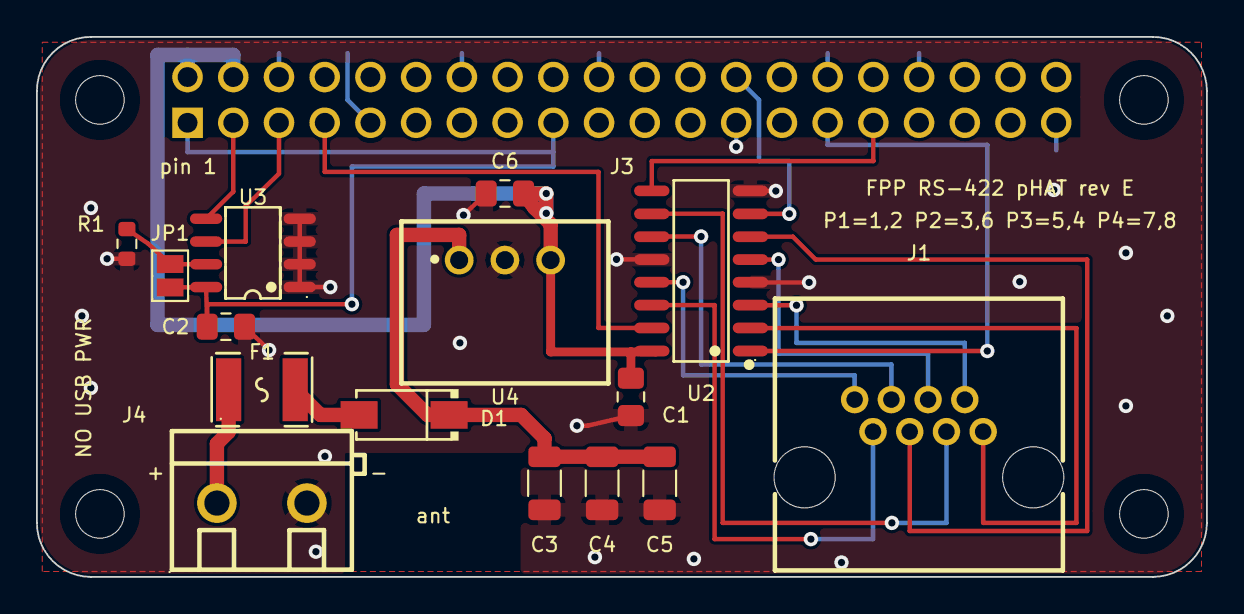
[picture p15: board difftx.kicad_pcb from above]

Board: 2 copper layers, 65.0 x 30.0 mm, 20 parts (1 on the bottom side), 21 nets.

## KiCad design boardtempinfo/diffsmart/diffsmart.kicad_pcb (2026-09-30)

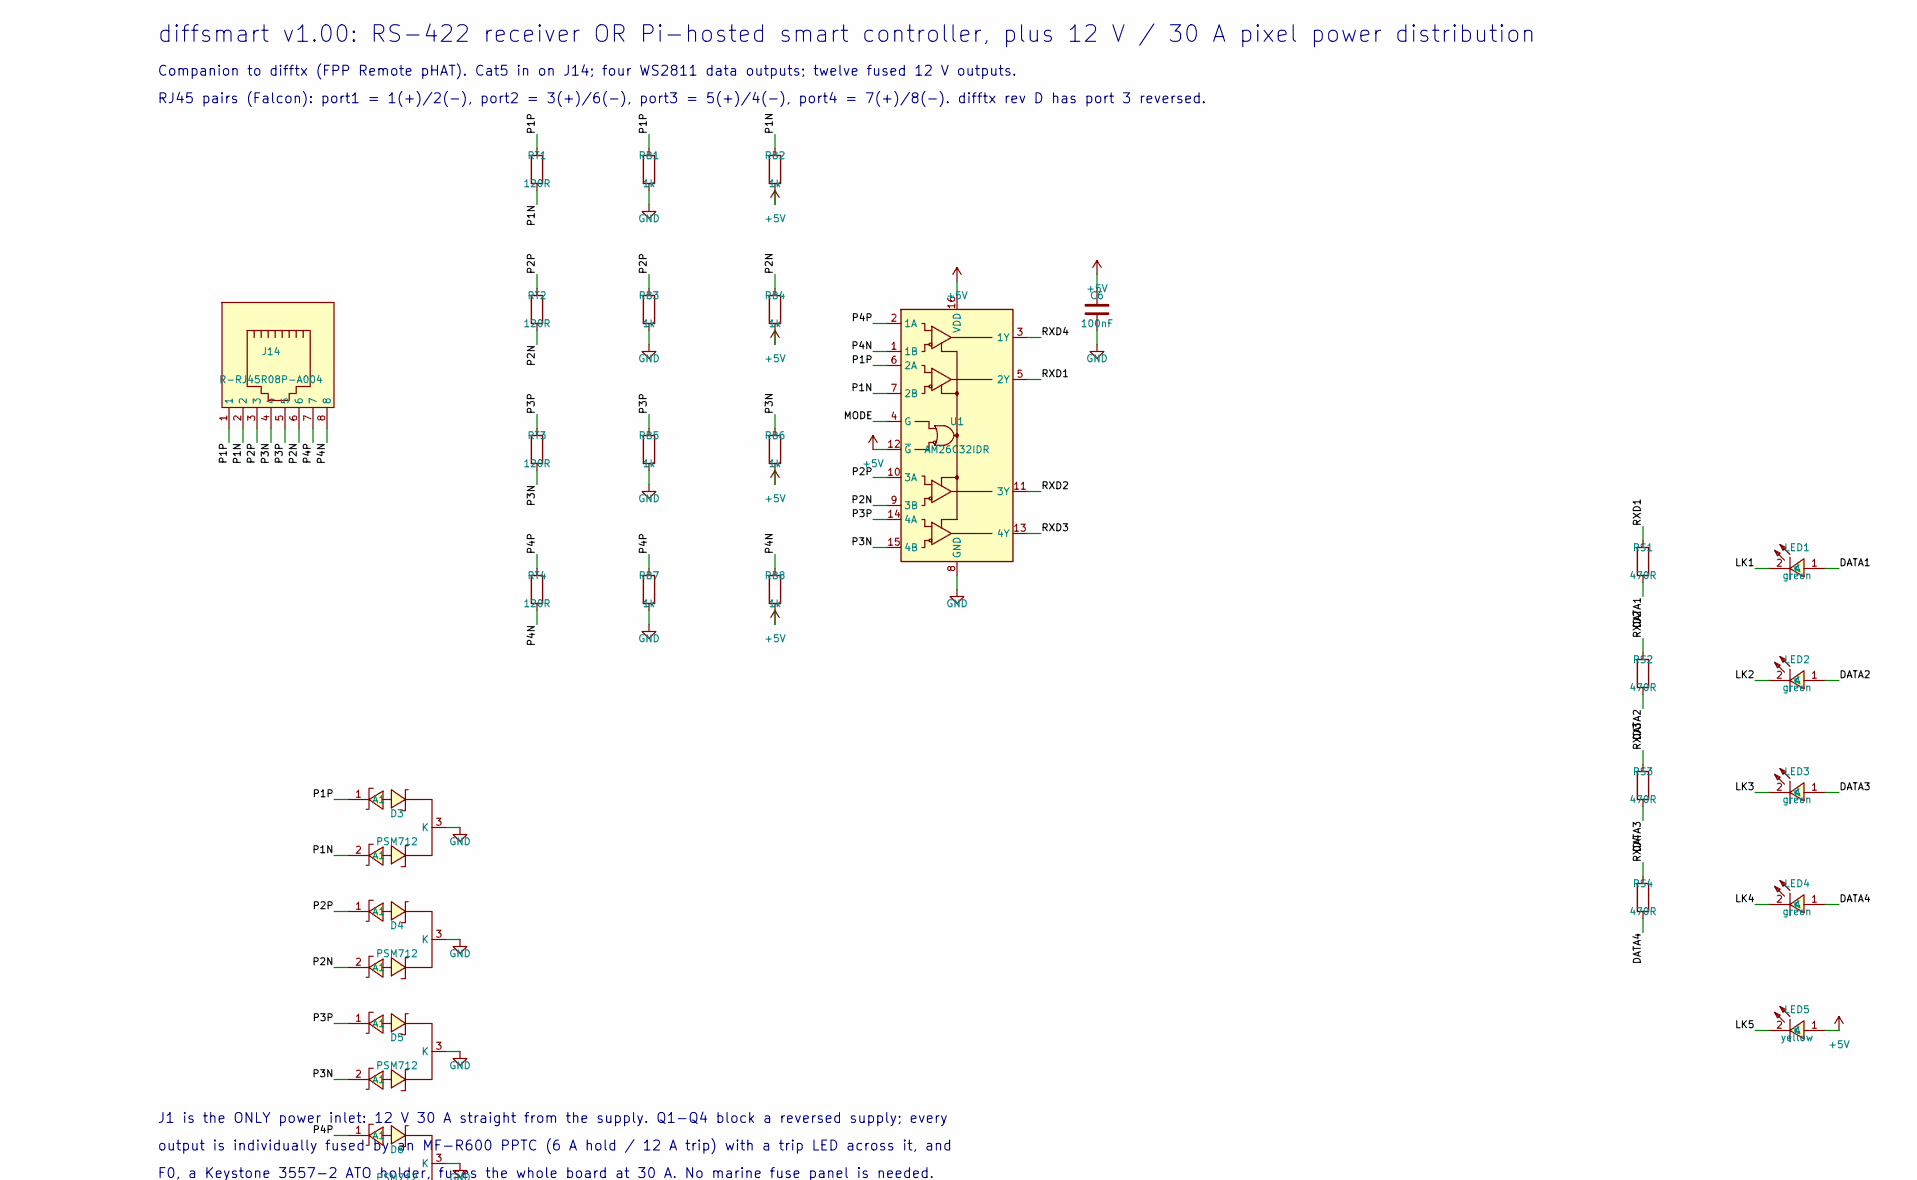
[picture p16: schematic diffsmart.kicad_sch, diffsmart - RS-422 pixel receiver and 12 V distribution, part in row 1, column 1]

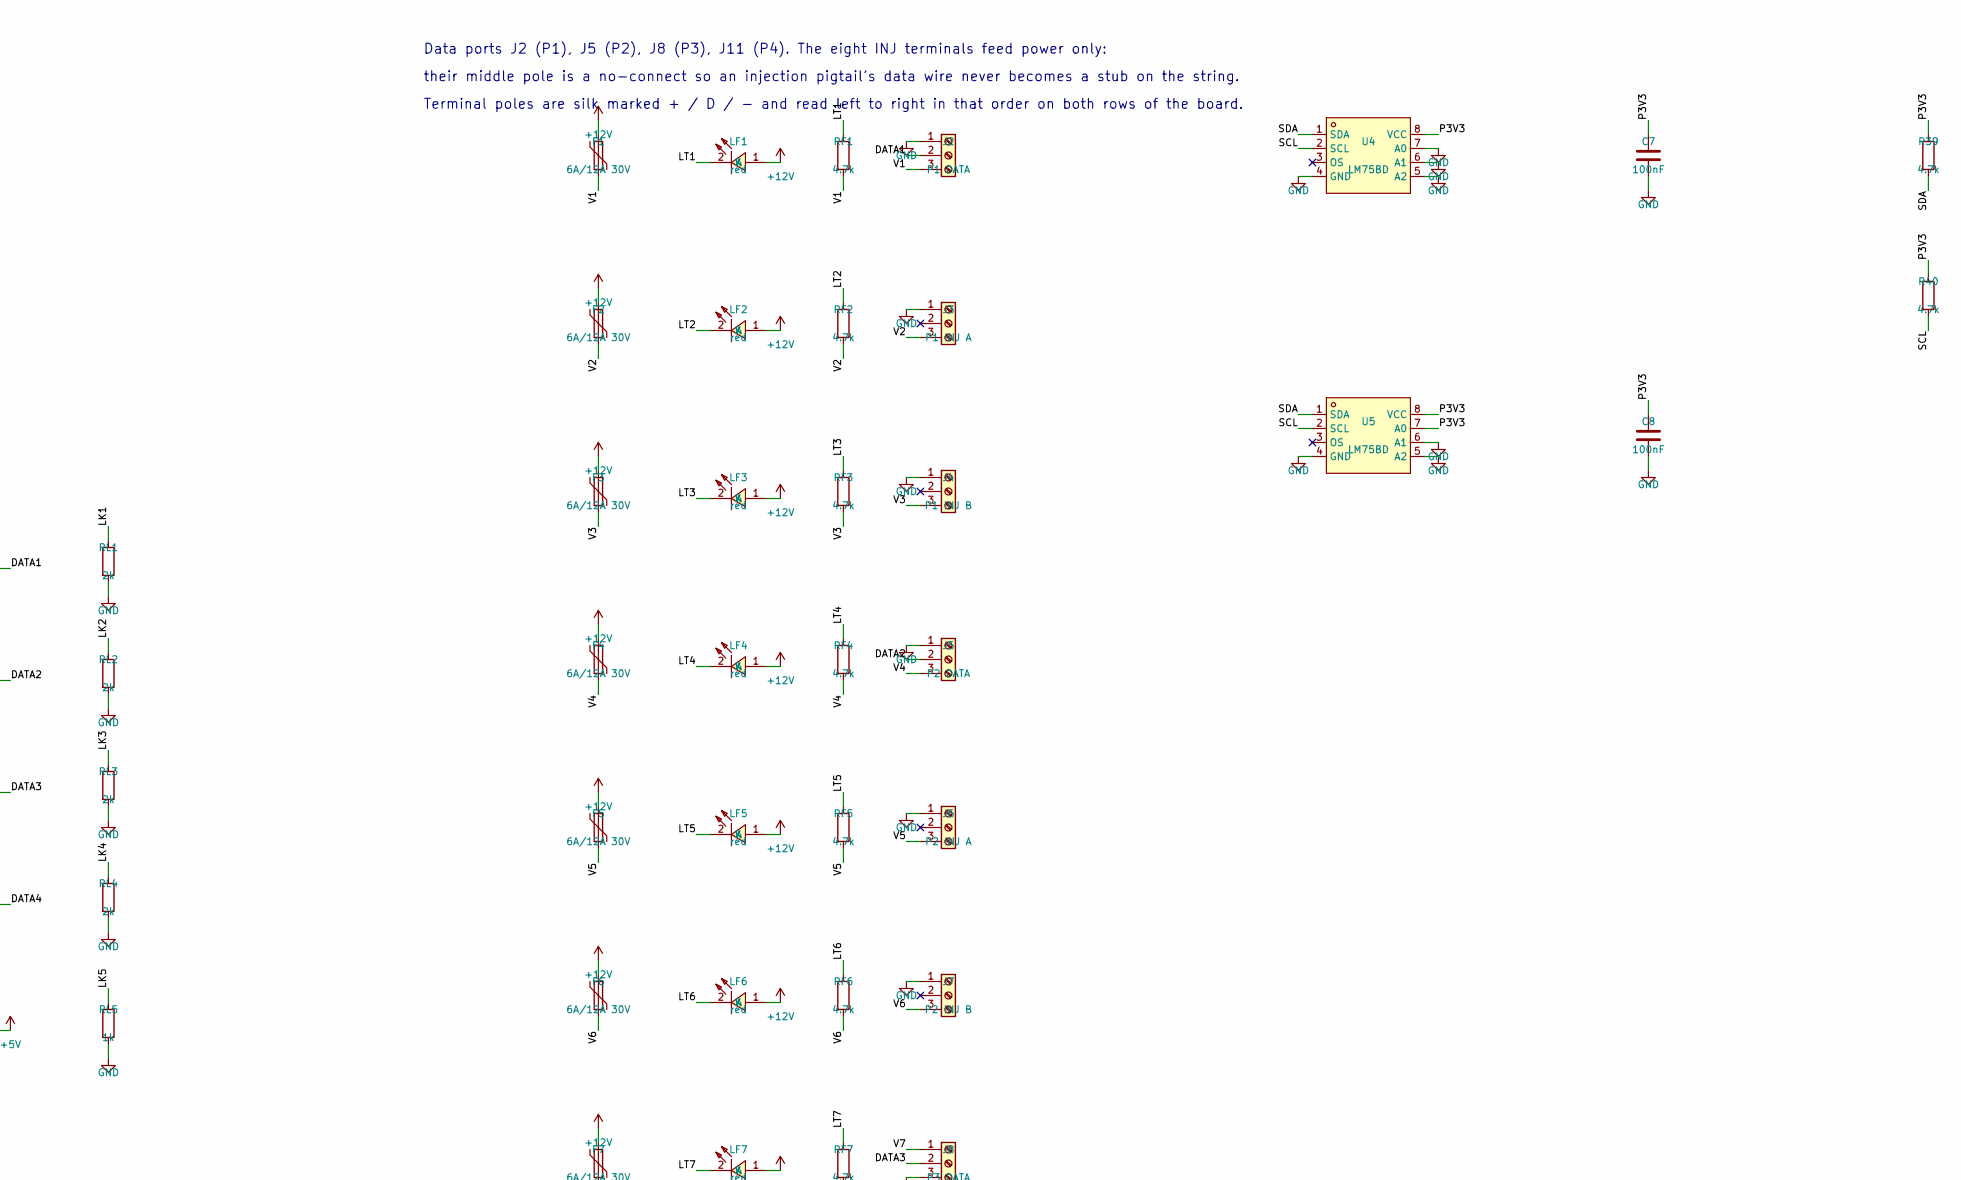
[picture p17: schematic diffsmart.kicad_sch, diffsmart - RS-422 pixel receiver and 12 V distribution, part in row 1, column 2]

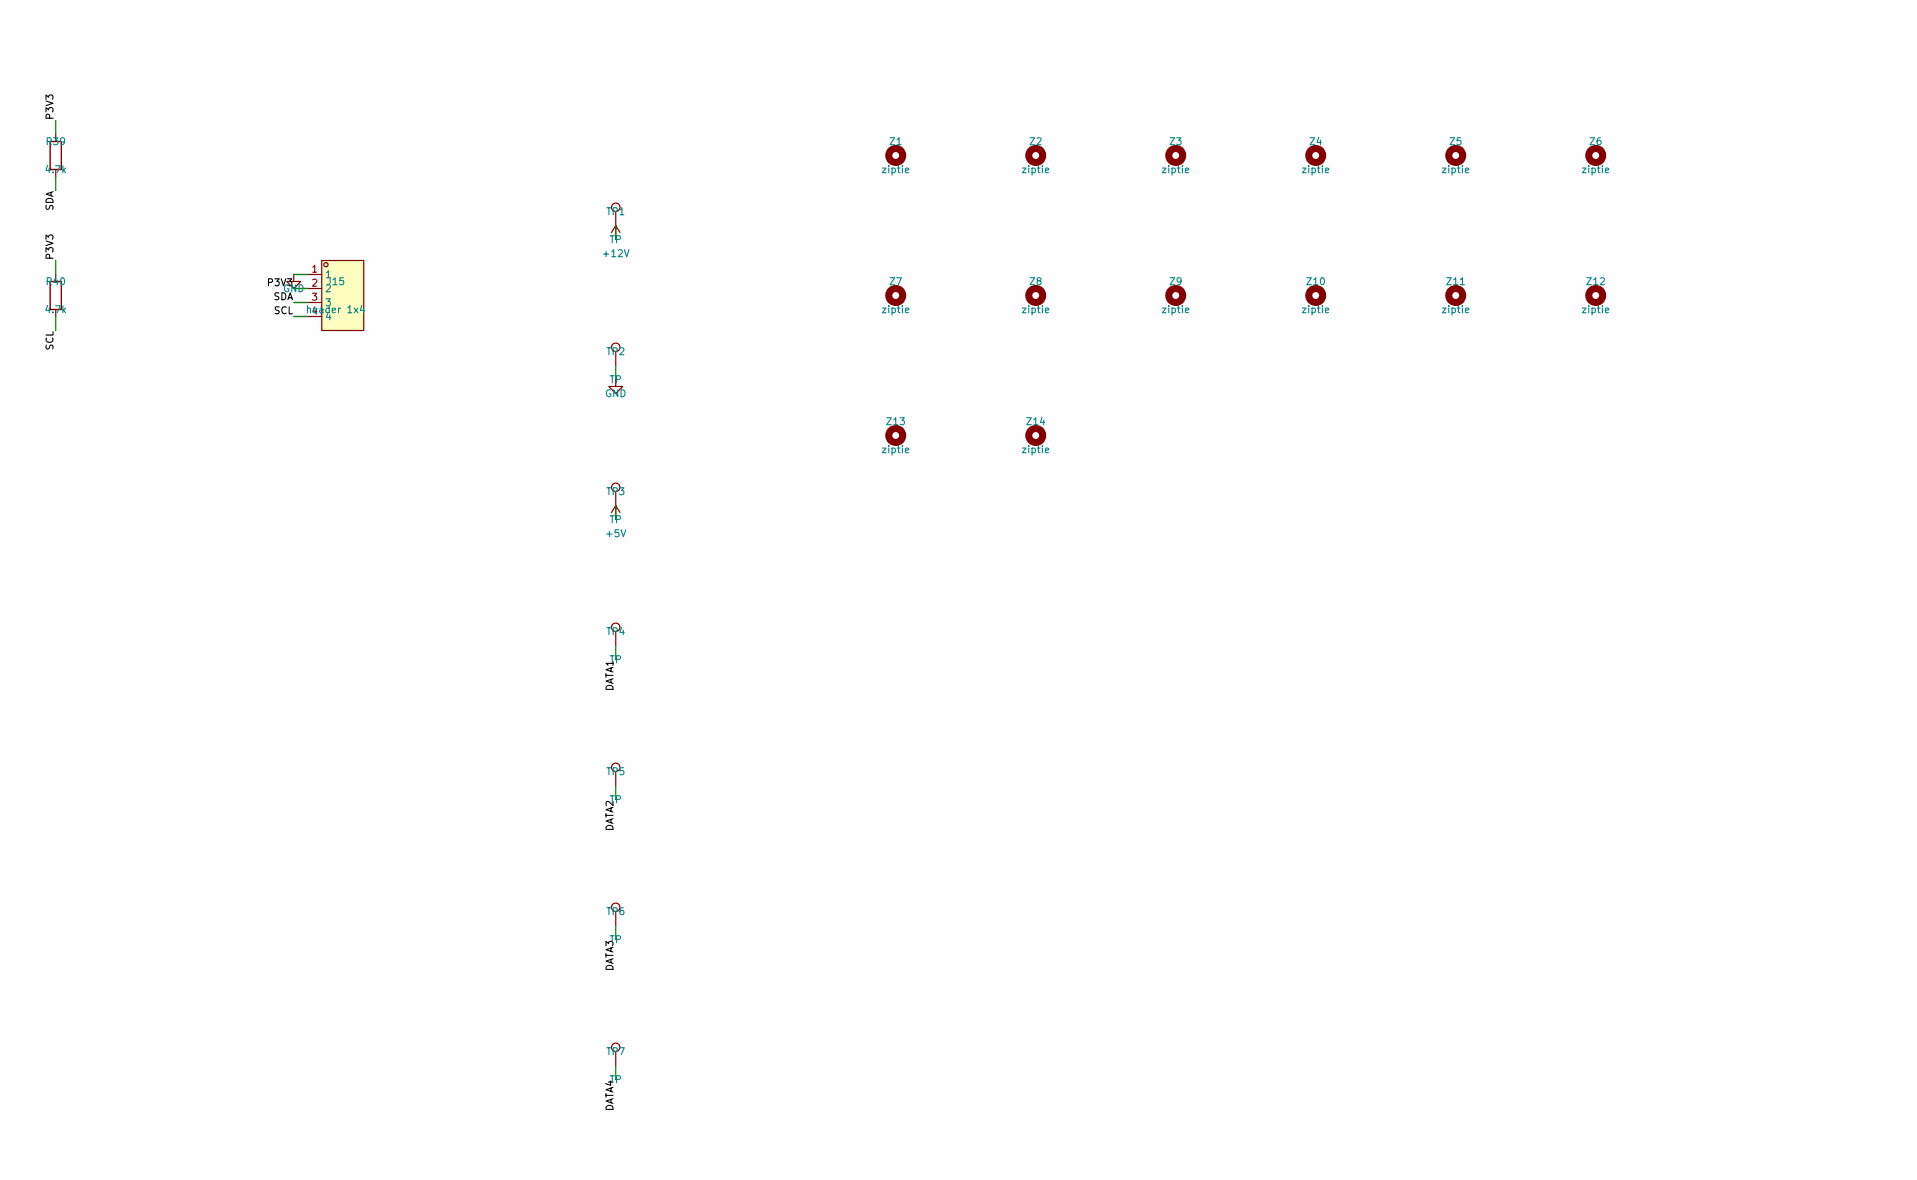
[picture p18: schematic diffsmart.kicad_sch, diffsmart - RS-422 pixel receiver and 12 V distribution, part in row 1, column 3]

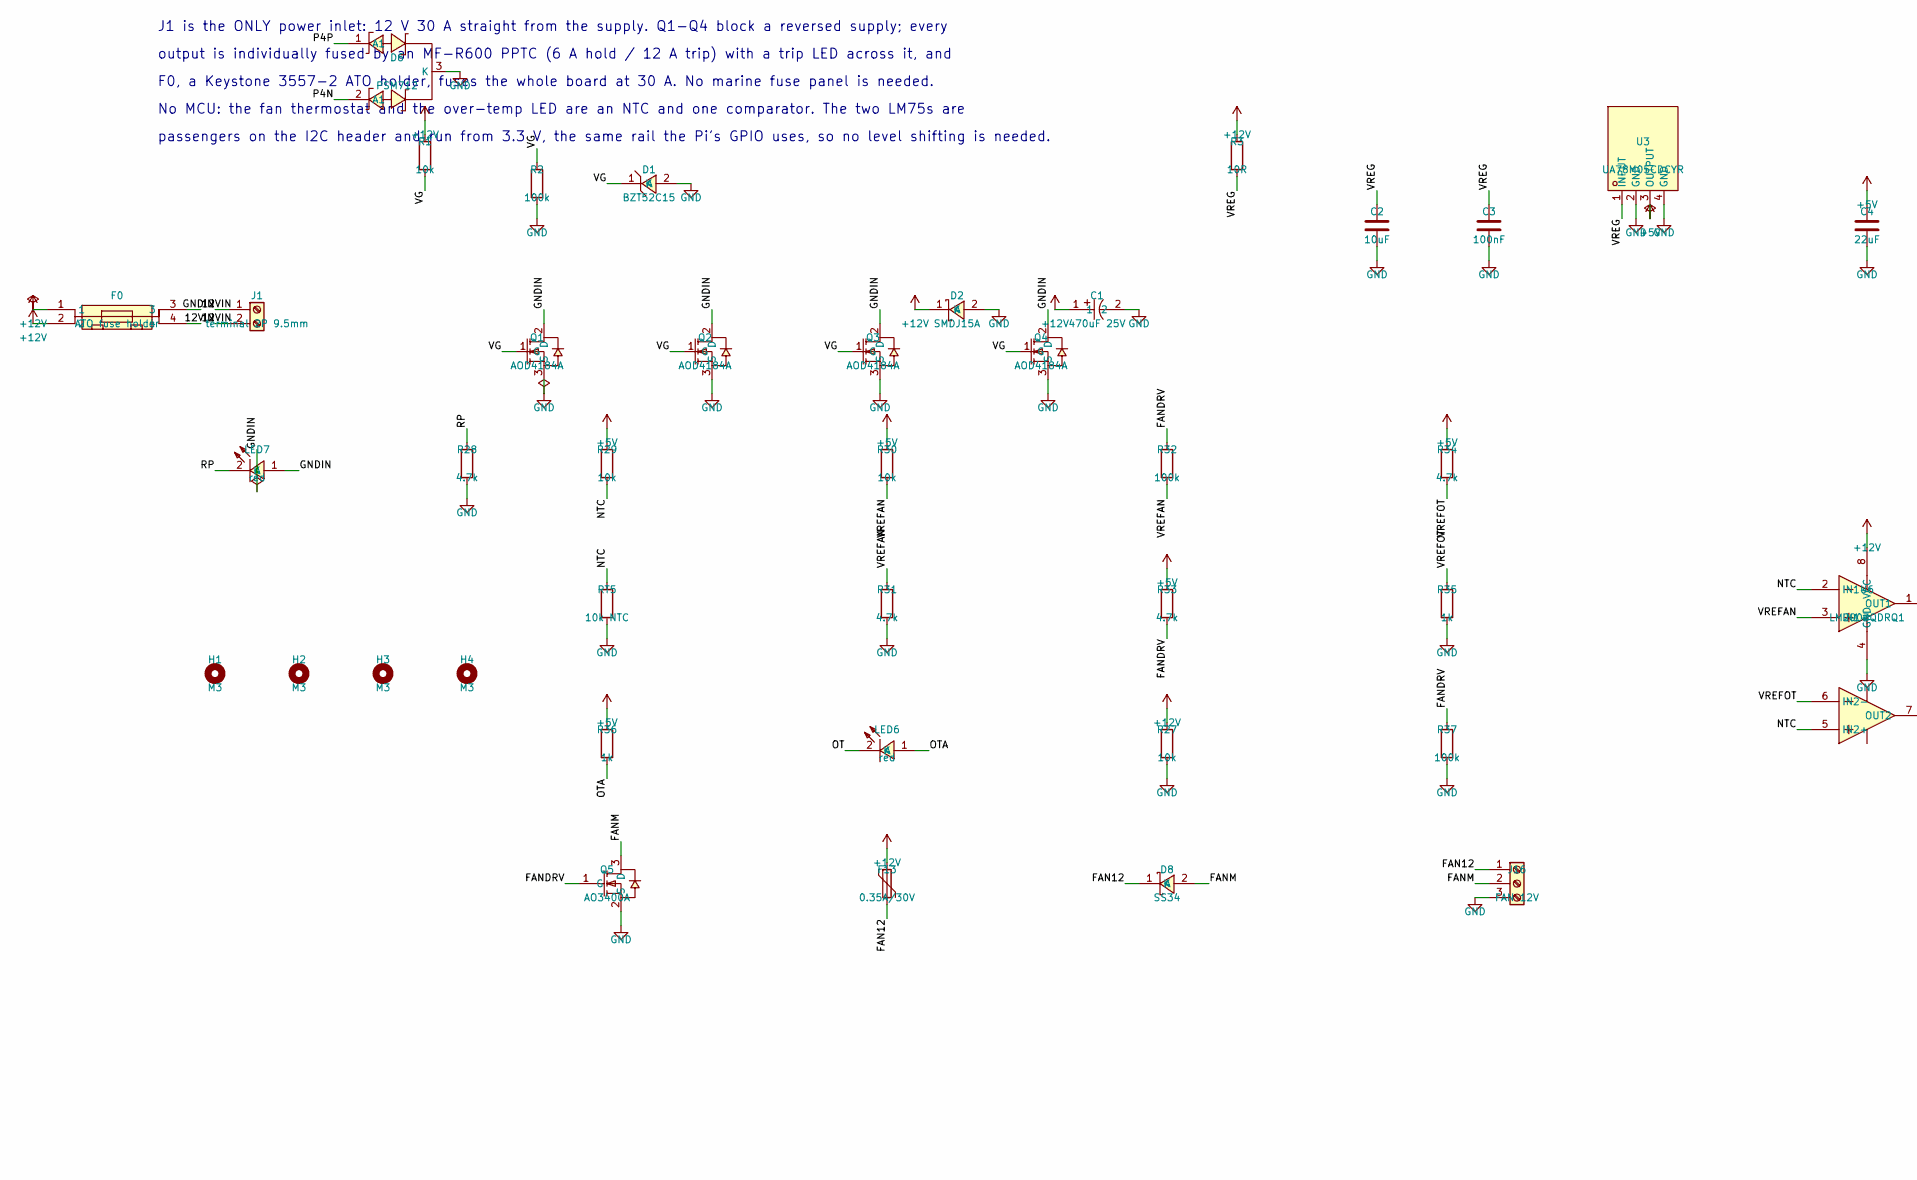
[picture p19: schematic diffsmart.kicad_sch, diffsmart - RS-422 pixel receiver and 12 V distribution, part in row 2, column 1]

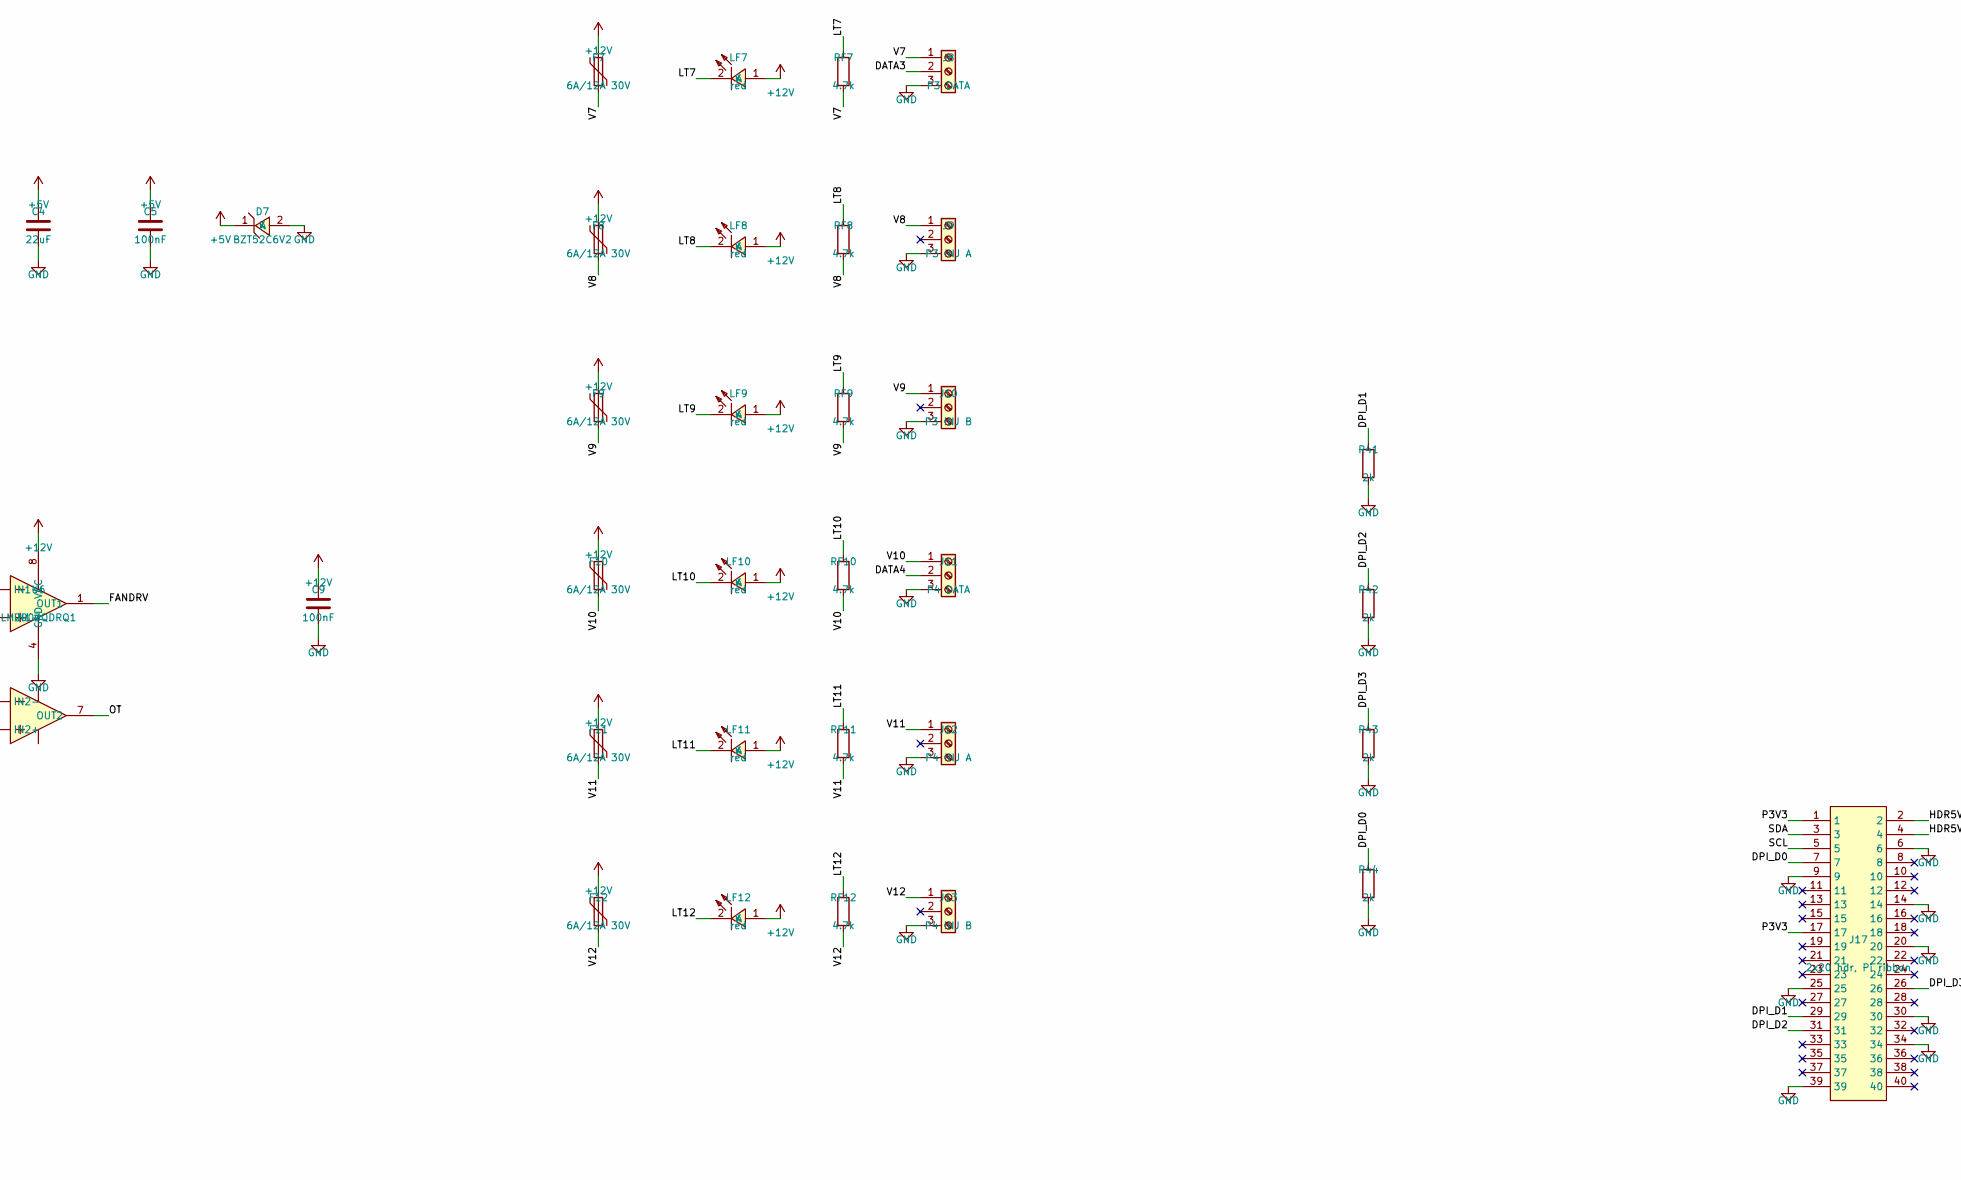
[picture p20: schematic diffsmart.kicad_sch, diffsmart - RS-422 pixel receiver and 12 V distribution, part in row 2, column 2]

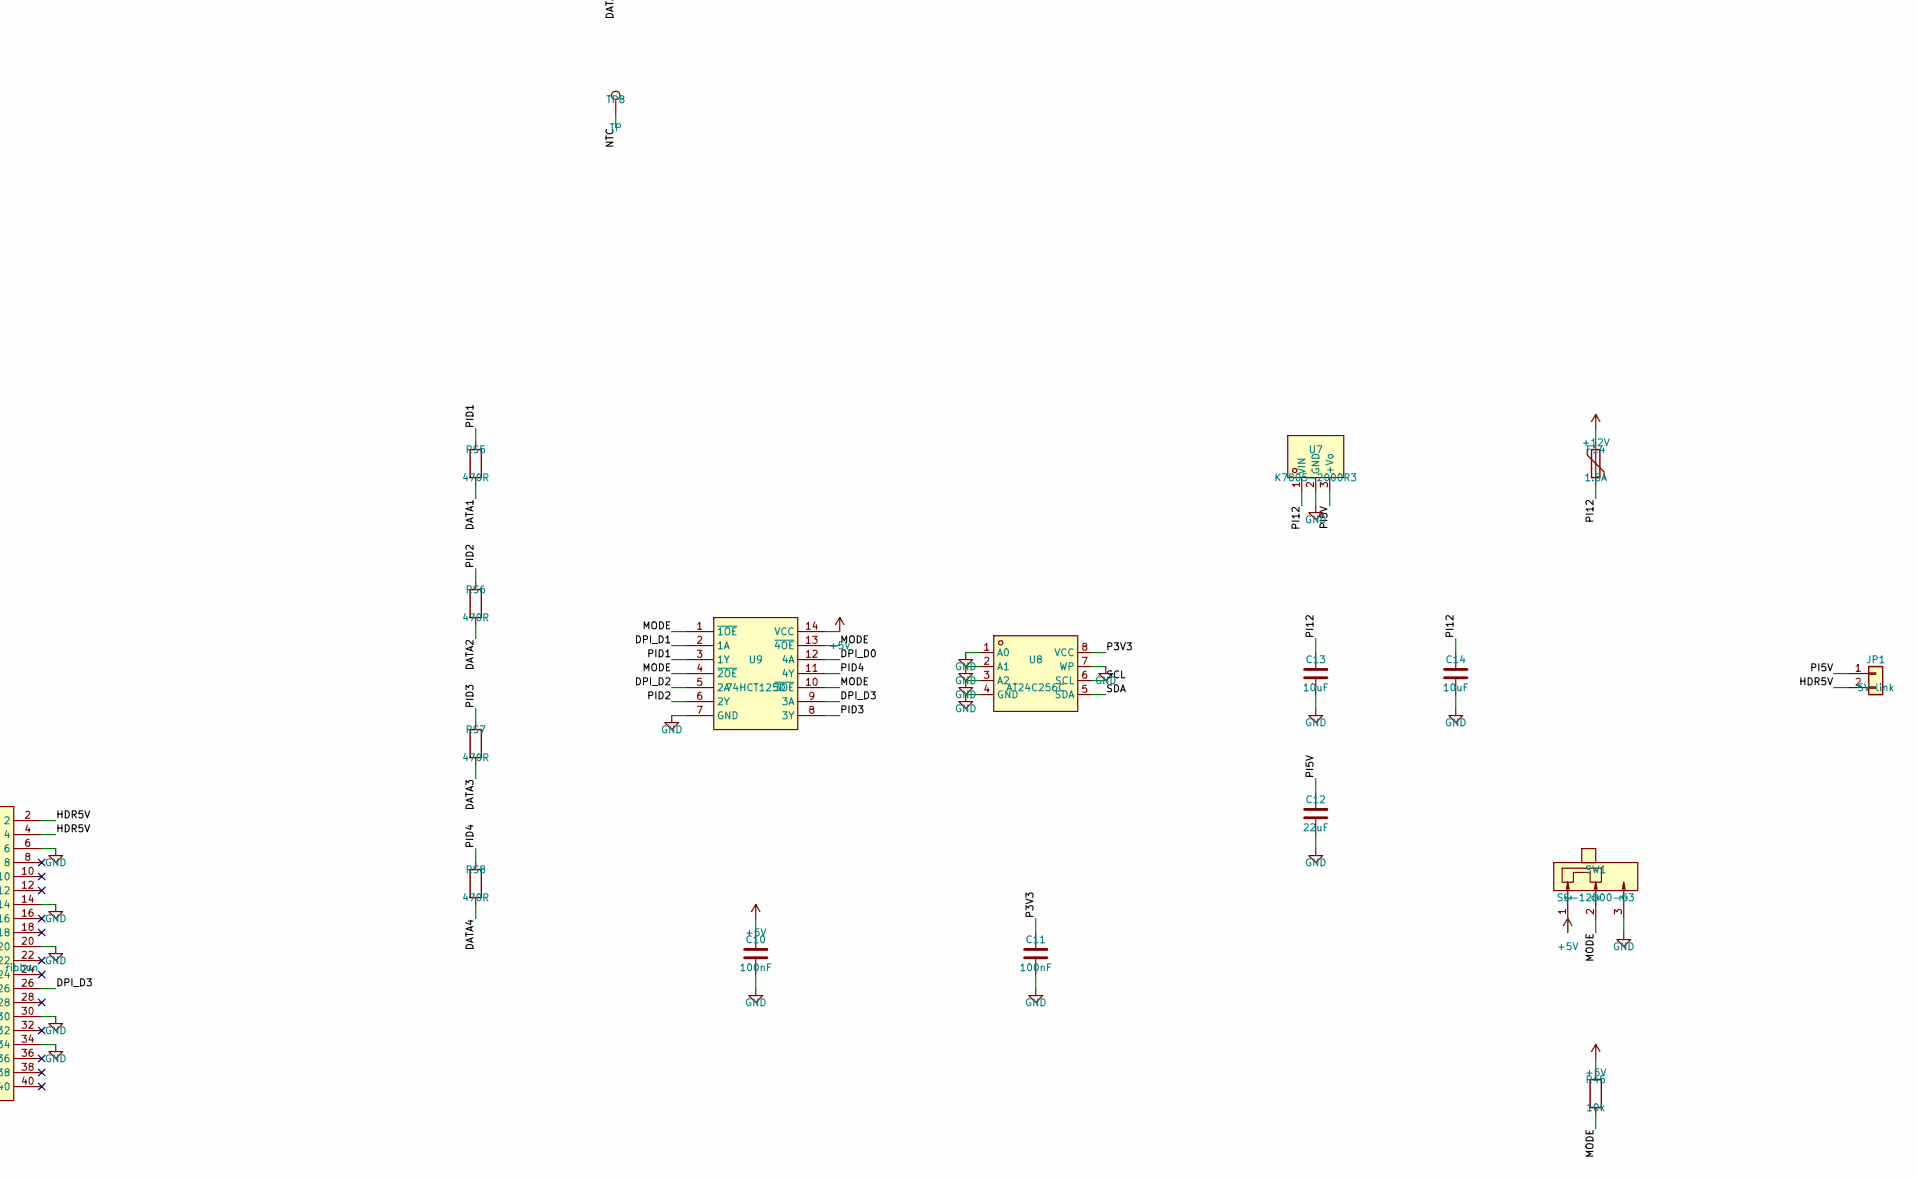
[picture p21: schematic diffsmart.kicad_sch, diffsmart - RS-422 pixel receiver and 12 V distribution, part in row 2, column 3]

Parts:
C1: 470uF 25V; CAP-SMD_BD8.0-L8.3-W8.3-FD; LCSC C4747956
C2, C13, C14: 10uF; C_1206_3216Metric; LCSC C13585
C3, C5, C6, C7, C8, C9, C10, C11: 100nF; C_0805_2012Metric_Pad1.18x1.45mm_HandSolder; LCSC C49678
C4, C12: 22uF; C_0805_2012Metric_Pad1.18x1.45mm_HandSolder; LCSC C45783
D1: BZT52C15; SOD-123_L2.8-W1.8-LS3.7-RD; LCSC C2104
D2: SMDJ15A; SMC_L6.9-W5.9-LS7.9-RD; LCSC C152077
D3, D4, D5, D6: PSM712; SOT-23-3_L3.0-W1.7-P0.95-LS2.9-BR; LCSC C32677
D7: BZT52C6V2; SOD-123_L2.8-W1.8-LS3.7-RD; LCSC C173405
D8: SS34; SMA_L4.3-W2.6-LS5.2-RD; LCSC C8678
F0: ATO fuse holder; FUSE-TH_4P-L19.8-W6.7_3557-2; LCSC C352820
F1, F2, F3, F4, F5, F6, F7, F8, F9, F10, F11, F12: 6A/12A 30V; FUSE-TH_L19.1-W3.0-P10.20-D1.2-S2.0; LCSC C208490
F13: 0.35A/30V; Fuse_1206_3216Metric; LCSC C2876002
F14: 1.5A; F1812; LCSC C22392774
H1, H2, H3, H4: M3; MountingHole_3.2mm_M3
J1: terminal 2P 9.5mm; CONN-TH_P9.50_KF950-9.5-2P; LCSC C475106
J2: P1 DATA; CONN-TH_3P-P5.00_KF301-5.0-3P; LCSC C474882
J3: P1 INJ A; CONN-TH_3P-P5.00_KF301-5.0-3P; LCSC C474882
J4: P1 INJ B; CONN-TH_3P-P5.00_KF301-5.0-3P; LCSC C474882
J5: P2 DATA; CONN-TH_3P-P5.00_KF301-5.0-3P; LCSC C474882
J6: P2 INJ A; CONN-TH_3P-P5.00_KF301-5.0-3P; LCSC C474882
J7: P2 INJ B; CONN-TH_3P-P5.00_KF301-5.0-3P; LCSC C474882
J8: P3 DATA; CONN-TH_3P-P5.00_KF301-5.0-3P; LCSC C474882
J9: P3 INJ A; CONN-TH_3P-P5.00_KF301-5.0-3P; LCSC C474882
J10: P3 INJ B; CONN-TH_3P-P5.00_KF301-5.0-3P; LCSC C474882
J11: P4 DATA; CONN-TH_3P-P5.00_KF301-5.0-3P; LCSC C474882
J12: P4 INJ A; CONN-TH_3P-P5.00_KF301-5.0-3P; LCSC C474882
J13: P4 INJ B; CONN-TH_3P-P5.00_KF301-5.0-3P; LCSC C474882
J14: R-RJ45R08P-A004; RJ45-TH_R-RJ45R08P-A004; LCSC C385834
J15: header 1x4; HDR-TH_4P-P2.54-V-M; LCSC C124378
J16: FAN 12V; CONN-TH_3P-P5.00_KF301-5.0-3P; LCSC C474882
J17: 2x20 hdr, Pi ribbon; PiRibbon_2x20_P2.54mm; LCSC C50980
JP1: 5V link; PinHeader_1x02_P2.54mm_Vertical; LCSC C124375
LED1, LED2, LED3, LED4: green; LED0805-R-RD; LCSC C2297
LED5: yellow; LED0805-R-RD; LCSC C2296
LED6, LED7: red; LED0805-R-RD; LCSC C2295
LF1, LF2, LF3, LF4, LF5, LF6, LF7, LF8, LF9, LF10, LF11, LF12: red; LED0805-R-RD; LCSC C2295
Q1, Q2, Q3, Q4: AOD4184A; TO-252-2_L6.6-W6.1-P4.57-LS9.9-TL-CW; LCSC C99124
Q5: AO3400A; SOT-23-3_L2.9-W1.3-P1.90-LS2.4-BR; LCSC C20917
R1, R27, R29, R30, R45: 10k; R_0603_1608Metric; LCSC C25804
R2, R32, R37: 100k; R_0603_1608Metric; LCSC C25803
R3: 10R; R_0603_1608Metric; LCSC C22859
R28, R31, R33, R34, R39, R40: 4.7k; R_0603_1608Metric; LCSC C23162
R35, R36: 1k; R_0603_1608Metric; LCSC C21190
R41, R42, R43, R44: 2k; R_0603_1608Metric; LCSC C22975
RB1, RB2, RB3, RB4, RB5, RB6, RB7, RB8: 1k; R_0603_1608Metric; LCSC C21190
RF1, RF2, RF3, RF4, RF5, RF6, RF7, RF8, RF9, RF10, RF11, RF12: 4.7k; R_0603_1608Metric; LCSC C23162
RL1, RL2, RL3, RL4: 2k; R_0603_1608Metric; LCSC C22975
RL5: 1k; R_0603_1608Metric; LCSC C21190
RS1, RS2, RS3, RS4, RS5, RS6, RS7, RS8: 470R; R_0603_1608Metric; LCSC C23179
RT1, RT2, RT3, RT4: 120R; R_1206_3216Metric; LCSC C17909
RT5: 10k NTC; R_0805_2012Metric; LCSC C3195213
SW1: SS-12D00-G3; SW-TH_3P-L8.8-W3.9-P2.50_SS12D00G3; LCSC C22355741
TP1, TP2, TP3, TP4, TP5, TP6, TP7, TP8: TP; TestPoint_Pad_D1.5mm
U1: AM26C32IDR; SOIC-16_L9.9-W3.9-P1.27-LS6.0-BL; LCSC C36693
U3: UA78M05CDCYR; SOT-223_L6.5-W3.5-P2.30-LS7.0-BR; LCSC C201654
U4, U5: LM75BD; SOIC-8_L5.0-W4.0-P1.27-LS6.0-BL; LCSC C34565
U6: LM2903QDRQ1; SOIC-8_L4.9-W3.9-P1.27-LS6.0-BL; LCSC C475499
U7: K7805-2000R3; PWRM-TH_K78XX-2000R3; LCSC C18212380
U8: AT24C256C; SOIC-8_L4.9-W3.9-P1.27-LS6.0-BL; LCSC C6482
U9: 74HCT125D; SOIC-14_L8.7-W3.9-P1.27-LS6.0-BL; LCSC C5962
Z1, Z2, Z3, Z4, Z5, Z6, Z7, Z8, Z9, Z10, Z11, Z12, Z13, Z14: ziptie; ZipTie_3.0mm

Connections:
+5V: C4.1, C5.1, C6.1, C10.1, D7.1 (K), LED5.1 (A), R29.1, R30.1, R33.1, R34.1, R36.1, R45.1, RB2.2, RB4.2, RB6.2, RB8.2, SW1.1, TP3.1, U1.12 (~G), U1.16 (VDD), U3.3 (OUTPUT), U9.14 (VCC)
+12V: C1.1, C9.1, D2.1 (K), F0.1, F0.2, F1.1, F2.1, F3.1, F4.1, F5.1, F6.1, F7.1, F8.1, F9.1, F10.1, F11.1, F12.1, F13.1, F14.1, LF1.1 (A), LF2.1 (A), LF3.1 (A), LF4.1 (A), LF5.1 (A), LF6.1 (A), LF7.1 (A), LF8.1 (A), LF9.1 (A), LF10.1 (A), LF11.1 (A), LF12.1 (A), R1.1, R3.1, R27.1, TP1.1, U6.8 (VCC)
/12VIN: F0.3, F0.4, J1.2
/DATA1: J2.2, LED1.1 (A), RS1.2, RS5.2, TP4.1
/DATA2: J5.2, LED2.1 (A), RS2.2, RS6.2, TP5.1
/DATA3: J8.2, LED3.1 (A), RS3.2, RS7.2, TP6.1
/DATA4: J11.2, LED4.1 (A), RS4.2, RS8.2, TP7.1
/DPI_D0: J17.7, R44.1, U9.12 (4A)
/DPI_D1: J17.29, R41.1, U9.2 (1A)
/DPI_D2: J17.31, R42.1, U9.5 (2A)
/DPI_D3: J17.26, R43.1, U9.9 (3A)
/FAN12: D8.1 (K), F13.2, J16.1
/FANDRV: Q5.1 (G), R32.1, R33.2, R37.1, U6.1 (OUT1)
/FANM: D8.2 (A), J16.2, Q5.3 (D)
/GNDIN: J1.1, LED7.1 (A), Q1.2 (D), Q2.2 (D), Q3.2 (D), Q4.2 (D)
/HDR5V: J17.2, J17.4, JP1.2
/LK1: LED1.2 (K), RL1.1
/LK2: LED2.2 (K), RL2.1
/LK3: LED3.2 (K), RL3.1
/LK4: LED4.2 (K), RL4.1
/LK5: LED5.2 (K), RL5.1
/LT1: LF1.2 (K), RF1.1
/LT2: LF2.2 (K), RF2.1
/LT3: LF3.2 (K), RF3.1
/LT4: LF4.2 (K), RF4.1
/LT5: LF5.2 (K), RF5.1
/LT6: LF6.2 (K), RF6.1
/LT7: LF7.2 (K), RF7.1
/LT8: LF8.2 (K), RF8.1
/LT9: LF9.2 (K), RF9.1
/LT10: LF10.2 (K), RF10.1
/LT11: LF11.2 (K), RF11.1
/LT12: LF12.2 (K), RF12.1
/MODE: R45.2, SW1.2, U1.4 (G), U9.1 (~1OE), U9.4 (~2OE), U9.10 (~3OE), U9.13 (~4OE)
/NTC: R29.2, RT5.1, TP8.1, U6.2 (IN1-), U6.5 (IN2+)
/OT: LED6.2 (K), U6.7 (OUT2)
/OTA: LED6.1 (A), R36.2
/P1N: D3.2 (A1), J14.2, RB2.1, RT1.2, U1.7 (2B)
/P1P: D3.1 (A1), J14.1, RB1.1, RT1.1, U1.6 (2A)
/P2N: D4.2 (A1), J14.6, RB4.1, RT2.2, U1.9 (3B)
/P2P: D4.1 (A1), J14.3, RB3.1, RT2.1, U1.10 (3A)
/P3N: D5.2 (A1), J14.4, RB6.1, RT3.2, U1.15 (4B)
/P3P: D5.1 (A1), J14.5, RB5.1, RT3.1, U1.14 (4A)
/P3V3: C7.1, C8.1, C11.1, J15.2, J17.1, J17.17, R39.1, R40.1, U4.8 (VCC), U5.7 (A0), U5.8 (VCC), U8.8 (VCC)
/P4N: D6.2 (A1), J14.8, RB8.1, RT4.2, U1.1 (1B)
/P4P: D6.1 (A1), J14.7, RB7.1, RT4.1, U1.2 (1A)
/PI5V: C12.1, JP1.1, U7.3 (+Vo)
/PI12: C13.1, C14.1, F14.2, U7.1 (VIN)
/PID1: RS5.1, U9.3 (1Y)
/PID2: RS6.1, U9.6 (2Y)
/PID3: RS7.1, U9.8 (3Y)
/PID4: RS8.1, U9.11 (4Y)
/RP: LED7.2 (K), R28.1
/RXD1: RS1.1, U1.5 (2Y)
/RXD2: RS2.1, U1.11 (3Y)
/RXD3: RS3.1, U1.13 (4Y)
/RXD4: RS4.1, U1.3 (1Y)
/SCL: J15.4, J17.5, R40.2, U4.2 (SCL), U5.2 (SCL), U8.6 (SCL)
/SDA: J15.3, J17.3, R39.2, U4.1 (SDA), U5.1 (SDA), U8.5 (SDA)
/V1: F1.2, J2.3, RF1.2
/V2: F2.2, J3.3, RF2.2
/V3: F3.2, J4.3, RF3.2
/V4: F4.2, J5.3, RF4.2
/V5: F5.2, J6.3, RF5.2
/V6: F6.2, J7.3, RF6.2
/V7: F7.2, J8.1, RF7.2
/V8: F8.2, J9.1, RF8.2
/V9: F9.2, J10.1, RF9.2
/V10: F10.2, J11.1, RF10.2
/V11: F11.2, J12.1, RF11.2
/V12: F12.2, J13.1, RF12.2
/VG: D1.1 (K), Q1.1 (G), Q2.1 (G), Q3.1 (G), Q4.1 (G), R1.2, R2.1
/VREFAN: R30.2, R31.1, R32.2, U6.3 (IN1+)
/VREFOT: R34.2, R35.1, U6.6 (IN2-)
/VREG: C2.1, C3.1, R3.2, U3.1 (INPUT)
GND: C1.2, C2.2, C3.2, C4.2, C5.2, C6.2, C7.2, C8.2, C9.2, C10.2, C11.2, C12.2, C13.2, C14.2, D1.2 (A), D2.2 (A), D3.3 (K), D4.3 (K), D5.3 (K), D6.3 (K), D7.2 (A), J2.1, J3.1, J4.1, J5.1, J6.1, J7.1, J8.3, J9.3, J10.3, J11.3, J12.3, J13.3, J15.1, J16.3, J17.6, J17.9, J17.14, J17.20, J17.25, J17.30, J17.34, J17.39, Q1.3 (S), Q2.3 (S), Q3.3 (S), Q4.3 (S), Q5.2 (S), R2.2, R27.2, R28.2, R31.2, R35.2, R37.2, R41.2, R42.2, R43.2, R44.2, RB1.2, RB3.2, RB5.2, RB7.2, RL1.2, RL2.2, RL3.2, RL4.2, RL5.2, RT5.2, SW1.3, TP2.1, U1.8 (GND), U3.2 (GND), U3.4 (GND), U4.4 (GND), U4.5 (A2), U4.6 (A1), U4.7 (A0), U5.4 (GND), U5.5 (A2), U5.6 (A1)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

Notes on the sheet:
diffsmart v1.00: RS-422 receiver OR Pi-hosted smart controller, plus 12 V / 30 A pixel power distribution
Companion to difftx (FPP Remote pHAT). Cat5 in on J14; four WS2811 data outputs; twelve fused 12 V outputs.
RJ45 pairs (Falcon): port1 = 1(+)/2(-), port2 = 3(+)/6(-), port3 = 5(+)/4(-), port4 = 7(+)/8(-). difftx rev D has port 3 reversed.
J1 is the ONLY power inlet: 12 V 30 A straight from the supply. Q1-Q4 block a reversed supply; every
output is individually fused by an MF-R600 PPTC (6 A hold / 12 A trip) with a trip LED across it, and
F0, a Keystone 3557-2 ATO holder, fuses the whole board at 30 A. No marine fuse panel is needed.
No MCU: the fan thermostat and the over-temp LED are an NTC and one comparator. The two LM75s are
passengers on the I2C header and run from 3.3 V, the same rail the Pi's GPIO uses, so no level shifting is needed.
Data ports J2 (P1), J5 (P2), J8 (P3), J11 (P4). The eight INJ terminals feed power only:
their middle pole is a no-connect so an injection pigtail's data wire never becomes a stub on the string.
Terminal poles are silk marked + / D / - and read left to right in that order on both rows of the board.

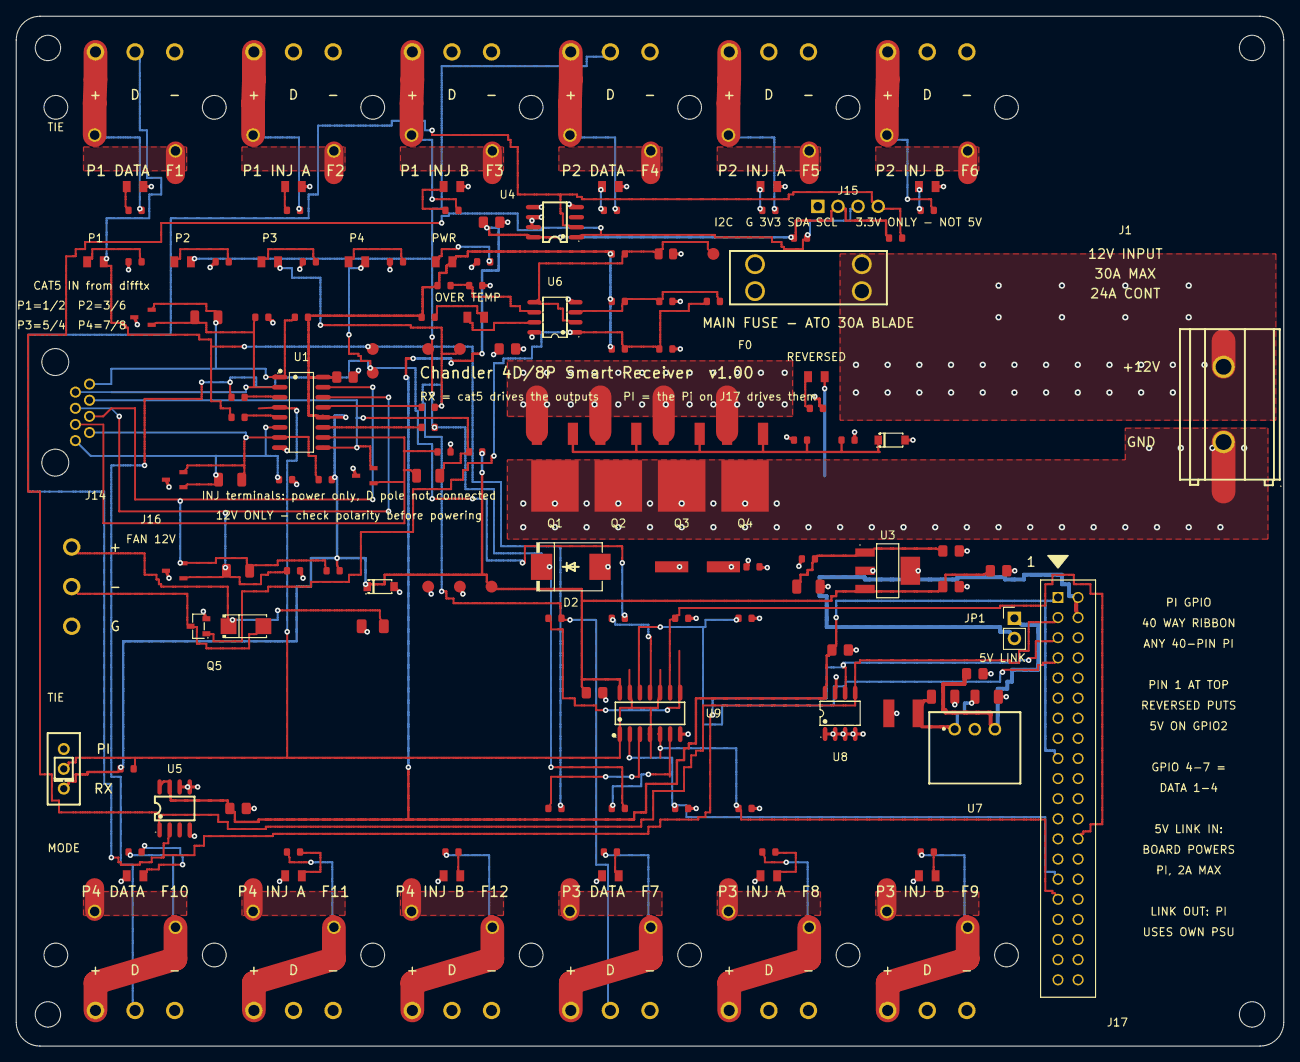
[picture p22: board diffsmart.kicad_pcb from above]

Board: 4 copper layers, 160.0 x 130.0 mm, 173 parts (0 on the bottom side), 76 nets.

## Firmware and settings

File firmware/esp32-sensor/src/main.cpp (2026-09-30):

// PixelPlus ESP32 sensor node (F20): motion sensors, buttons, beam breaks,
// contacts and an optional INA219/INA226 current sensor, reported to the
// PixelPlus show leader over authenticated UDP (docs/ARCHITECTURE.md §7.5,
// §12.16; firmware/esp32-sensor/README.md).
//
// States: no Wi-Fi → captive-portal hotspot "PixelPlus-Sensor-XXXX";
// on Wi-Fi, unadopted → beacons every 2 s until a leader adopts it (key
// exchange over HTTP); adopted → events + heartbeats to the leader, config
// fetched from the leader (signed both ways).

#include <Arduino.h>
#include <ArduinoJson.h>
#include <DNSServer.h>
#include <HTTPClient.h>
#include <Preferences.h>
#include <WebServer.h>
#include <WiFi.h>
#include <WiFiUdp.h>
#include <Wire.h>
#include <esp_system.h>
#if __has_include(<esp_random.h>)
#include <esp_random.h>
#endif

#include <string>
#include <vector>

#include "board.h"
#include "pp_debounce.h"
#include "pp_protocol.h"
#include "pp_x25519.h"

// ---------------------------------------------------------------------------
// State
// ---------------------------------------------------------------------------

struct Input {
  std::string id;
  std::string kind;  // motion | button | beam | contact | current
  uint8_t pin = 0;   // GPIO, or the I²C address for "current"
  bool activeLow = false;
  uint32_t debounceMs = 30;
  uint32_t holdMs = 0;
  float shuntMilliohms = 100.0f;
  pp::Debouncer deb;
  // current sensor
  bool ina226 = false;
  bool present = false;
  float amps = 0, volts = 0;
};

struct PendingEvent {
  std::string input;
  int state;
  uint32_t ms;
  uint64_t seq;
  uint8_t tries;
  uint32_t nextAt;
};

static Preferences prefs;
static WebServer http(80);
static DNSServer dns;
static WiFiUDP udp;

static std::string nodeId;   // "sn" + MAC tail
static std::string bootId;   // random per boot
static std::string name;     // friendly name
static uint64_t seq = 0;

// Adoption.
static std::string leaderId, leaderKey, leaderUrl;
static IPAddress leaderIp;
static uint16_t leaderHttpPort = 80, sensorPort = pp::kSensorPort;
static std::string leaderBoot;       // `lb` from the last sack
static int64_t timeOffset = 0;       // leader unix time - millis()/1000
static bool timeKnown = false;
static int64_t lastAuthTs = 0;       // newest accepted signed leader request
static uint64_t lastCmdSeq = 0;
static std::string lastCmdBoot;
static uint32_t adoptWindowUntil = 0;  // BOOT short press opens re-adoption

// Configuration from the leader.
static std::string cfgVersion;
static uint32_t statusEvery = 10;
static bool cfgFetchWanted = false;
static uint32_t cfgFetchAfter = 0;
static std::vector<Input> inputs;

static std::vector<PendingEvent> pending;
static bool portal = false;
static uint32_t identifyUntil = 0;
static uint32_t lastBeacon = 0, lastStatus = 0, lastInaRead = 0, lastWifiTry = 0;
static uint32_t eventsSent = 0, eventsLost = 0;

static bool adopted() { return !leaderKey.empty() && !leaderId.empty(); }

static int64_t leaderNow() { return (int64_t)(millis() / 1000) + timeOffset; }

// ---------------------------------------------------------------------------
// LED
// ---------------------------------------------------------------------------

static void led(uint8_t r, uint8_t g, uint8_t b) {
#if PP_LED_RGB
#if defined(ESP_ARDUINO_VERSION_MAJOR) && ESP_ARDUINO_VERSION_MAJOR >= 3
  rgbLedWrite(PP_PIN_LED, r / 8, g / 8, b / 8);
#else
  neopixelWrite(PP_PIN_LED, r / 8, g / 8, b / 8);
#endif
#else
  digitalWrite(PP_PIN_LED, (r | g | b) ? HIGH : LOW);
#endif
}

// Blink codes: identify = fast white; portal = slow blue; unadopted = amber
// pulse every 2 s; adopted = short green blink on each event.
static void ledTick() {
  uint32_t t = millis();
  if (t < identifyUntil) {
    (t / 120) % 2 ? led(255, 255, 255) : led(0, 0, 0);
  } else if (portal) {
    (t / 1000) % 2 ? led(0, 0, 255) : led(0, 0, 0);
  } else if (t < adoptWindowUntil) {
    (t / 250) % 2 ? led(255, 0, 255) : led(0, 0, 0);
  } else if (!adopted()) {
    (t % 2000) < 100 ? led(255, 120, 0) : led(0, 0, 0);
  } else {
    led(0, 0, 0);
  }
}

// ---------------------------------------------------------------------------
// Persistence (NVS)
// ---------------------------------------------------------------------------

static std::string getStr(const char* ns, const char* key) {
  prefs.begin(ns, true);
  String v = prefs.getString(key, "");
  prefs.end();
  return std::string(v.c_str());
}

static void putStr(const char* ns, const char* key, const std::string& v) {
  prefs.begin(ns, false);
  prefs.putString(key, v.c_str());
  prefs.end();
}

static void saveAdoption() {
  prefs.begin("adopt", false);
  prefs.putString("leader", leaderId.c_str());
  prefs.putString("key", leaderKey.c_str());
  prefs.putString("url", leaderUrl.c_str());
  prefs.putUShort("sport", sensorPort);
  prefs.putLong64("lts", lastAuthTs);
  prefs.end();
}

static void clearAdoption() {
  leaderId.clear();
  leaderKey.clear();
  leaderUrl.clear();
  leaderBoot.clear();
  cfgVersion.clear();
  pending.clear();
  prefs.begin("adopt", false);
  prefs.clear();
  prefs.end();
  prefs.begin("cfg", false);
  prefs.clear();
  prefs.end();
}

static void factoryReset() {
  Serial.println("Factory reset");
  for (const char* ns : {"adopt", "cfg", "wifi", "node"}) {
    prefs.begin(ns, false);
    prefs.clear();
    prefs.end();
  }
  delay(200);
  ESP.restart();
}

// ---------------------------------------------------------------------------
// Inputs
// ---------------------------------------------------------------------------

static uint16_t inaRead(uint8_t addr, uint8_t reg, bool* ok) {
  Wire.beginTransmission(addr);
  Wire.write(reg);
  if (Wire.endTransmission(false) != 0 || Wire.requestFrom((int)addr, 2) != 2) {
    *ok = false;
    return 0;
  }
  uint16_t hi = Wire.read(), lo = Wire.read();
  *ok = true;
  return (uint16_t)(hi << 8 | lo);
}

static void inaWrite(uint8_t addr, uint8_t reg, uint16_t v) {
  Wire.beginTransmission(addr);
  Wire.write(reg);
  Wire.write((uint8_t)(v >> 8));
  Wire.write((uint8_t)v);
  Wire.endTransmission();
}

static void inaProbe(Input& in) {
  Wire.beginTransmission(in.pin);
  in.present = Wire.endTransmission() == 0;
  if (!in.present) return;
  bool ok = false;
  uint16_t mfr = inaRead(in.pin, 0xFE, &ok);
  in.ina226 = ok && mfr == 0x5449;  // "TI"; the INA219 has no ID register
  if (in.ina226) {
    inaWrite(in.pin, 0x00, 0x4527);  // 16-sample average, 1.1 ms conversions, continuous
  } else {
    inaWrite(in.pin, 0x00, 0x399F);  // INA219 default: 32 V, ±320 mV, 12-bit
  }
}

static void inaMeasure(Input& in) {
  if (!in.present) {
    inaProbe(in);
    if (!in.present) return;
  }
  bool ok1 = false, ok2 = false;
  int16_t shunt = (int16_t)inaRead(in.pin, 0x01, &ok1);
  uint16_t bus = inaRead(in.pin, 0x02, &ok2);
  if (!ok1 || !ok2) {
    in.present = false;
    return;
  }
  float microVolts = in.ina226 ? shunt * 2.5f : shunt * 10.0f;
  float volts = in.ina226 ? bus * 1.25e-3f : (bus >> 3) * 4e-3f;
  float mohm = in.shuntMilliohms > 0.01f ? in.shuntMilliohms : 100.0f;
  // I = V / R = (µV · 1e-6) / (mΩ · 1e-3)
  float amps = microVolts / mohm * 1e-3f;
  // Light smoothing (readings every second, reported every 10 s).
  in.amps = in.amps == 0 ? amps : in.amps * 0.7f + amps * 0.3f;
  in.volts = volts;
}

static void applyInputs() {
  uint32_t now = millis();
  bool wire = false;
  for (auto& in : inputs) {
    if (in.kind == "current") {
      if (!wire) {
        Wire.begin(PP_PIN_SDA, PP_PIN_SCL);
        wire = true;
      }
      inaProbe(in);
      continue;
    }
    // PIRs drive their output (pull-down keeps a loose wire quiet); buttons,
    // contacts and open-collector beam receivers need a pull-up.
    pinMode(in.pin, in.kind == "motion" ? INPUT_PULLDOWN : INPUT_PULLUP);
    in.deb.configure(in.activeLow, in.debounceMs, in.holdMs);
    in.deb.reset(digitalRead(in.pin), now);
  }
}

static void defaultInputs() {
  inputs.clear();
  Input pir;
  pir.id = "pir1";
  pir.kind = "motion";
  pir.pin = PP_DEFAULT_PIR;
  inputs.push_back(pir);
  Input btn;
  btn.id = "btn1";
  btn.kind = "button";
  btn.pin = PP_DEFAULT_BTN;
  btn.activeLow = true;
  inputs.push_back(btn);
}

// Parse the leader's `/cluster/sensor-config/<id>` answer.
static bool loadConfigJson(const std::string& body) {
  JsonDocument doc;
  if (deserializeJson(doc, body)) return false;
  JsonArrayConst arr = doc["inputs"].as<JsonArrayConst>();
  if (arr.isNull()) return false;
  std::vector<Input> next;
  for (JsonObjectConst o : arr) {
    Input in;
    in.id = o["id"] | "";
    in.kind = o["kind"] | "button";
    in.pin = o["pin"] | 0;
    in.activeLow = o["activeLow"] | false;
    in.debounceMs = o["debounceMs"] | 30;
    in.holdMs = o["holdMs"] | 0;
    in.shuntMilliohms = o["shuntMilliohms"] | 100.0f;
    if (in.id.empty() || in.id.size() > 16) continue;
    if (in.kind != "current" && in.pin > 48) continue;
    next.push_back(in);
    if (next.size() >= 8) break;
  }
  inputs = next;
  cfgVersion = doc["version"] | "";
  statusEvery = doc["statusEverySec"] | 10;
  if (statusEvery < 2 || statusEvery > 300) statusEvery = 10;
  std::string n = doc["name"] | "";
  if (!n.empty()) name = n;
  applyInputs();
  return true;
}

// ---------------------------------------------------------------------------
// Messages
// ---------------------------------------------------------------------------

static void sendTo(const IPAddress& ip, uint16_t port, const std::string& data) {
  udp.beginPacket(ip, port);
  udp.write((const uint8_t*)data.data(), data.size());
  udp.endPacket();
}

static std::string inputIdsJson() {
  std::string s = "[";
  for (size_t i = 0; i < inputs.size(); i++) {
    if (i) s += ",";
    s += pp::jsonString(inputs[i].id);
  }
  return s + "]";
}

static void sendBeacon() {
  std::string m = "{\"t\":\"sbeacon\",\"id\":" + pp::jsonString(nodeId) +
                  ",\"name\":" + pp::jsonString(name) + ",\"hw\":\"" PP_HW "\",\"ver\":\"" PP_FW_VERSION
                  "\",\"http\":80,\"adoptedBy\":" +
                  (adopted() ? pp::jsonString(leaderId) : std::string("null")) +
                  ",\"inputs\":" + inputIdsJson() + ",\"proto\":" + std::to_string(pp::kProto) + "}";
  sendTo(IPAddress(255, 255, 255, 255), sensorPort, m);
}

static std::string fmtFloat(float v, int digits) {
  char b[24];
  snprintf(b, sizeof b, "%.*f", digits, (double)v);
  return b;
}

static void sendStatus() {
  if (!adopted()) return;
  std::string ins = "{", amps = "{", volts = "{";
  bool fi = true, fa = true;
  for (auto& in : inputs) {
    if (in.kind == "current") {
      if (!in.present) continue;
      amps += (fa ? "" : ",") + pp::jsonString(in.id) + ":" + fmtFloat(in.amps, 3);
      volts += (fa ? "" : ",") + pp::jsonString(in.id) + ":" + fmtFloat(in.volts, 2);
      fa = false;
    } else {
      ins += (fi ? "" : ",") + pp::jsonString(in.id) + ":" + std::to_string(in.deb.state());
      fi = false;
    }
  }
  ins += "}";
  amps += "}";
  volts += "}";
  std::string m = "{\"t\":\"sstatus\",\"id\":" + pp::jsonString(nodeId) +
                  ",\"rssi\":" + std::to_string(WiFi.RSSI()) +
                  ",\"uptime\":" + std::to_string(millis() / 1000) + ",\"ver\":\"" PP_FW_VERSION
                  "\",\"cfg\":" + pp::jsonString(cfgVersion) + ",\"inputs\":" + ins +
                  ",\"amps\":" + amps + ",\"volts\":" + volts + "}";
  sendTo(leaderIp, sensorPort, pp::seal(m, leaderKey, bootId, ++seq));
}

static void transmit(PendingEvent& e) {
  std::string m = "{\"t\":\"sevent\",\"id\":" + pp::jsonString(nodeId) +
                  ",\"input\":" + pp::jsonString(e.input) + ",\"state\":" + std::to_string(e.state) +
                  ",\"ms\":" + std::to_string(e.ms) + ",\"lb\":" + pp::jsonString(leaderBoot) + "}";
  sendTo(leaderIp, sensorPort, pp::seal(m, leaderKey, bootId, e.seq));
}

static void queueEvent(const std::string& input, int state) {
  if (!adopted()) return;
  if (pending.size() >= 16) {
    pending.erase(pending.begin());
    eventsLost++;
  }
  PendingEvent e{input, state, millis(), ++seq, 0, 0};
  transmit(e);
  e.tries = 1;
  e.nextAt = millis() + 100;
  pending.push_back(e);
  eventsSent++;
}

// Retries at 100, 200 and 400 ms.
static void retryEvents() {
  uint32_t now = millis();
  for (size_t i = 0; i < pending.size();) {
    PendingEvent& e = pending[i];
    if ((int32_t)(now - e.nextAt) >= 0) {
      if (e.tries >= 4) {
        eventsLost++;
        pending.erase(pending.begin() + i);
        continue;
      }
      transmit(e);
      e.nextAt = now + (100u << e.tries);
      e.tries++;
    }
    i++;
  }
}

static void handleSack(JsonDocument& doc) {
  std::string sb = doc["sb"] | "";
  if (sb != bootId || (doc["id"] | "") != nodeId) return;  // not an answer to this run
  uint64_t ack = doc["ack"].as<uint64_t>();
  bool ok = doc["ok"] | false;
  std::string lb = doc["lb"] | "";
  int64_t now = doc["now"].as<int64_t>();
  if (now > 1600000000) {
    timeOffset = now - (int64_t)(millis() / 1000);
    timeKnown = true;
  }
  if (!lb.empty() && lb != leaderBoot) leaderBoot = lb;
  std::string cfg = doc["cfg"] | "";
  if (!cfg.empty() && cfg != cfgVersion && !cfgFetchWanted) {
    cfgFetchWanted = true;
    cfgFetchAfter = millis();
  }
  for (size_t i = 0; i < pending.size(); i++) {
    if (pending[i].seq != ack) continue;
    if (ok) {
      pending.erase(pending.begin() + i);
    } else {
      // The leader restarted (new boot id): resend at once with the new one.
      PendingEvent e = pending[i];
      pending.erase(pending.begin() + i);
      e.seq = ++seq;
      e.tries = 1;
      e.nextAt = millis() + 100;
      transmit(e);
      pending.push_back(e);
    }
    break;
  }
}

static void handleCmd(JsonDocument& doc) {
  if ((doc["id"] | "") != nodeId) return;
  std::string bt = doc["bt"] | "";
  uint64_t sq = doc["sq"].as<uint64_t>();
  // Replay: the leader's current boot and a growing sequence number.
  if (bt.empty() || (bt == lastCmdBoot && sq <= lastCmdSeq)) return;
  if (!leaderBoot.empty() && bt != leaderBoot) return;
  lastCmdBoot = bt;
  lastCmdSeq = sq;
  std::string cmd = doc["cmd"] | "";
  if (cmd == "identify") identifyUntil = millis() + 8000;
}

static void pollUdp() {
  int n = udp.parsePacket();
  if (n <= 0) return;
  if (n > 2048) {
    udp.flush();
    return;
  }
  std::string buf(n, '\0');
  udp.read((uint8_t*)&buf[0], n);
  if (!adopted() || !(udp.remoteIP() == leaderIp)) return;
  if (!pp::verify(buf, leaderKey)) return;
  JsonDocument doc;
  if (deserializeJson(doc, buf)) return;
  std::string t = doc["t"] | "";
  if (t == "sack") handleSack(doc);
  if (t == "scmd") handleCmd(doc);
}

// ---------------------------------------------------------------------------
// Leader HTTP (configuration)
// ---------------------------------------------------------------------------

static std::string randomHex(size_t bytes) {
  std::vector<uint8_t> b(bytes);
  esp_fill_random(b.data(), b.size());
  return pp::hex(b.data(), b.size());
}

// GET <leader>/api/v1/cluster/sensor-config/<id>, signed with our key; the
// answer must carry X-PixelPlus-Reply for our nonce. A 401 with our clock
// off comes with the leader's time (MACed), and we retry once.
static bool fetchConfig() {
  std::string path = "/api/v1/cluster/sensor-config/" + nodeId;
  for (int attempt = 0; attempt < 2; attempt++) {
    std::string nonce = randomHex(16);
    int64_t ts = timeKnown ? leaderNow() : 0;
    std::string auth = pp::signRequest(leaderKey, nodeId, "GET", path, ts, nonce, "");
    HTTPClient c;
    c.setTimeout(5000);
    std::string url = "http://" + std::string(leaderIp.toString().c_str()) + ":" +
                      std::to_string(leaderHttpPort) + path;
    if (!c.begin(url.c_str())) return false;
    c.addHeader("X-PixelPlus-Auth", auth.c_str());
    c.addHeader("X-PixelPlus-Request", "1");
    const char* keep[] = {"X-PixelPlus-Reply", "X-PixelPlus-Time"};
    c.collectHeaders(keep, 2);
    int code = c.GET();
    if (code == 200) {
      std::string body = c.getString().c_str();
      std::string reply = c.header("X-PixelPlus-Reply").c_str();
      c.end();
      if (!pp::ctEqual(reply, pp::replyMac(leaderKey, nonce, pp::sha256Hex(body)))) return false;
      if (!loadConfigJson(body)) return false;
      putStr("cfg", "json", body);
      Serial.printf("Config %s: %u inputs\n", cfgVersion.c_str(), (unsigned)inputs.size());
      return true;
    }
    std::string hint = c.header("X-PixelPlus-Time").c_str();
    c.end();
    int64_t now = 0;
    if (code == 401 && !hint.empty() && pp::verifyTimeProof(leaderKey, hint, nonce, &now)) {
      timeOffset = now - (int64_t)(millis() / 1000);
      timeKnown = true;
      continue;
    }
    Serial.printf("Config fetch failed: HTTP %d\n", code);
    return false;
  }
  return false;
}

// ---------------------------------------------------------------------------
// Local HTTP: adoption, release, info, Wi-Fi setup
// ---------------------------------------------------------------------------

static bool parseLeaderUrl(const std::string& url) {
  // http://<ipv4>:<port>
  if (url.rfind("http://", 0) != 0) return false;
  std::string rest = url.substr(7);
  size_t colon = rest.find(':');
  std::string host = rest.substr(0, colon);
  uint16_t port = 80;
  if (colon != std::string::npos) port = (uint16_t)atoi(rest.substr(colon + 1).c_str());
  IPAddress ip;
  if (!ip.fromString(host.c_str()) || port == 0) return false;
  leaderIp = ip;
  leaderHttpPort = port;
  return true;
}

static void sendJson(int code, const std::string& body) {
  http.send(code, "application/json", body.c_str());
}

static void handleInfo() {
  std::string m = "{\"id\":" + pp::jsonString(nodeId) + ",\"name\":" + pp::jsonString(name) +
                  ",\"hw\":\"" PP_HW "\",\"ver\":\"" PP_FW_VERSION "\",\"adoptedBy\":" +
                  (adopted() ? pp::jsonString(leaderId) : std::string("null")) +
                  ",\"inputs\":" + inputIdsJson() + ",\"proto\":" + std::to_string(pp::kProto) +
                  ",\"eventsSent\":" + std::to_string(eventsSent) +
                  ",\"eventsLost\":" + std::to_string(eventsLost) + "}";
  sendJson(200, m);
}

// Check a request signed by our leader (re-adoption, release).
static bool leaderSigned(const std::string& method, const std::string& path, const std::string& body) {
  if (!adopted() || !http.hasHeader("X-PixelPlus-Auth")) return false;
  std::string sender, nonce;
  int64_t ts = 0;
  if (!pp::verifyRequest(http.header("X-PixelPlus-Auth").c_str(), leaderKey, method, path, body,
                         &sender, &ts, &nonce))
    return false;
  if (sender != leaderId || ts <= lastAuthTs) return false;  // monotonic: no replays
  if (timeKnown && llabs(ts - leaderNow()) > 300) return false;
  lastAuthTs = ts;
  return true;
}
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
void loop() {
  uint32_t now = millis();
  http.handleClient();
  if (portal) dns.processNextRequest();
  pollBootButton();
  ledTick();

  // Leave the hotspot once the saved Wi-Fi works again; retry every minute.
  if (portal && now - lastWifiTry > 60000) {
    lastWifiTry = now;
    if (connectWifi(8000)) {
      dns.stop();
      WiFi.softAPdisconnect(true);
      WiFi.mode(WIFI_STA);
      portal = false;
      Serial.printf("Connected: %s\n", WiFi.localIP().toString().c_str());
    }
  }
  if (!portal && WiFi.status() != WL_CONNECTED) {
    static uint32_t lostSince = 0;
    if (!lostSince) lostSince = now;
    if (now - lostSince > 120000) {
      lostSince = 0;
      startPortal();  // Wi-Fi gone for 2 minutes: offer setup (keeps retrying)
    }
    delay(10);
    return;
  }

  // Inputs (every 5 ms) and the current sensor (every second).
  static uint32_t lastPoll = 0;
  if (now - lastPoll >= 5) {
    lastPoll = now;
    for (auto& in : inputs) {
      if (in.kind == "current") continue;
      if (in.deb.update(digitalRead(in.pin), now)) {
        Serial.printf("%s → %d\n", in.id.c_str(), in.deb.state());
        queueEvent(in.id, in.deb.state());
        if (in.deb.state() && adopted()) identifyUntil = max(identifyUntil, now + 150);
      }
    }
  }
  if (now - lastInaRead >= 1000) {
    lastInaRead = now;
    for (auto& in : inputs)
      if (in.kind == "current") inaMeasure(in);
  }

  pollUdp();
  retryEvents();

  uint32_t beaconEvery = adopted() ? 10000 : 2000;
  if (!portal && now - lastBeacon >= beaconEvery) {
    lastBeacon = now;
    sendBeacon();
  }
  if (adopted() && (lastStatus == 0 || now - lastStatus >= statusEvery * 1000)) {
    lastStatus = now;
    sendStatus();
  }
  if (adopted() && cfgFetchWanted && (int32_t)(now - cfgFetchAfter) >= 0) {
    cfgFetchWanted = false;
    if (!fetchConfig()) {
      cfgFetchWanted = true;
      cfgFetchAfter = now + 30000;
    }
  }
  delay(1);
}

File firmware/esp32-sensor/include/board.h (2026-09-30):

// Board pin defaults. Inputs and their pins come from the leader after
// adoption (Settings → Sensors); these are only the defaults a fresh node
// announces, and the I²C pins used for an INA219/INA226 current sensor.
#pragma once

#if defined(PP_BOARD_C3)
#define PP_HW "esp32c3"
#define PP_PIN_BOOT 9      // BOOT button (hold 10 s: factory reset)
#define PP_PIN_LED 8       // on-board WS2812 on the DevKitM-1
#define PP_LED_RGB 1
#define PP_PIN_SDA 1
#define PP_PIN_SCL 3
#define PP_DEFAULT_PIR 4
#define PP_DEFAULT_BTN 5
#define PP_DEFAULT_BEAM 7
#elif defined(PP_BOARD_S3)
#define PP_HW "esp32s3"
#define PP_PIN_BOOT 0
#define PP_PIN_LED 48      // WS2812 (v1.0 boards; v1.1 uses 38)
#define PP_LED_RGB 1
#define PP_PIN_SDA 8
#define PP_PIN_SCL 9
#define PP_DEFAULT_PIR 4
#define PP_DEFAULT_BTN 5
#define PP_DEFAULT_BEAM 6
#else  // classic ESP32 DevKit
#define PP_HW "esp32"
#define PP_PIN_BOOT 0
#define PP_PIN_LED 2
#define PP_LED_RGB 0
#define PP_PIN_SDA 21
#define PP_PIN_SCL 22
#define PP_DEFAULT_PIR 27
#define PP_DEFAULT_BTN 26
#define PP_DEFAULT_BEAM 25
#endif

#ifndef PP_FW_VERSION
#define PP_FW_VERSION "0.1.0"
#endif

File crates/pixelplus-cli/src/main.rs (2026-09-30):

//! `pixelplus` — administration and bring-up tool for PixelPlus controllers.

mod args;
mod cmd;
mod http;
mod hwctx;
mod style;

use args::BoardArg;
use clap::{Parser, Subcommand};
use hwctx::HwContext;
use std::process::ExitCode;

const AFTER_HELP: &str = "\
Examples:
  pixelplus detect                                   identify board, Pi and sensors
  pixelplus eeprom write --board difftx --rev E      program a new board's EEPROM
  pixelplus config-txt --board difftxlarge --pixels 1600
  pixelplus test-output --pattern chase --color red --seconds 30
  pixelplus test-output --pattern scope --scope zeros --output 1
  pixelplus doctor

On a PC, add --simulate <board> to try any command against a simulated board.";

/// PixelPlus controller administration and bring-up.
#[derive(Debug, Parser)]
#[command(
    name = "pixelplus",
    version,
    about = "PixelPlus controller administration and bring-up",
    after_help = AFTER_HELP,
    propagate_version = true
)]
struct Cli {
    /// Use a simulated board instead of the real I2C bus and pins.
    #[arg(
        long,
        global = true,
        value_enum,
        value_name = "BOARD",
        env = "PIXELPLUS_SIMULATE"
    )]
    simulate: Option<BoardArg>,

    /// Print machine-readable JSON instead of text (where supported).
    #[arg(long, global = true)]
    json: bool,

    #[command(subcommand)]
    command: Command,
}

#[derive(Debug, Subcommand)]
enum Command {
    /// Read, write or erase the board identity EEPROM.
    #[command(subcommand)]
    Eeprom(cmd::eeprom::EepromCmd),

    /// Identify the board and Raspberry Pi, and read every sensor.
    Detect,

    /// Drive test patterns straight to the pixel outputs (no daemon needed).
    ///
    /// Stop pixelplusd first (`sudo systemctl stop pixelplusd`): only one
    /// program can own the display output.
    TestOutput(cmd::test_output::TestOutputArgs),

    /// Print the /boot/firmware/config.txt fragment for a board.
    ConfigTxt(cmd::config_txt::ConfigTxtArgs),

    /// Show what the local pixelplusd is doing.
    Status(cmd::status::StatusArgs),

    /// Check the system for problems (overlay, I2C, sensors, audio, disk, time).
    Doctor(cmd::doctor::DoctorArgs),

    /// Switch the pixel pins to DPI or park them low (used by the systemd unit).
    Pins(cmd::pins::PinsArgs),
}

fn main() -> ExitCode {
    let cli = Cli::parse();
    let ctx = HwContext {
        simulate: cli.simulate.map(Into::into),
    };
    let json = cli.json;
    let result = match cli.command {
        Command::Eeprom(c) => cmd::eeprom::run(&ctx, c, json),
        Command::Detect => cmd::detect::run(&ctx, json),
        Command::TestOutput(a) => cmd::test_output::run(&ctx, a, json),
        Command::ConfigTxt(a) => cmd::config_txt::run(&ctx, a),
        Command::Status(a) => cmd::status::run(a, json),
        Command::Doctor(a) => cmd::doctor::run(&ctx, a, json),
        Command::Pins(a) => cmd::pins::run(&ctx, a),
    };
    match result {
        Ok(()) => ExitCode::SUCCESS,
        Err(e) => {
            anstream::eprintln!(
                "{} {}",
                style::paint(style::FAIL, "error:"),
                error_chain(&e)
            );
            ExitCode::FAILURE
        }
    }
}

/// `a: b: c` like `{:#}`, but without repeating a cause whose text the previous
/// message already ends with (hardware errors embed their OS error).
pub fn error_chain(e: &anyhow::Error) -> String {
    let mut out = String::new();
    for cause in e.chain() {
        let text = cause.to_string();
        if out.ends_with(&text) {
            continue;
        }
        if !out.is_empty() {
            out.push_str(": ");
        }
        out.push_str(&text);
    }
    out
}

#[cfg(test)]
mod tests {
    use super::*;
    use clap::CommandFactory;

    #[test]
    fn error_chain_skips_repeats() {
        let io = std::io::Error::new(std::io::ErrorKind::NotFound, "No such file");
        let e = anyhow::Error::new(io).context("opening /dev/i2c-1: No such file");
        assert_eq!(error_chain(&e), "opening /dev/i2c-1: No such file");
        let e = anyhow::anyhow!("inner").context("outer");
        assert_eq!(error_chain(&e), "outer: inner");
    }

    /// firstboot (image/firstboot/firstboot.py) runs exactly these command lines.
    #[test]
    fn firstboot_contract_parses() {
        for argv in [
            vec!["pixelplus", "--json", "detect"],
            vec!["pixelplus", "config-txt", "--board", "difftxlarge"],
            vec![
                "pixelplus",
                "config-txt",
                "--board",
                "bare-pi",
                "--pixels",
                "1600",
            ],
            vec!["pixelplus", "pins", "release"],
        ] {
            Cli::try_parse_from(&argv).unwrap_or_else(|e| panic!("{argv:?}: {e}"));
        }
    }

    #[test]
    fn cli_definition_is_valid() {
        Cli::command().debug_assert();
    }

    #[test]
    fn parses_examples() {
        let ok = [
            "pixelplus detect",
            "pixelplus --json detect",
            "pixelplus eeprom read --hex",
            "pixelplus eeprom write --board difftx --rev E --yes",
            "pixelplus eeprom erase --full -y",
            "pixelplus config-txt --board difftxlarge --pi pi5 --pixels 1600",
            "pixelplus config-txt --board difftx --fps 40",
            "pixelplus test-output --board difftx --pattern scope --scope identify --seconds 0 --sim",
            "pixelplus test-output --pattern solid --color '#ff8000' --order grb --output 2",
            "pixelplus --simulate difftxlarge doctor",
            "pixelplus status --url http://pi.local:8080",
            "pixelplus pins release --board difftxlarge",
        ];
        for line in ok {
            let argv: Vec<String> = line
                .split(' ')
                .map(|s| s.trim_matches('\'').to_string())
                .collect();
            Cli::try_parse_from(&argv).unwrap_or_else(|e| panic!("{line}: {e}"));
        }
        let bad = [
            "pixelplus config-txt --board difftx --pixels 10 --fps 40",
            "pixelplus test-output --brightness 101",
            "pixelplus test-output --color purple-ish",
            "pixelplus eeprom write --board toaster --rev A",
        ];
        for line in bad {
            let argv: Vec<&str> = line.split(' ').collect();
            assert!(Cli::try_parse_from(argv).is_err(), "{line} should fail");
        }
    }
}

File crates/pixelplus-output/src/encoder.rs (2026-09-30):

//! WS281x → DPI framebuffer encoder.
//!
//! The framebuffer is **XRGB8888**: one little-endian `u32` per DPI pixel whose
//! bit *n* (0..=23) appears on DPI_D*n* = GPIO *n + 4*; bits 24..=31 are unused.
//!
//! ## Line layout
//!
//! Line *y* carries LED *y* of every output: 24 WS281x bits, MSB of the first
//! wire byte first, each `px_per_bit` pixels wide (see [`BitTiming`]).
//!
//! **Direct mode** (difftx, diffsmart), per bit:
//!
//! ```text
//! px 0 .. T0H        active mask   (every output that still has data goes high)
//! px T0H .. T1H      data word     (only outputs sending a 1 stay high)
//! px T1H .. bit end  0             (static: written once per buffer)
//! ```
//!
//! **Latched mode** (difftxlarge), per bit and per bank *b*, three latch time
//! slots of [`LATCH_SLOT_PX`] pixels at the three bit edges, offset `4 b`:
//!
//! ```text
//! edge 0    (px 4b ..)        mask | LE_b on the middle two pixels
//! edge T0H  (px T0H + 4b ..)  data | LE_b on the middle two pixels
//! edge T1H  (px T1H + 4b ..)  0    | LE_b on the middle two pixels  (static)
//! ```
//!
//! A 74AHCT573 is transparent while LE is high, so bank *b*'s outputs change
//! at pixel `edge + 4b + 1`. Every edge of a bank moves by the same offset, so
//! high times are exactly T0H / T1H on every bank; banks are merely skewed by
//! 104 ns from each other, which WS281x strings do not care about.
//!
//! ## Latch alignment ("bottom-aligned" strings, experimental)
//!
//! By default every output's data starts at line 0, so a string of *L* LEDs
//! latches (shows its new colours) about `L × line + reset` after scan-out
//! starts: strings of different lengths change at different times (up to
//! 49 ms apart at 1600 LEDs). With [`WsEncoder::set_bottom_align`] output *k*
//! starts at line `N − L_k` instead, where *N* is the longest output of the
//! frame; the leading low lines are just a longer reset, and every string
//! latches at `N × line + reset`. Must be validated on real pixels (see
//! `DESIGN.md`, bring-up checklist).
//!
//! ## Speed
//!
//! Eight outputs' bytes are packed into a `u64` and bit-transposed with three
//! delta swaps, giving eight "one bit of every output" bytes at once; a
//! per-group 256-entry table then scatters those bytes onto the board's DPI
//! bits. Static regions are written only when a buffer is first used
//! ([`BufferState`]), so a steady-state frame writes 28 of 48 pixels per bit in
//! direct mode and 24 of 48 in latched mode.

use crate::error::{OutputError, Result};
use crate::frame::OutputFrameRef;
use crate::layout::{OutputLayout, OutputMode};
use crate::timing::{BitTiming, DpiGeometry, BITS_PER_LED, LATCH_SLOT_PX};
use serde::Serialize;
use std::sync::atomic::{AtomicU64, Ordering};

static NEXT_ENCODER_ID: AtomicU64 = AtomicU64::new(1);

/// Transpose an 8×8 bit matrix stored row-major in a `u64`
/// (row *r* = byte *r*, column *c* = bit *c* of that byte).
///
/// After the call, bit *i* of byte *j* equals bit *j* of input byte *i*.
#[inline(always)]
pub fn transpose8(mut x: u64) -> u64 {
    let t = (x ^ (x >> 7)) & 0x00AA_00AA_00AA_00AA;
    x ^= t ^ (t << 7);
    let t = (x ^ (x >> 14)) & 0x0000_CCCC_0000_CCCC;
    x ^= t ^ (t << 14);
    let t = (x ^ (x >> 28)) & 0x0000_0000_F0F0_F0F0;
    x ^= t ^ (t << 28);
    x
}

/// A mutable view of a mapped framebuffer, in 32-bit pixels.
#[derive(Debug)]
pub struct FrameBufferMut<'a> {
    words: &'a mut [u32],
    width: usize,
    height: usize,
    stride: usize,
}
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

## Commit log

2026-09-30 Board information
    [diffrx-B_Cu.gbl, diffrx-B_Mask.gbs, diffrx-B_Paste.gbp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]
2026-09-30 Spec: overlays, games, DJ voices, matrix props
    Claude-Session: https://claude.ai/code/session_01FBv1mrgWpmeAiXsWuRe44b
2026-09-30 Games: port fpp-mariobros to a PixelPlus sidecar (Mario + NES arcade on matrix props)
    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
2026-09-30 Core data path: fseq, ppseq slices, xLights import, frame mapping, power estimates, layout
    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
    [config-pixelplus.txt]
2026-09-30 Pixel output (original DPI WS281x encoder, latch banks, DRM/KMS), hardware support, pixelplus CLI
    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
2026-09-30 Web UI: SvelteKit studio interface, setup wizard, demo mode, public request page
    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
    [config-pixelplus.txt, windows-app-manifest.xml]
2026-09-30 Daemon services: system/setup, uploads, xLights import, snapshots, health, alerts, MQTT, sensors, TTS, games, requests; log layer
    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
2026-09-30 Output/hw review fixes: latch init frame, CRTC colour mgmt reset, INA226 stale read, debouncer, OLED probe, RTC EOSC, bring-up checklist
    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
    [board.rs, encoder.rs, gpio.rs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]
2026-09-30 xLights: per-string (Advanced) start channels via Prop.channelRuns, skip inactive models, drop unknown controller types
    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
2026-09-30 End-to-end QA: dev cluster script, 28-step e2e scenario, real-daemon Playwright suite, contract check, debug output tap; 13 bug fixes found running the real 3-node cluster
    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
    [params.rs]
2026-09-30 Web UI polish from UX review: plain-language naming, phone-first layouts, autosave+undo, WCAG AA contrast, first-run checklist, lights-off banner, song-request radio/public URL/yard sign, units setti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
2026-09-30 Precise sync: continuous follower servo, µs anchors, 4-timestamp pings with kernel RX stamps, offset+drift clock model, vblank-paced presentation-time frame selection, audio output delay + calibratio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
    [encoder.rs]
2026-09-30 WS1: local CA + HTTPS listener, public-only listener with games proxy, phone mic+camera sound-sync calibration, trust page; games controller uses relative WS path for tunnels
    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
2026-09-30 WS6: nightly health reports, season profiles, xLights FPP Connect upload compatibility + watch folder, ESP32 sensor nodes + firmware
    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
2026-09-30 WS4: camera yard mapping with blink codes, pixel-count detection, guided receiver wizard, replacement UI embed
    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
2026-09-30 WS3: countdown/show-start moment, power limiter + late-night dimming, sensor surprise layer, engine wiring for calibration v2, mapping, smart playlists, seasons, beat params, journal
    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
2026-09-30 WIP: integration pass (interrupted by container restart)
    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
